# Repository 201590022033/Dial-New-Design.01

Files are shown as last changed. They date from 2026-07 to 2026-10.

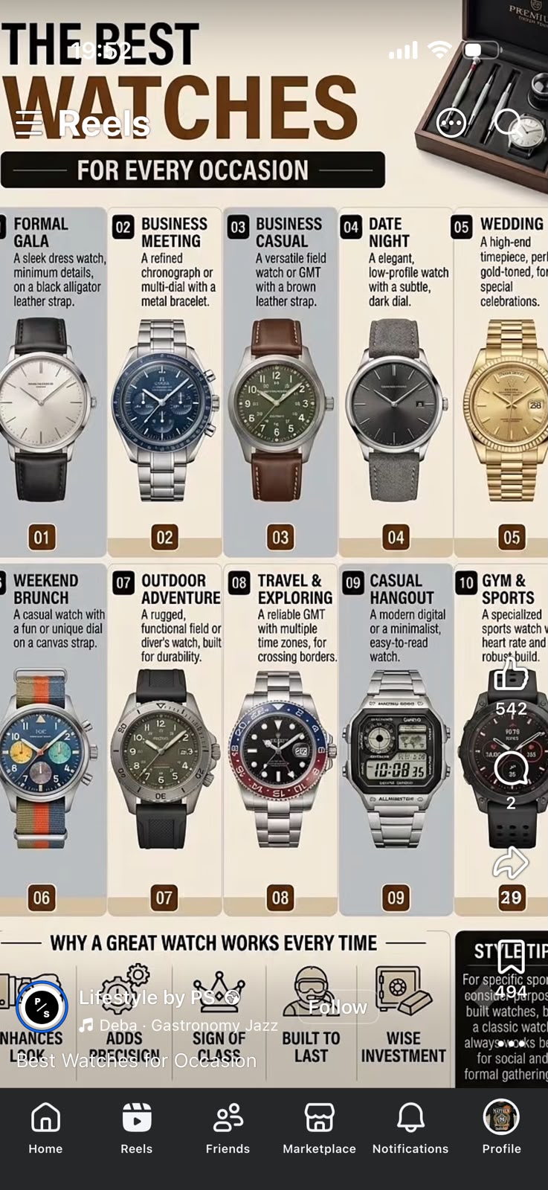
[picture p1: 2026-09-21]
docs/reference-components/2026-09-20-social-reference/WhatsApp Image 2026-09-20 at 14.32.59 (1).jpeg

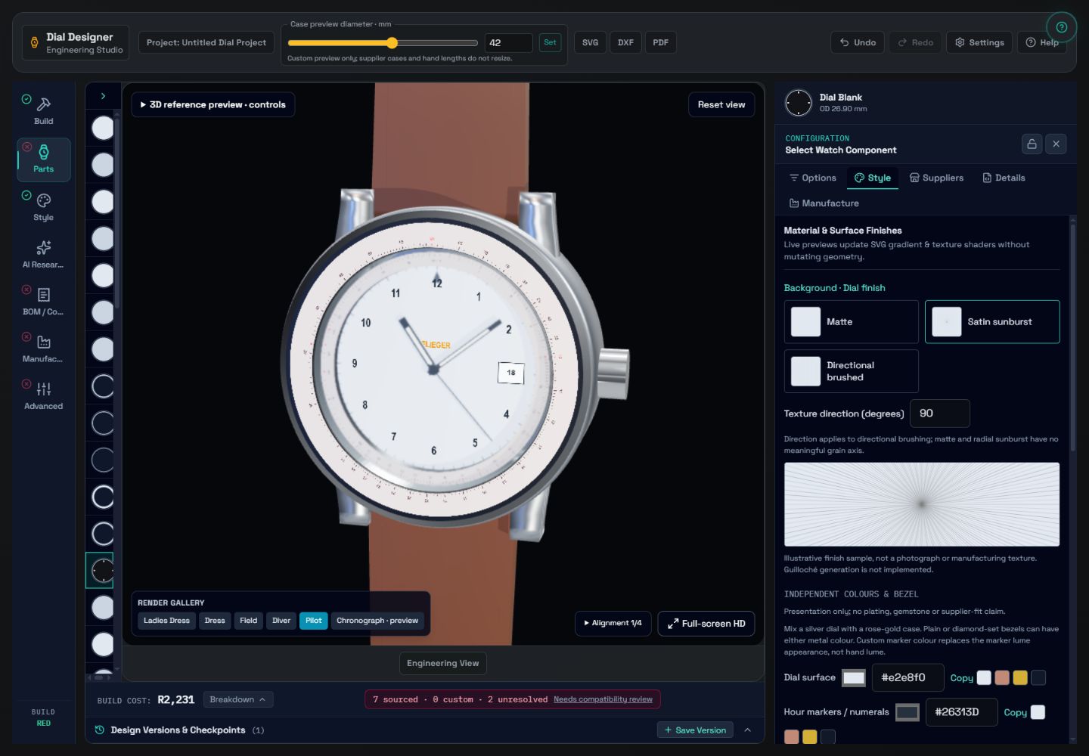
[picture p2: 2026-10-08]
docs/research/slide-rules/acceptance/m4-repair-hd-silver-2026-10-08.jpg

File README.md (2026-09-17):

# Dial Designer v0.3

## Version 3 – Professional Watch Engineering Studio

Production-ready engineering workspace for custom watch dial design with strict geometry, scale plugins, manufacturing validation, and export workflows.

## Stack

- React 19
- TypeScript (strict)
- Vite
- Tailwind CSS
- Zustand
- SVG.js
- React Hook Form + Zod
- Framer Motion
- React DnD
- Lucide React
- ESLint + Prettier

## Architecture Principles

1. Parametric geometry only.
2. Global case diameter is the master dimension.
3. Bands are concentric donuts.
4. Band Registry is the source of truth.
5. SVG is the authoritative renderer.
6. UI, rendering, and domain logic are separated.

## Production Features

- Watch Design Engine: dial face, texture, typography, marker, chapter ring, bezel, lume, template systems.
- Engineering Export Engine: SVG, DXF, PDF, PNG from engineering geometry.
- Export targets: entire project, dial face, chapter ring, inner bezel, outer bezel, selected band, manufacturing package.
- Export Preview: preview image, layers, dimensions, warnings, estimated process sizes, file size summary.
- Native project files: `.dial` (versioned, JSON-based) with autosave and recent project support.
- Manufacturing validation and collision detection integrated into inspector/status/export preview.
- Traceable manufacturing rules classify guidance as verified manufacturer capability, industry best practice, or engineering assumption.
- Supplier profile library provides data-driven manufacturing capability presets for print-, applied-, and instrument-oriented dial programs.
- Design Advisor highlights authenticity, geometry, beauty, and manufacturability recommendations from the current dial state.
- Movement recommendations for production-safe dial and bezel sizing guidance.

## Project Structure

- src/app: App composition and shell
- src/components/layout: Main layout regions
- src/features: Feature placeholders and extension surfaces
- src/stores: Zustand stores (global settings, selection, bands, history, viewport, export)
- src/renderer: SVG renderer abstraction + interaction services
- src/domain: Band registry, movement library, extension catalog
- src/services: Export and movement service layer
- src/hooks: Reusable hooks including resize observer and validation
- src/utils: Math and id utilities
- src/tests: Bootstrap tests

## Layout

- Top toolbar
- Left bands panel
- Center SVG canvas
- Right inspector and feature stack
- Bottom status bar

## Project Workflow

- New/Open/Save/Save As
- Import/Export project payloads
- Autosave snapshots
- Recent projects index
- Undo/Redo snapshot hooks
- Project information and settings dialog

## Run

```bash
npm install
npm run dev
```

## Quality Checks

```bash
npm run typecheck
npm run lint
npm run build
```

## Documentation

- [Architecture Guide](docs/ARCHITECTURE.md)
- [Developer Guide](docs/DEVELOPER_GUIDE.md)
- [Plugin Guide](docs/PLUGIN_GUIDE.md)
- [Manufacturing Guide](docs/MANUFACTURING_GUIDE.md)
- [Scale Guide](docs/SCALE_GUIDE.md)
- [Movement Guide](docs/MOVEMENT_GUIDE.md)
- [Project File Format](docs/PROJECT_FILE_FORMAT.md)
- [Watch Design Guidelines](WATCH_DESIGN_GUIDELINES.md)
- [Manufacturing Rules](MANUFACTURING_RULES.md)
- [Supplier Profile Library](SUPPLIER_PROFILE_LIBRARY.md)
- [Design Advisor](DESIGN_ADVISOR.md)
- [Asset Library Architecture](ASSET_LIBRARY_ARCHITECTURE.md)
- [Parametric 3D Roadmap](docs/ROADMAP.md)
- [ADR 0001: Parametric 3D Geometry](docs/adr/0001-parametric-3d-geometry.md)

## Current Status

- Core geometry, scale, design, export, and project persistence systems are operational.
- Strict TypeScript, linting, and tests are enforced.
- Manufacturing intelligence now includes traceable rules, supplier archetypes, and contextual design recommendations without redesigning the frozen architecture.
- Additional plugin surfaces are scaffolded for advanced watchmaking extensions.

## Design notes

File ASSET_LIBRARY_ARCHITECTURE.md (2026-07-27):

# Asset Library Architecture

## Version 3 Intent

Version 3 shifts differentiation from framework construction to professional watchmaking knowledge encoded as reusable assets.

The framework remains stable.

The asset libraries become the primary source of domain value.

## Frozen Systems

The following systems remain unchanged and are consumed as-is:

- Projection and profile infrastructure
- Mathematical engines
- Scale plugin framework
- Renderer and SVG pipeline
- Manufacturing validation framework
- Intelligent layout engine
- Export pipeline
- Watch component registry
- Object inspector architecture
- Zustand store architecture

## New Knowledge Layers

Data-driven libraries are stored in [src/domain/asset-library/data](src/domain/asset-library/data):

- scaleAssets.json
- chapterRingAssets.json
- markerAssets.json
- handAssets.json
- materialAssets.json
- typographyAssets.json
- manufacturingRules.json
- supplierProfiles.json

These datasets are loaded by typed adapters in [src/domain/asset-library/loaders.ts](src/domain/asset-library/loaders.ts).

## Integration Pattern

1. Asset data defines authentic watchmaking semantics.
2. Loaders expose typed objects to services.
3. Services map assets to existing framework contracts.
4. Existing stores and UI consume service outputs.
5. Export and validation report traceable manufacturing evidence.

No mathematical engine duplication is introduced.

## Manufacturing Intelligence Integration

Manufacturing rules and supplier profiles are separate from application logic.

Rules include:

- stable rule id
- source classification
- supplier category linkage
- confidence level
- configurable thresholds
- revision and version

Runtime validation attaches this metadata to warnings so exported diagnostics are explainable.

## Advisor Integration

The design advisor reads:

- current design-engine state
- manufacturing warnings
- typography presets
- supplier profiles

It emits actionable recommendations grouped across authenticity, geometry, manufacturability, and visual quality.

## Extensibility

Adding a new profile or asset should be data-first:

1. Add entry to the relevant JSON library.
2. Reuse existing loader and service interfaces.
3. Add tests for expected behavior.

Framework APIs should only change for verified defects.

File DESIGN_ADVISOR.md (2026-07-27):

# Design Advisor

## Mission

The Design Advisor acts as a professional engineering assistant built on top of the frozen framework.

It does not replace mathematical engines.

It interprets design state, asset metadata, and manufacturing warnings to provide contextual recommendations.

## Inputs

The advisor currently evaluates:

- selected scale characteristics,
- dial and chapter ring configuration,
- marker strategy,
- typography profile compatibility,
- manufacturing warning trace metadata,
- supplier profile capability data.

## Recommendation Classes

Recommendations are grouped by:

- authenticity,
- manufacturability,
- geometry,
- beauty.

Severity is communicated as info, opportunity, or warning.

## Example Behaviors

- Detects texture and dense-scale competition.
- Suggests chapter-ring width increases when typography is constrained.
- Flags typography below profile-specific printable minima.
- Advises when applied marker strategy mismatches supplier capability.
- Highlights multilayer risk for single-level supplier profiles.

## Why-first Output Style

Each recommendation should contain:

- what is wrong,
- why it matters,
- how to improve it.

The advisor should never degrade to unexplained pass/fail states.

## Data Coupling

Advisor quality depends on asset-library breadth:

- scale assets
- chapter ring assets
- marker assets
- hand assets
- material assets
- typography assets
- manufacturing rules
- supplier profiles

As those libraries grow, advisor recommendations become more specific without changing framework APIs.

## Future Growth

Next modules should add:

- hand-to-marker style compatibility scoring,
- logo complexity and process guidance,
- movement-aware complication placement,
- scale-family-specific authenticity scoring,
- supplier cost/volume trade-off suggestions.

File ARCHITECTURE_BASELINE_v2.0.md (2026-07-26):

# Architecture Baseline v2.0

## Status
Architecture Version: 2.0 Stable

Effective immediately, the platform architecture is frozen for feature development.

Changes to frozen systems are allowed only for verified defects.
No feature ECR may modify frozen internals.

## Frozen Systems
- Projection Engine
- Projection Registry
- Projection Profiles
- Formatter Engine
- General Mathematical Framework
- Slide Rule Engine
- Scale Plugin Framework
- Manufacturing Framework
- Collision Framework
- Intelligent Layout Framework
- Renderer
- SVG Pipeline
- Export Pipeline
- Watch Component Registry
- Object Inspector Framework
- Engineering Validation Engine
- Zustand Store Architecture

## Freeze Rules
- New functionality must be implemented by composition of Projection + Engineering Profile + Formatter.
- No feature work may add scale-specific mathematical engines inside plugins.
- Plugins are orchestration only.
- Renderer, export, manufacturing, and stores remain unchanged unless fixing a verified defect.

## Defect Exception Policy
A frozen subsystem may be changed only when all conditions are met:
1. A reproducible defect exists in current behavior.
2. The defect cannot be resolved in profile/formatter/preset composition.
3. The change is minimized and accompanied by targeted regression tests.

## Architectural Intent
This freeze formalizes the transition from platform construction to profile-library expansion.
New capabilities should be delivered by adding:
- Engineering profiles
- Optional icons/assets
- Documentation

Core engines remain stable.

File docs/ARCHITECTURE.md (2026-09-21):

# Architecture Guide

## Core Layers

1. Domain engines
- Geometry Engine: concentric constraints, dependency graph, validation categories.
- Scale Engine: plugin-driven tick/label generation and validation.
- Watch Design Engine: dial face, texture, typography, marker, chapter ring, bezel, lume, templates.

2. Stores (Zustand)
- Global settings, bands, scale, design engine, export, project, viewport, selection, history.

3. Renderer
- SVG renderer adapter with strict geometry-based rendering.
- Engineering overlays and scale overlays rendered from domain outputs.

4. Services
- Export service (engineering geometry to SVG/DXF/PDF/PNG).
- Project file service (.dial serialization/deserialization).
- Manufacturing and movement recommendation services.

## Extension Points

- Scale plugins through registry.
- Texture plugins through texture engine plugin list.
- Template presets via template library.
- Help documentation mappings via engineering help index.

## Parametric 3D boundary

`WatchAssembly` remains the application-level source of truth. The current
`src/visual3d` layer adapts that assembly to procedural or registry-backed GLB
visuals; it is not yet a production CAD generator. Future dimensional case and
hand variation belongs behind versioned parameter schemas and generator
contracts under `src/domain/geometry/parametric/`. Blender Python/bpy under
`tools/blender/` is the reference geometry environment. See [Roadmap](ROADMAP.md)
and [ADR 0001](adr/0001-parametric-3d-geometry.md).

### P4 componentized assembly

`WatchAssemblyPartInstance.visual` optionally binds a stable category, registry
asset ID and local transform. `parametricGeometry` optionally stores the versioned
case or crown parameter set. Both survive existing assembly serialization; old
documents remain readable. Catalogue kind identifies legacy parts independently
of editable names: broad `case` includes crystals, casebacks and lugs and must not
be used as a midcase selector. A draft midcase catalogue entry is appended without
reordering the existing 43 entries. It is excluded from engineering export.

The case owns `DD_CASE_CROWN_BOSS` and `DD_CASE_CROWN_TUBE`. The removable crown head
is a separate part using `parametric-crown/v1`, generated in `DD_PARAMETRIC_CROWN`.
Replacing/hiding it does not modify the case. Its local origin is the rear socket
entrance, with +X pointing outward. Parameters retain provisional provenance and
explicit unknown dimensions; a visual socket is not a certified threaded interface.

`VisualWatchModel` has case/dial/bezel/crystal/hands/crown descriptors, visibility,
local transforms and typed `watch-axis`, `dial-seat`, `hand-stack`, `crown-interface`
frames. Frames are absolute in engineering coordinates (mm, XY dial plane, +Z toward
crystal). Each carries provenance. `designConfig.assemblyAnchors` supplies explicit
frames. Otherwise the crown frame is derived from the supplied case tube endpoint:
`caseDiameter / 2 - crownTubeEmbed + crownTubeLength`; unresolved seats/stacks and
legacy crown placement remain labelled provisional. These preview values do not
write inferred manufacturing dimensions back to the assembly.

Transform order is anchor -> instance offset/XYZ Euler rotation -> descriptor
offset/XYZ Euler rotation/scale -> GLB axes and units. Crown `axialGapMm` adds along
the anchor's local +X before rotation; it is never baked into exported crown meshes.
Unknown gaps use zero only for a provisional schematic preview. The scene uses
0.1 scene units/mm once at the root, with no implicit scaling of GLBs by case size.
Blender glTF Y-up is converted back to engineering Z-up; descriptors may explicitly
declare Z-up or metre units.

Every supported category uses the same `VisualComponent` and `GlbAsset` loading
path. Missing, mismatched, malformed, loading, failed and meshless assets retain a
procedural component. Each failed boundary remounts when asset ID/path changes.
Loaded scenes are cloned per instance without disposing the shared loader cache.
Fallbacks receive assembly placement but not GLB-specific corrections. There is
one WebGL canvas with `frameloop="demand"`; 2D rendering/export stays independent.

P4 keeps one representative part per supported visual category; hands remain a
hand-set slot, not arbitrary per-hand animation or complication instances. Broad
catalogue support, parameter editors, verified movement clearances, collision/fit
checks, live Blender regeneration and the rest of the component library are later
milestones. Registry GLBs remain opt-in reviewed assets, not automatic generation.

### P7 surface finishes

`src/visual3d/finishProfiles.ts` registers independent procedural surface
profiles for case, bezel, crown, hands, dial, crystal, lume and metal variants.
The visual adapter resolves a category profile from authored asset metadata or
assembly material/texture hints, with a safe fallback. Procedural previews use
the same profile values; authored GLBs retain their own materials. P7 establishes
surface ownership and provisional provenance without inventing texture maps or
manufacturing surface specifications. Image textures, anisotropic brushing and
measured finish references remain later work.

### Fixed NMK901 reference selection

The opt-in 42 mm reference stores the case, crown and hand-set generator
parameters on independent assembly parts and binds three fixed GLBs by category.
It writes explicit frame provenance and survives serialization. A fixed asset
is used only while the complete fixture parameters and 42 mm diameter match;
changes fall back to procedural visuals. The 3D review panel surfaces the
specified NMK901 envelope, nominal movement/hand-fit evidence and unresolved
mechanical interfaces. The case boss/tube remain part of the case and the
removable crown remains a separate part. This visual selection does not certify
mechanical engagement or movement clearance; details are in [P7 NMK901 reference review](P7_NMK901_REFERENCE_REVIEW.md).

## Data Flow

1. Inspector/store update.
2. Domain engines regenerate outputs.
3. Geometry + manufacturing + collision validation update warnings.
4. Renderer updates SVG preview immediately.
5. Export consumes engineering geometry outputs (not preview snapshots).

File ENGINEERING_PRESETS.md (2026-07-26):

# Engineering Presets

This document defines the professional preset catalog built on the frozen v2.0 architecture.

Each preset is composition only:
Projection + Formatter + Engineering Profile.

## Classical Slide Rule

| Preset | Purpose | Projection | Formatter | Engineering Profile | Manufacturing Class | Compatible Rings | Typical Applications |
|---|---|---|---|---|---|---|---|
| C | Primary multiplication ring | logarithmic | slide-rule | C | precision | outer | multiplication, ratios |
| D | Companion multiplication ring | logarithmic | slide-rule | D | precision | inner, outer | division companion |
| CI | Reciprocal operations | reciprocal-logarithmic | slide-rule | CI | precision | inner, outer | reciprocal/division shortcuts |
| A | Square relationship support | logarithmic | slide-rule | A | scientific | outer | square roots, area |
| B | Companion to A | logarithmic | slide-rule | B | scientific | inner | multi-ring power operations |
| K | Cubic relationship support | logarithmic | slide-rule | K | scientific | outer | cube roots, volume |
| L | Linear-log display profile | natural-log | scientific | L | scientific | inner, outer | log reading |
| LL0 | Low-range log-log | log-log | scientific | LL0 | scientific | outer | small exponential growth |
| LL1 | Primary log-log | log-log | scientific | LL1 | scientific | inner, outer | compounding |
| LL2 | Mid-high log-log | log-log | scientific | LL2 | scientific | inner, outer | growth modeling |
| LL3 | High-range log-log | log-log | scientific | LL3 | scientific | outer | high exponent domains |

## Aviation (Navitimer)

| Preset | Purpose | Projection | Formatter | Engineering Profile | Manufacturing Class | Compatible Rings | Typical Applications |
|---|---|---|---|---|---|---|---|
| Fuel Consumption | Fuel planning | logarithmic | navitimer | fuel-consumption | aviation | inner, outer | endurance planning |
| Distance | Leg distance planning | logarithmic | navitimer | distance-planning | aviation | inner, outer | enroute distance/time |
| Ground Speed | Ground speed solving | logarithmic | slide-rule | ground-speed | aviation | inner, outer | GS, ETA |
| True Air Speed | TAS planning | logarithmic | slide-rule | true-air-speed | aviation | inner, outer | TAS corrections |
| Time | Time conversion | logarithmic | navitimer | time | aviation | inner, outer | elapsed time |
| Climb | Climb planning | logarithmic | scientific | climb | aviation | inner, outer | climb gradients |
| Descent | Descent planning | logarithmic | scientific | descent | aviation | inner, outer | descent profiles |
| Rate of Climb | RoC solving | logarithmic | scientific | rate-of-climb | aviation | outer | vertical speed checks |
| Wind Correction | Drift/wind solve | logarithmic | navitimer | wind-correction | aviation | inner, outer | wind triangle approximations |
| Conversion | Mixed aviation units | linear | decimal | conversion | industrial | outer | quick unit checks |
| Unit Conversion | Explicit unit conversion | linear | decimal | unit-conversion | industrial | outer | metric/imperial conversion |
| Fuel Burn | Burn-rate planning | logarithmic | navitimer | fuel-burn | aviation | inner, outer | reserves management |
| Holding Pattern | Hold timing | logarithmic | navitimer | holding-pattern | aviation | inner, outer | timed holds |
| Glide Ratio | Glide planning | logarithmic | scientific | glide-ratio | aviation | inner, outer | emergency glide |
| Cross-country Planning | Multi-leg planning | logarithmic | navitimer | cross-country-planning | aviation | inner, outer | route planning |

## General Engineering

| Preset | Purpose | Projection | Formatter | Engineering Profile | Manufacturing Class | Compatible Rings | Typical Applications |
|---|---|---|---|---|---|---|---|
| Metric Conversion | Metric conversion | linear | decimal | metric-conversion | industrial | outer | SI workflow |
| Imperial Conversion | Imperial conversion | linear | decimal | imperial-conversion | industrial | outer | legacy imperial workflow |
| Length | Length scaling | linear | decimal | length | general | outer | dimensional checks |
| Mass | Mass scaling | linear | decimal | mass | general | outer | payload/mass checks |
| Pressure | Pressure scaling | logarithmic | engineering | pressure | industrial | inner, outer | instrumentation |
| Temperature | Temperature conversion | linear | decimal | temperature | general | outer | process checks |
| Velocity | Velocity scaling | logarithmic | engineering | velocity | general | inner, outer | speed conversion |
| Power | Power scaling | logarithmic | engineering | power | industrial | inner, outer | efficiency analysis |
| Torque | Torque conversion | logarithmic | engineering | torque | industrial | inner, outer | mechanical setup |
| Mechanical Advantage | Leverage profile | logarithmic | engineering | mechanical-advantage | general | inner, outer | leverage estimation |
| Ratio | Ratio operations | logarithmic | slide-rule | ratio | general | inner, outer | comparative scaling |
| Proportion | Proportion solving | logarithmic | slide-rule | proportion | general | inner, outer | cross-multiplication |

## Scientific Families

| Preset | Purpose | Projection | Formatter | Engineering Profile | Manufacturing Class | Compatible Rings | Typical Applications |
|---|---|---|---|---|---|---|---|
| Scientific | Scientific readability | logarithmic | scientific | scientific | scientific | inner, outer | scientific instrumentation |
| Engineering | Engineering readability | logarithmic | engineering | engineering | general | inner, outer | field engineering |
| Navigation | Navigation readability | logarithmic | navitimer | navigation | aviation | inner, outer | heading/nav workflows |
| Physics | Physics domains | logarithmic | scientific | physics | scientific | inner, outer | constants and scaling |
| Chemistry | Chemistry domains | logarithmic | scientific | chemistry | scientific | inner, outer | concentration/ratio work |
| Mathematics | Math-focused profile | logarithmic | engineering | mathematics | scientific | inner, outer | analytic estimation |

## Architecture Guarantee
Adding a new engineering preset requires:
1. New profile entry
2. Optional UI icon
3. Documentation updates

It does not require changes to projection engine, renderer, plugin registry, formatter engine, or manufacturing engine.

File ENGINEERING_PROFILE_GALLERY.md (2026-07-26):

# Engineering Profile Gallery

Each row documents a profile-ready rendered example target in the studio.

Legend:
- Manufacturing Score: target quality class (`A` high precision, `B` production-ready, `C` general use)
- Validation Status: expected as `Pass` when generated with defaults

| Scale | Projection | Formatter | Profile | Purpose | Manufacturing Score | Validation Status |
|---|---|---|---|---|---|---|
| C | logarithmic | slide-rule | C | Primary multiplication ring | A | Pass |
| D | logarithmic | slide-rule | D | Companion multiplication ring | A | Pass |
| CI | reciprocal-logarithmic | slide-rule | CI | Reciprocal operations | A | Pass |
| A | logarithmic | slide-rule | A | Two-decade square support | A | Pass |
| B | logarithmic | slide-rule | B | Two-decade companion | A | Pass |
| K | logarithmic | slide-rule | K | Three-decade cubic support | A | Pass |
| L | natural-log | scientific | L | Linear-log profile | B | Pass |
| LL0 | log-log | scientific | LL0 | Low-range exponential | B | Pass |
| LL1 | log-log | scientific | LL1 | Primary log-log | B | Pass |
| LL2 | log-log | scientific | LL2 | Mid-high log-log | B | Pass |
| LL3 | log-log | scientific | LL3 | High-range log-log | B | Pass |
| Fuel Consumption | logarithmic | navitimer | fuel-consumption | Fuel planning | A | Pass |
| Distance | logarithmic | navitimer | distance-planning | Leg planning | A | Pass |
| Ground Speed | logarithmic | slide-rule | ground-speed | Ground speed solving | A | Pass |
| True Air Speed | logarithmic | slide-rule | true-air-speed | TAS solving | A | Pass |
| Time | logarithmic | navitimer | time | Time conversion | A | Pass |
| Climb | logarithmic | scientific | climb | Climb planning | A | Pass |
| Descent | logarithmic | scientific | descent | Descent planning | A | Pass |
| Rate of Climb | logarithmic | scientific | rate-of-climb | Vertical speed planning | A | Pass |
| Wind Correction | logarithmic | navitimer | wind-correction | Drift correction | A | Pass |
| Conversion | linear | decimal | conversion | Mixed unit conversion | B | Pass |
| Unit Conversion | linear | decimal | unit-conversion | Explicit unit conversion | B | Pass |
| Fuel Burn | logarithmic | navitimer | fuel-burn | Burn-rate planning | A | Pass |
| Holding Pattern | logarithmic | navitimer | holding-pattern | Holding workflows | A | Pass |
| Glide Ratio | logarithmic | scientific | glide-ratio | Glide planning | A | Pass |
| Cross-country Planning | logarithmic | navitimer | cross-country-planning | Multi-leg planning | A | Pass |
| Metric Conversion | linear | decimal | metric-conversion | SI conversion | B | Pass |
| Imperial Conversion | linear | decimal | imperial-conversion | Imperial conversion | B | Pass |
| Length | linear | decimal | length | Length scaling | B | Pass |
| Mass | linear | decimal | mass | Mass scaling | B | Pass |
| Pressure | logarithmic | engineering | pressure | Pressure scaling | B | Pass |
| Temperature | linear | decimal | temperature | Temperature conversion | B | Pass |
| Velocity | logarithmic | engineering | velocity | Velocity scaling | B | Pass |
| Power | logarithmic | engineering | power | Power scaling | B | Pass |
| Torque | logarithmic | engineering | torque | Torque scaling | B | Pass |
| Mechanical Advantage | logarithmic | engineering | mechanical-advantage | Leverage solving | B | Pass |
| Ratio | logarithmic | slide-rule | ratio | Ratio workflows | B | Pass |
| Proportion | logarithmic | slide-rule | proportion | Proportion solving | B | Pass |
| Scientific | logarithmic | scientific | scientific | Scientific readability | A | Pass |
| Engineering | logarithmic | engineering | engineering | Engineering readability | A | Pass |
| Navigation | logarithmic | navitimer | navigation | Navigation readability | A | Pass |
| Physics | logarithmic | scientific | physics | Physics domains | A | Pass |
| Chemistry | logarithmic | scientific | chemistry | Chemistry domains | A | Pass |
| Mathematics | logarithmic | engineering | mathematics | Mathematical estimation | A | Pass |
| Navitimer Baseline | logarithmic | navitimer | navitimer | Generic aviation baseline | A | Pass |
| Aviation Baseline | logarithmic | slide-rule | aviation | Generic aviation baseline | A | Pass |
| Custom | custom | custom | custom | User-defined profile | C | Pass |

## Verification Notes
- Gallery entries use existing projection, formatter, and profile composition.
- No renderer, export, registry, or core manufacturing engine changes are required.
- New profiles can be added by extending profile definitions and documentation only.

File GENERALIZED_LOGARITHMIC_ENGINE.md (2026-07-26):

# Generalized Logarithmic Engine

## Overview
This document describes the generalized logarithmic scale architecture introduced in ECR-012.

Goals:
- Keep logarithmic mathematics domain-driven.
- Support one or more decades without hardcoded single-decade loops.
- Separate placement math from display formatting.
- Reuse the same engine for scientific and aviation-oriented ring profiles.

## Architecture Layers

### 1. Domain Mathematics
Inputs:
- Domain Start (`startValue`)
- Domain End (`endValue`)
- Logarithmic Base (`logarithmicBase`)
- Direction (`direction`)
- Rotation (`rotationOffsetDeg`)
- Number of Decades (`logarithmicDecades`, optional clamp)

Responsibilities:
- Validate positive, increasing logarithmic domain.
- Compute base-aware normalized domain bounds.
- Resolve decade range for generation.

Reference:
- `src/domain/scales/framework/logarithmicDomainEngine.ts`
- `src/domain/scales/framework/circularLogarithmicMath.ts`

### 2. Tick Generation
Responsibilities:
- Generate primary/secondary/tertiary/micro ticks over intersecting decade intervals.
- Respect density profile and explicit density controls.
- Operate across arbitrary domain span (single decade, multi-decade, sub-decade).

Properties:
- `tickDensityProfile`
- `logMajorTickDensity`
- `logMinorTickDensity`
- `logMicroTickDensity`
- `tickDirection`
- `majorTickLengthMm`, `minorTickLengthMm`
- `majorTickWidthMm`, `minorTickWidthMm`

Reference:
- `src/domain/scales/framework/logarithmicTickEngine.ts`

### 3. Label Formatting
Responsibilities:
- Convert numeric tick values into display strings.
- Keep formatting independent from geometric placement.

Formats:
- Engineering
- Scientific
- Navitimer
- Slide Rule
- Custom

Styles:
- Value
- Mantissa
- Scientific

Properties:
- `logarithmicDisplayMultiplier`
- `logarithmicDisplayFormat`
- `logarithmicLabelStyle`
- `labelFrequency`
- `includeMinorLabels`

Reference:
- `src/domain/scales/framework/logarithmicDisplayFormatter.ts`
- `src/domain/scales/framework/logarithmicLabelEngine.ts`

### 4. Presentation Layer
Responsibilities:
- Use ticks + labels + metadata only.
- Perform no logarithmic math in renderer.

Reference:
- `src/services/scaleEngineService.ts`
- `src/components/layout/CentreCanvas.tsx`
- `src/renderer/svgRenderer.ts`

## Normalization
Given base `b`, start `s`, end `e`, value `v`:

- `normalized = (log_b(v) - log_b(s)) / (log_b(e) - log_b(s))`
- `angle = projection(normalized, direction, startAngleDeg, endAngleDeg, rotationOffsetDeg)`

This is invariant across display formatter choices.

## Decade Generation Strategy
- Resolve decade span intersecting domain.
- For each decade interval, generate primary and subdivision ticks.
- Filter by domain bounds and sort by angle.
- Deduplicate by value+tier key.

No hardcoded `for i = 1..9` domain assumption remains in control flow.

## Engineering Assumptions
- Domain values are strictly positive for logarithmic projection.
- `logarithmicBase > 1`.
- Presets tune density/readability but do not alter foundational normalization.

## Extension Strategy
Future ring profiles are configuration profiles over this engine:
- C, D, CI, DI
- A, B, K, L, LL
- Aviation slide-rule profiles
- Custom domain/formatter profiles

Ring profile intent is encoded via configuration (`logarithmicRingType`), not by duplicating math engines.

## Future Slide-Rule Compatibility
The generalized logarithmic domain/tick/label layers are reusable inputs for coupled-ring slide-rule plugins.
Renderer and export flows remain unchanged.

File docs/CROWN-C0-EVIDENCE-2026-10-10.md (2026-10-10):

# C0 evidence freeze and reproducible baselines

Reviewed 10 October 2026, Africa/Johannesburg. Production baseline: main `6931131420adb5606323f8c8db54dc4c76604f8d`, tracking origin/main. C0 and C1 are human-approved; C2 onward, publication and scheduler activation are not. Existing planning files remain untracked and preserved.

## Evidence records

The complete binary/node/hash inventory is in `CROWN-C0-ASSET-INVENTORY-2026-10-09.md`. Supplier records and additional movement evidence are in `CROWN-C0-SUPPLIER-EVIDENCE-2026-10-10.md`. Neither document certifies physical interchangeability.

### NH05B primary-source revision resolution

Downloaded the official [TMI NH05 specification pack](https://www.timemodule.com/upload/category/21/spec_sheet/NH05_SS.pdf) and [technical guide](https://www.timemodule.com/upload/category/21/technical_guide/NH05_TG.pdf) on 9 October 2026 at approximately 21:42-21:46 SAST, then inspected complete rendered pages. The PDF text is scanned; dimensions below were read visually. Original PDFs and selected page renders are retained in `docs/research/crown-c0-2026-10-10/`.

| Field | Evidence | Confidence / boundary |
| --- | --- | --- |
| Exact movement revision | Specification cover: NH05B, revised 27092024; TG cover NH05B/06B, 20122024 | Manufacturer drawing, revision-specific; does not resolve unspecified generic NH05 sellers |
| Stem reference | Spec PDF page 7, Hand Setting Stem v2: 0351 247; TG PDF page 7 / printed page 6, parts catalogue v2: 0351 247 | Confirmed in two primary-source pages |
| A | 571, units 1 = 1/100 mm; thus 5.71 mm | Drawing value, not final trimmed case length; drawing tolerance A +/-10 in source units |
| B | 1244.5, same units; thus 12.445 mm | Drawing reference extent, not final trimmed case length |
| Crown-side thread designation | Literal `S90P22.5` on stem drawing | Preserve literal designation and source units; no seller Tap-based equivalence or undocumented thread conversion |
| Other drawing features | 50 MAX; collar diameter 110 with +0/-0.6; neck diameter 58 with +0/-2; tip diameter 40 with +0/-1.2, in source units | Retain the complete page; these are distinct features, not a single universal socket diameter |
| Case tube, crown socket, gasket, final stem length | Unknown for aftermarket 34 mm case | Movement documentation cannot establish case-owned interfaces |

Spec PDF SHA256: `7ab2b1515745389682d09a9f9fbeccfc9f8a199b344e6231ec19f5ee7fea1716`.
TG PDF SHA256: `4abe35ec2bc40cf008793e16b0c40e09f0fda8a0682bff595a3e023e522482ab`.

The earlier generic supplier 351-420 claim is not adopted for NH05B. It remains an unresolved generic-NH05 seller/revision claim. No production movement or supplier record was changed.

## Baseline fixture procedure

Started a temporary Vite instance on `http://localhost:3017` from the actual repository. This unused origin showed zero checkpoints and disabled Undo before interaction. The pre-existing localhost:3000 and 127.0.0.1:3000 origins were observed only and were not edited. Main was the sole browser operator.

1. Load Diver starter through Build. Capture Engineering front.
2. Open Visual, expand controls, load 42 mm reference set, choose Face, collapse controls. Capture HD front.
3. Drag the watch by +300 horizontal pixels for the opposite side, then -600 for the operating-crown side. Capture both side views.
4. Switch to Engineering and capture the same 42 mm reference assembly.
5. Load Ladies Dress starter through Build (34 mm). In Visual choose Face and collapse controls, capture front. Drag -300 horizontal pixels, capture crown side. Switch to Engineering and capture front.

Screenshots are actual browser captures at 1280 x 720, retained under `docs/research/crown-c0-2026-10-10/`. They document existing behavior; no GLB regeneration or crown fix occurred in C0.

| File | SHA256 |
| --- | --- |
| diver-engineering-front.jpg | `f00ece44fbe4e868e0e6860f21ec4fa5c422d4530c11c6e9566167a2b96e07e5` |
| reference42-engineering-front.jpg | `9d0ecdff44819907298aab75a3055c578dcf444f0caf06c97ccab82bc5dd1eac` |
| reference42-hd-front.jpg | `4e28e87f81788b8ba8c59c24a0a222153860a06dbfe8343dddfa020c5306ba2f` |
| reference42-hd-side.jpg | `c23ab6499426aa0c7a76038d17f9b63e4d34ef8fffa39dfc4112d2e57fc1b1d4` |
| reference42-hd-crown-side.jpg | `61fa8e48790b32e048c08968f9d0e47e6331409e6b8d46cdfd16de74b22279a5` |
| ladies34-engineering-front.jpg | `1ab3dee75f4c4ca52190137da342aacf07954148c4d64fdb0cf25eecca3cb75e` |
| ladies34-hd-front.jpg | `0b11014dc7e69708d2ab32bf43c59de8745e0e141153d1f5030443dde1980bd5` |
| ladies34-hd-crown-side.jpg | `dbfd2c2890bfb5b4116ab1a07ce849ca933e64cdde303991c1db8887f6208fe5` |

Engineering currently displays a front dial/artwork canvas and does not expose a side/crown view. Therefore an Engineering side screenshot cannot be honestly captured at this baseline; HD side screenshots plus digital-mesh bounds cover that baseline observation. This is a named existing limitation, not a C0 implementation failure or new functionality claim. The full all-profile interaction/visual acceptance matrix remains C6 scope.

Reference HD front visibly shows the fluted head. Ladies HD shows compact crown presentation; screenshots alone cannot prove absence of overlapping duplicate geometry. The binary inventory establishes embedded ownership risk. Engineering and HD dial presentations are different existing adapters; C0 does not claim crown geometry agreement from the 2D canvas.

## Contract inputs and unresolved measurement gates

- Priority agreed: explicit saved choice, supplied case crown, evidence-backed platform recommendation, then provisional archetype styling. C1 represents choice/default separately; C2 implements resolution.
- Retain core OD separately from maximum grip envelope: reference 7 + 2 x 0.2 = 7.4 mm. Legacy geometry is preserved verbatim.
- Movement owns stem identity/revision; case owns tube/boss/guards; removable operating head has one owner per axis. Cap/holder requires explicit matched assembly ownership.
- Numeric clockwise angle from 3h must retain supplier wording and evidence independently. Supplier 3.8/4/4.1/4.2 are separate claims. Unknown exact NMK920 angle remains unknown.
- Unknown stem/socket/tube/closure/gasket/installation dimensions are legal contract states and never a fit pass. Case drawings limited to outer envelopes do not qualify hidden interfaces.
- Canonical axes must be explicitly authored and take precedence over competing legacy crown transforms. Documents without them retain their existing saved anchors and rendering behavior.

C0 automated baseline: `npm test -- src/tests/parametricContracts.test.ts src/tests/visualWatchAdapter.test.ts src/tests/watchAssemblyArchitecture.test.ts src/tests/visualAssetRegistry.test.ts` passed 4 files / 55 tests on 10 October 2026 at 01:32 SAST. These are pre-C1 checks of existing behavior, not verification of new implementation. `git diff --check` passed for tracked changes (new untracked documents require separate whitespace checks).

C0 gate COMPLETE on 10 October 2026 after reconciliation of the supplier lane, asset inventory, primary NH05B pages and actual isolated browser baselines. Proceed to approved C1 with explicit unknowns and the documented Engineering-view limitation; no procurement qualification depends on invented values. No C2/C3 work is authorized by this gate.

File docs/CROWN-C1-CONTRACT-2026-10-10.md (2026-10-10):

# C1 crown contract and migration handoff

Completed 10 October 2026 after the C0 evidence gate. This freezes additive contracts for subsequent C2/C3 work; it does not implement crown controls, defaults, procurement qualification or replacement GLBs.

## Public contract

The public entry point is `src/domain/crown/index.ts`. `types.ts` declares `crown-spec/v1`, `crown-axis/v1` and `crown-choice/v1`; `validation.ts`, `axis.ts` and `legacy.ts` provide assertions, conversions and explicit reversible migration.

- `CrownSpecificationV1` separates shape and grip, core diameter and maximum grip envelope, axial length, closure, protection and finish. Finish explicitly inherits the case or overrides material/color/texture.
- Physical interfaces are independent: movement stem identity/revision/thread, crown socket, case-tube engagement/gaskets and matched cap/holder mechanism. Installation retains movement rotation/stem height/spacer, dial feet/rotation, calendar aperture/date-wheel orientation and front/rear loading.
- Each evidential field is either unknown with a reason or known with a source and evidence kind. Supplier wording is preserved independently from measured numeric values. Schema validity is never a mechanical-fit or sealing certificate.
- The operating head belongs to the crown; tube, boss and fixed guards belong to the case. Caps, holders and extraction levers have explicit ownership and require matched assembly identity where applicable.
- `CrownChoiceV1` keeps selected instance/source separate from a catalogue recommendation. C1 never applies a recommendation automatically.

Optional metadata lives on assembly parts (`crownAxes`, `crownSpecification`), catalogue entries and `designConfig.crownChoice`. A visual binding can reference `crownAxisId`. No existing catalogue entry is silently upgraded.

## Placement source and coordinates

The case part owns the numeric axis. `axisId` references are unique across an assembly; every operating head on an authored axis is counted, including hidden and legacy heads. Serialization rejects duplicate owners, missing references and contradictory case/crown visual categories. Known catalogue kinds take priority over visual labels when validating ownership.

Clockwise angle is measured from front-view 3h, in degrees `[0,360)`. In the runtime Engineering/Blender frame, the face is XY, +Z points toward the crystal and +X is 3h. For angle theta, interface radius r and stem height h:

`position = [r*cos(theta), -r*sin(theta), h]`, `rotation = [0, 0, -theta]`.

`crownAxisToExportedAssetFrame` is explicitly for exported Y-up assets: position `[x,z,-y]`, rotation `[0,-theta,0]`. It is not a second runtime conversion; the existing GLB loader restores the Engineering frame.

An explicitly declared modern axis overrides saved legacy anchors, visual angles and tube endpoints. Legacy visual transforms remain in storage but are inactive for canonical placement. Unknown modern coordinates omit the operating crown instead of inventing placement. Without modern metadata, the original saved-anchor > tube endpoint > visual-angle precedence is unchanged.

The document can preserve multiple case axes and heads. The existing visual model has one crown slot, so multiple declared axes intentionally omit that slot until later renderer work supports them. C1 does not claim multiple-crown rendering or an Engineering side viewport.

## Migration matrix

| Input | C1 behavior | Preserved or unknown |
| --- | --- | --- |
| Old assembly or `.dial` document without crown contracts | Load/save remains opt-out; no automatic migration | IDs, explicit choices, supplier/source metadata, anchors, transforms and geometry retained |
| Explicit `migrateLegacyCrown` call | Returns new specification plus a deep original snapshot | `restoreLegacyCrown` restores the complete snapshot; no in-place mutation |
| Legacy parametric 7 mm core and 0.2 mm radial grip | Core 7 mm, maximum envelope 7.4 mm | Original dimensions remain verbatim |
| Legacy nominal dimensions without grip geometry | Nominal core/head length retained as presentation evidence | Maximum envelope unknown |
| Missing legacy closure | Known `unspecified`, with legacy provenance | No push-pull or screw-down inference |
| Legacy visual socket/thread fields | Original snapshot retained | Physical stem/socket/tube/thread and gasket fit remain unknown |
| Legacy appearance | Explicit material/color/texture override | Appearance retained; inheritance available for new authored data |
| Unknown physical evidence | Legal persisted contract state | Validation reports unknown, never fit verified |
| Invalid dimensions/IDs, conflicting ownership or references | Reject at assembly and embedded `.dial` boundaries | Runtime hydration rejects before store mutation |

## Verification and scope

Current full-suite result: 101 files / 826 tests passed, including 26 crown contract tests and 14 assembly integration tests. Coverage includes clockwise fixtures, exported coordinates, invalid dimensions, padded identity rejection, reversible migration, unknown evidence, ownership, modern precedence, legacy preservation, hidden duplicate heads, multiple-axis persistence and invalid hydration refusal.

Production build includes `tsc -b`; final lint/build/whitespace results are recorded in the live ledger. Existing Three.js CommonJS deprecation warnings are unrelated to this slice.

C0 sources and limitations remain in `CROWN-C0-EVIDENCE-2026-10-10.md`, the asset inventory, supplier evidence ledger and `docs/research/crown-c0-2026-10-10/`. Unknown exact case angles and mating interfaces remain unknown. No source GLB was rewritten. The missing reference asset path, embedded head suppression, appearance meshes, Apply/default rules, BOM and off-axis platform implementation remain subsequent milestones.

Next implementation gate: separately authorize C2 and/or C3 against these frozen contracts. Changes remain uncommitted; the continuation scheduler stays paused.

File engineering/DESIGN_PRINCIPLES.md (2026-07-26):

# Dial Designer Design Principles

## Principle 1

The watch is always the primary focus.

The interface exists to support the watch, never compete with it.

---

## Principle 2

Users edit physical watch components.

The software should think in terms of:

Bezel

Outer Slide Rule

Inner Slide Rule

Chapter Ring

Minute Track

Hour Markers

Dial Face

Logo

Hands

Complications

rather than software concepts such as:

Typography

Textures

Colours

Geometry

These are properties.

Not navigation categories.

---

## Principle 3

The interface follows the order a real watch is designed.

Template

↓

Watch Structure

↓

Select Component

↓

Modify Component

↓

Validate

↓

Export

---

## Principle 4

Object selection drives the interface.

Whenever a watch component is selected,

every editable property belonging to that component appears together.

Users should never search for controls elsewhere.

---

## Principle 5

Rendering

Geometry

Scale Mathematics

Plugin Architecture

Band Registry

remain independent from UI.

Never tightly couple UI to engineering engines.

---

## Principle 6

Dial Designer should feel closer to

Affinity Designer

Adobe Illustrator

Figma

than traditional mechanical CAD.

Professional.

Minimal.

Focused.

Calm.

---

## Principle 7

The watch occupies visual priority.

The eye should naturally focus on the watch before surrounding controls.

---

## Principle 8

Engineering complexity remains hidden until required.

Beginners should never feel overwhelmed.

Experts should always have access to advanced functionality.

---

## Principle 9

Engineering Change Requests extend architecture.

Avoid replacing working systems.

Prefer additive improvements.

---

## Principle 10

Every completed Engineering Change Request must successfully pass:

npm run typecheck

npm run lint

npm run test

npm run build

before completion.

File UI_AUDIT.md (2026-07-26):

# UI Audit

ECR: ECR-RECOVERY-002 — Finalize Workspace Architecture

## Audit Table

| Item | Present | Verified | File | Comments |
|---|---|---|---|---|
| Toolbar | Yes | Yes | src/components/layout/TopToolbar.tsx | Compact navigation-only header, fixed-height contract in app shell. |
| Workflow | Yes | Yes | src/components/layout/LeftBandsPanel.tsx | Guided workflow sections in required order. |
| Canvas | Yes | Yes | src/components/layout/CentreCanvas.tsx | Centre rendering surface mounted and occupying centre column. |
| Inspector | Yes | Yes | src/components/layout/RightInspector.tsx | Object-centric editor panel remains right column. |
| Status Bar | Yes | Yes | src/components/layout/BottomStatusBar.tsx | Persistent bottom engineering telemetry/status. |
| Zoom | Yes | Yes | src/components/layout/CentreCanvas.tsx | Wheel zoom and toolbar zoom readout are active. |
| Pan | Yes | Yes | src/components/layout/CentreCanvas.tsx | Shift/middle-drag panning behavior present. |
| Presentation Mode | Yes | Yes | src/components/layout/TopToolbar.tsx | Presentation toggle exposed and wired to app shell state. |
| Recommendations | Yes | Yes | src/components/layout/LeftBandsPanel.tsx | Workspace Recommendations section is present and actionable. |
| Watch Structure | Yes | Yes | src/components/layout/LeftBandsPanel.tsx | Watch Structure section is present and selectable. |
| Validation | Yes | Yes | src/components/layout/LeftBandsPanel.tsx | Validation section present with geometry/manufacturing/collision/scale status. |
| Export | Yes | Yes | src/components/layout/LeftBandsPanel.tsx | Export section with target and format actions present. |
| Engineering Help | Yes | Yes | src/components/layout/LeftBandsPanel.tsx | Engineering Help links present in final workflow section. |

## Geometry/Layout Contract Verification
- TopToolbar.bottom < Workspace.top: enforced by geometric runtime contract checks in app shell.
- Workspace.bottom > StatusBar.top: enforced by geometric runtime contract checks in app shell.
- Canvas.clientHeight > minimum: enforced by geometric runtime contract checks in app shell.
- Three columns exist simultaneously: enforced by geometric runtime contract checks in app shell.
- No vertical overlap: enforced by geometric runtime contract checks in app shell.
- No clipping: enforced by geometric runtime contract checks in app shell.

Reference: src/app/App.tsx

## Notes
- Audit scope is UI architecture and composition verification.
- No engineering subsystem rewrites were performed.

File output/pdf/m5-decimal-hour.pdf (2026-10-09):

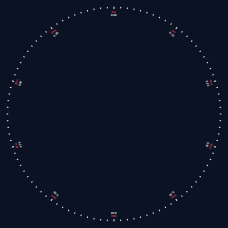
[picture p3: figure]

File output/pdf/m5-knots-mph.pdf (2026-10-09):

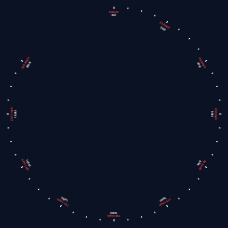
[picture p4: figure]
0.0mph; 20kt 23.0mph 40kt 46.0mph; 69.0mph; 80kt 92.1mph 100kt 115.1mph; 207.1mph; 230.2mph 200kt

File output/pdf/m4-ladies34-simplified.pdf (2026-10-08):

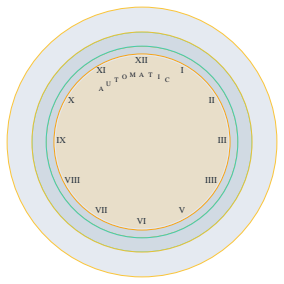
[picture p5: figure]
XII; III; IIII; VI VII; VIII

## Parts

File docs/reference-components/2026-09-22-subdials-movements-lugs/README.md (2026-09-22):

# Subdial, movement and lug visual references

These three user-supplied social-media captures are retained as visual taxonomy references only. They are useful for naming design families, but they are not dimensional drawings, supplier evidence or manufacturing approval.

| File | What it contributes | Engineering boundary |
|---|---|---|
| `watch-subdials.jpeg` | Ten complication-display families | A movement must explicitly support a role before the designer can render or order it. |
| `watch-movements.jpeg` | NH35, NH36, NH38, Miyota 8215 and Miyota 9015 comparison prompt | Manufacturer documentation remains authoritative. These pictured movements do not gain subdials. |
| `watch-lugs.jpeg` | Ten visual lug families | Lug style changes case geometry and needs a separate measured platform fixture. |

The first implemented movement-specific slice is TMI VK63: 9 h chronograph-minute counter, 6 h small seconds and 3 h 24-hour indicator. TMI's official drawing now supplies 7.50 mm register centres and post diameters. Register artwork radius and hand silhouettes remain `ESTIMATED_NOMINAL` until supplier drawings and physical samples are reviewed.

Primary technical sources:

- [TMI VK product family](https://www.timemodule.com/en/product_line_up/quartz/chronograph/premium_chronograph_VK/)
- [TMI VK63 technical guide](https://www.timemodule.com/uploads/attachments/download/Technical%20Guide/VK63_TG.pdf)
- [Miyota 8215](https://miyotamovement.com/product/8215/)
- [Miyota 9015](https://miyotamovement.com/product/9015/)

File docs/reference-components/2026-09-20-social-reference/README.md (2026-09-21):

# Watch reference component audit — 2026-09-20

This folder contains the 17 supplied WhatsApp screenshots as visual reference
material. They are inspiration and taxonomy evidence only; they are not
dimensional, supplier, manufacturing, or brand-authenticity evidence.

## Audit result

| Reference area | Current coverage | Audit result |
| --- | --- | --- |
| Hand styles | `src/domain/asset-library/data/handAssets.json` | Strong coverage: baton, dauphine, sword, Mercedes, snowflake, cathedral, broad arrow, leaf, alpha, pencil and syringe are represented. Add Breguet, obelisque, Louis XV, fleur-de-lys, teardrop, lollipop and skeleton as explicit styles. |
| Index / marker styles | `markerAssets.json` | Partial coverage: baton, Arabic, Roman/Breguet, applied, sword, syringe, cathedral, broad arrow, round, rectangle, triangle and maxi exist. Add stick, dot, square, baguette, painted, combination and a dedicated numeral family. |
| Dial finishes / textures | `materialAssets.json` | Good coverage: matte, sunburst, brushed, enamel, guilloche, meteorite, mother-of-pearl and fume exist. Add explicit field, minimalist, stone, skeleton/open-work, lacquered black, panda/sector and radial-grain presentation labels. |
| Chapter rings | `chapterRingAssets.json` | Broad structural coverage: printed, engraved, applied, recessed, sandwich, stepped, coin-edge, fluted, pilot, dive, dress and military exist. These should remain separate from bezel families. |
| Bezel families | No dedicated reference taxonomy | Add smooth, fluted, coin-edge, engine-turned, dive, GMT-24-hour, tachymeter and gem-set bezel references. Do not overload chapter-ring IDs. |
| Lume families | No first-class reference taxonomy | Add Super-LumiNova, Tritium H3, Chromalight, LumiBrite, electroluminescent/Indiglo, historic radium, zinc sulfide, C1, BGW9 and X1 as appearance/material references with provenance and safety notes. |
| Complications | Movement library covers selected movement behavior only | Add presentation archetypes for date, day-date, GMT, chronograph, moonphase, power reserve, annual calendar, perpetual calendar, world time, alarm, dual time and tourbillon. Keep mechanism/fit claims separate. |
| Watch archetypes | No dedicated archetype reference taxonomy | Add dress/formal, business, field, pilot, dive, GMT/travel, chronograph, digital, sports, wedding/evening and casual archetypes. Archetype should be a composition label, not a manufacturing constraint. |
| Exploded assemblies | Screenshot references only | Useful for naming case, crystal, bezel, dial, hands, movement, crown, gaskets, bracelet and spring-bar components. Do not infer hidden geometry or dimensions from the illustrations. |

## Accuracy notes

- The supplied graphics are social-media infographics and several are AI-like
  or brand-stylized. They are suitable for option discovery, not for declaring
  a style historically correct or a component dimensionally accurate.
- `Broad Arrow` is the existing project spelling; the supplied image labels the
  same family as `Arrow`.
- `Breguet` appears both as a hand family and as a numeral/index treatment;
  those should remain separate records.
- `Chronograph`, `GMT`, `date`, `day-date`, and similar labels describe visible
  complication layouts. Movement compatibility still comes from the movement
  library and evidence gate.
- Lume names such as Chromalight and LumiBrite are brand/proprietary labels;
  they should be stored with provenance rather than treated as interchangeable
  physical materials.

## Recommended implementation order

1. Add reference-only data for lume families, bezel families, complications and
   watch archetypes.
2. Extend marker and hand data with the missing styles above, preserving current
   IDs and adding aliases where names differ.
3. Add reference links to the relevant configurator options and render profiles.
4. Keep all records marked `reference` or `provisional` until a technical or
   supplier source supports a production claim.

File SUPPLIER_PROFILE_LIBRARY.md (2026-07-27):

# Supplier Profile Library

## Scope

Supplier capabilities are modeled as editable data assets, not hard-coded logic.

Profiles are stored in [src/domain/asset-library/data/supplierProfiles.json](src/domain/asset-library/data/supplierProfiles.json).

## Current Supplier Archetypes

- Balanced Prototyping Studio
- Precision Applied Index House
- Instrument Print Specialist
- Micro Batch Artisan Dial

These represent supplier categories and regional capability patterns rather than direct endorsements of a single vendor.

## Profile Fields

Each profile defines:

- region,
- supported manufacturing methods,
- supported materials,
- finishing capabilities,
- dimensional tolerances,
- minimum line widths,
- minimum font sizes,
- multilayer capability,
- applied-index capability,
- recommended production volume,
- notes,
- references,
- evidence classification,
- color limitations.

## Integration

Profiles are loaded through:

- [src/domain/manufacturing/supplierProfiles.ts](src/domain/manufacturing/supplierProfiles.ts)

And consumed by:

- [src/domain/manufacturing/validationEngine.ts](src/domain/manufacturing/validationEngine.ts)
- [src/services/designAdvisorService.ts](src/services/designAdvisorService.ts)
- [src/services/manufacturingSuiteService.ts](src/services/manufacturingSuiteService.ts)

## Selection Strategy

The advisor uses profile-aware heuristics:

- Dense professional scales prefer instrument-print capabilities.
- Applied furniture prefers applied-index specialist capabilities.
- Baseline work defaults to balanced prototyping profiles.

## Extension Workflow

To add a new supplier profile:

1. Add a profile entry to the JSON data file.
2. Provide source-category references and evidence classification.
3. Validate thresholds through existing tests.
4. Avoid changing frozen framework contracts.

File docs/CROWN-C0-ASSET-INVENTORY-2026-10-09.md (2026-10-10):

# C0 crown asset and axis inventory

Inspected 9 October 2026. Repository `C:/Users/Deon/Documents/GitHub/Dial-New-Design.01`, main HEAD `6931131420adb5606323f8c8db54dc4c76604f8d`. Read the four planning documents and live ledger; the ledger records C0 approval followed by C1. This bounded inventory changes documentation only. No applicable AGENTS.md was found in the repository or searched workspace parent trees. No browser, supplier research, production edits, generation, application tests, commits or pushes performed.

## Method and coordinates

Decoded actual GLB JSON and binary POSITION accessors, composed node TRS/matrices along active-scene hierarchy, and bounded every transformed vertex. Values below are millimetres in exported GLB Y-up coordinates, before application placement or scene scaling (MM_TO_SCENE = 0.1). Thus Blender (x,y,z) exports as (x,z,-y); the case face occupies XZ and thickness occupies Y. Values rounded to 0.001 mm below describe digital meshes, not measurement accuracy. Scratch inspection script is retained under the projectless workspace `work/c0-inventory/inspect.py` and uses only Python standard libraries.

## Eight removable embedded preview heads

All eight contain exactly one node named `DD_CASE_CROWN_PREVIEW`, index 0, with provisional-presentation extras. The generator creates this node as a separate cylinder (diameter 5.8 mm above 36 mm case OD, otherwise 4.2 mm; axial length 3.2 mm), rotates it onto +X and places its centre at caseDiameter/2 + 1.4. The actual binary bounds agree. These are removable presentation heads, not structural tubes/bosses/guards. Each asset ID below maps to catalogue ID `cat-` plus that asset ID, and path `public/assets/3d/variants/cases/<asset ID>.glb`.

| Exact asset ID | Transformed minimum XYZ | Transformed maximum XYZ | SHA256 |
| --- | --- | --- | --- |
| case-feiyashi-samurai-438 | (21.700,-2.900,-2.900) | (24.900,2.900,2.900) | `a3e7a65412d2905a690c85a496a804e632585ddb7c18e88600d19cbb6062185e` |
| case-namoki-nmk920-tuna-47 | (23.300,-2.900,-2.900) | (26.500,2.900,2.900) | `9c1953a15a347058de58fb44d6b66796417b884a415d864b592d09e5802a087b` |
| case-nh05-ladies-dress-34 | (16.800,-2.100,-2.100) | (20.000,2.100,2.100) | `0fdfd8fe2e4d550eae0b8a19e32fbbbe24cdafe556ede224890381a738c129cf` |
| case-tandorio-bronze-diver-44 | (21.800,-2.900,-2.900) | (25.000,2.900,2.900) | `e7cd4fdf50df3b26aa02b847878ce1e047eb00a9d1d9d2b703228a675beae4d5` |
| case-tandorio-nh05-research-34 | (16.800,-2.100,-2.100) | (20.000,2.100,2.100) | `de31d496ba6636d17719e9be802f5e8a8adbad20632edd186b9223478cc0d1c4` |
| case-tandorio-pilot-40 | (19.900,-2.900,-2.900) | (23.100,2.900,2.900) | `ce2cd4305dfdf6678983c12fe3efe1ab587ba764fb641efedf41d70880b682a7` |
| case-tandorio-willard-41 | (20.300,-2.900,-2.900) | (23.500,2.900,2.900) | `9c4e3b99b5698b8e2027a631498702412c2ea50474311ef0c4c752ee4275507b` |
| case-wr-skx-sandblasted-42 | (20.800,-2.900,-2.900) | (24.000,2.900,2.900) | `3d04571f9152933e0e93195954dc0388f30282da487411b0d5e73585656986d4` |

Preserve `DD_CASE_MIDCASE`, `DD_CASE_FLOOR`, and four lugs `DD_CASE_LUG_1_1`, `DD_CASE_LUG_1_-1`, `DD_CASE_LUG_-1_1`, `DD_CASE_LUG_-1_-1` in every listed asset. Also preserve `DD_CASE_FACETED_SHOULDER` in Samurai/Willard, `DD_CASE_TURTLE_SHOULDER` in bronze diver, and `DD_CASE_TUNA_SHROUD` in NMK920. These eight binaries contain no separately named crown tube/boss/guards; that absence does not certify the physical case interface. Future suppression must target the exact reviewed head only and use source hashes to detect asset changes.

The ninth variant `case-namoki-nmk903-black-38` has no preview head. SHA256 `21506d16844076426628988965c996391b9fdd6b3a1d0222f20fa8ad62e1ebe4`. Preserve structural nodes `DD_CASE_CROWN_GUARD` (index 0; min (12.408,-2.350,9.821), max (16.588,2.150,13.800)) and `DD_CASE_CROWN_GUARD.001` (index 1; min (15.404,-2.350,4.982), max (19.551,2.150,8.319)). The generator explicitly removes its generic preview head before adding these two guards. Broad CROWN-name deletion would remove legitimate structure.

## Reference assets and legacy core/envelope

`public/assets/3d/reference-42/crown.glb` exists, SHA256 `8a0717da056a9a747e130853160b6b91c29ce8fed35c29e66688b2a224e09207`. Single node `DD_CROWN_HEAD`, index 0; transformed min (0,-3.7,-3.7), max (4.9,3.7,3.7). Binary extras retain parametric-crown/v1: headDiameterMm 7, gripDepthMm 0.2, gripCount 32, headLengthMm 4.9, socketDiameterMm 3.2, socketDepthMm 1.8, attachment axialGapMm 0, and explicitly unknown stemThreadPitchMm. Provenance says visual review fixture only, not measured/manufacturing approved. The generator formula adds grip radially; 7 mm core means 7.4 mm maximum envelope. Preserve this meaning in migration.

`public/assets/3d/reference-42/case.glb` SHA256 `9c09e94c5370812ec380c5bfd267bae2ab58b08bcb82f022b839ff98f38f4feb`. Preserve `DD_CASE_CROWN_BOSS` index 0, bounds (18.8,-2.1,-2.1) to (20.3,2.1,2.1), and `DD_CASE_CROWN_TUBE` index 1, bounds (19.5,-1.75,-1.75) to (21.8,1.75,1.75). These belong to the case, while the reference crown is a separate removable asset. Preserve midcase and four named 6/12 o'clock lugs too.

`src/visual3d/visualAssetRegistry.ts` registers `reference-42-crown-preview` at the existing reference file. It also registers `crown-reference-v1` at `/assets/3d/generated/crowns/crown-v1.glb`; direct filesystem existence check returned false. Inventory does not fix or retire that missing entry.

## Current axis precedence and NMK920 discrepancy

`src/visual3d/assemblyAnchors.ts` currently resolves:

1. Default crown at (case radius,0,0), zero rotation, provisional schematic placement.
2. Case customProperties.visualCrownAngleDeg, only when no valid parametric tube endpoint exists. Position (r cos a,r sin a,0), rotation (0,0,a) in engineering/Blender convention; negative angles move clockwise from 3h toward 4h.
3. Valid parametric-case/v1 tube endpoint overrides the angle: (caseDiameter/2 - crownTubeEmbed + crownTubeLength,0,0), zero rotation.
4. Valid saved designConfig.assemblyAnchors override the preceding results last.

`applyCatalogueVisualSelection.ts` copies visual.crownAngleDeg to customProperties.visualCrownAngleDeg. `movementLibrary.ts` supports only coarse stemPosition '3h'/'4h'/'9h'. These are existing contracts, not an exact axis or installation certification.

`tools/blender/generate_component_variant_library.py` defines NMK920 as 47 mm OD, 11.3 mm thick, 22 mm lugs, 46.5 mm lug-to-lug, shape tuna; generic build_case places its head centre at (24.9,0,0), i.e. 3h. Actual binary confirms it. Shroud bounds are (-23.5,-2.862,-23.5) to (23.5,2.562,23.5); midcase bounds (-23.5,-3.503,-23.5) to (23.5,3.503,23.5). Neither binary nor catalogue establishes the actual supplier crown angle. Catalogue text/tags assert a dimension drawing, but this repository inventory does not recover or validate that source. Do not promote the generic 3h mesh to supplier evidence.

## Limits and handoff

This completes the bounded binary/node inventory. It does not complete the entire C0 gate: actual baseline front/side Engineering/HD screenshots, manufacturer drawing/revision checks, supplier package contents and physical interface evidence remain coordinator-owned. No physical stem/thread/closure/sealing values were inferred. C1 should freeze explicit axis precedence and core/envelope/ownership semantics while preserving saved anchors and legacy data; C3/C7 later own mesh changes under separate approval.

Changed repository file: this new inventory only. Verification: read-only GLB decoding and bounds inspection, source searches, HEAD/status and missing-path check. No application test claim is made.

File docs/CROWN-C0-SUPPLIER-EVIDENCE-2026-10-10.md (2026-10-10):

# C0 manufacturer and supplier evidence

Checked 10 October 2026, approximately 01:28-01:32 Africa/Johannesburg (23:28-23:32 UTC on 9 October). Bounded C0 research only; no production catalogue/supplier records, contacts, quotes, purchases or code changed. NH05B manufacturer inspection belongs to the coordinator and is not repeated here. PDF skill used: manufacturer covers, stem drawings and relevant parts-list pages rendered with Poppler and visually inspected. Sources and rendered pages retained durably in `docs/research/crown-c0-2026-10-10/supplier-sources/`; manifests retain exact UTC fetch timestamps, URLs and SHA256. These hashes pin retrieved bytes, not supplier promises about future deliveries.

## Movement-side stem evidence

| Exact manufacturer revision | Visually inspected pages (PDF, one-based) | Stem evidence |
| --- | --- | --- |
| [TMI NH35A specification](https://www.timemodule.com/upload/category/24/spec_sheet/NH35_SS.pdf), cover revised 16112022 | Cover 1; Hand Setting Stem 7, version 1 | Part 0351 200; A=1100, B=2148; drawing unit 1=1/100 mm, hence A=11.00 mm and B=21.48 mm. Original thread designation S90xP22.5 retained. |
| [TMI NH34A specification](https://www.timemodule.com/upload/category/23/spec_sheet/NH34_SS.pdf), cover revised 13062025 | Cover 1; Hand Setting Stem 7, version 1 | Part 0351 200; same A/B and thread designation as above. Shared manufacturer reference does not establish interchangeable finished case crowns or trimmed lengths. |
| [TMI VK63A specification](https://www.timemodule.com/upload/category/33/spec_sheet/VK63_SS.pdf), cover revised 14122021 | Cover 1; Hand Setting Stem 6, version 1 | Type A, Part 0351 177; A=1371, B=1969, C=40 MAX; unit 1=1/100 mm, hence 13.71 mm,19.69 mm,0.40 mm maximum. Original thread designation S90 P22.5 retained. |

The S90/P22.5 designations correspond to nominal 0.90 mm/0.225 mm in the drawing's stated units; retain the original S designation rather than rewriting it as an ISO metric thread or generic seller Tap number. Manufacturer stem dimensions do not specify the separate case tube thread or crown-to-tube engagement, gasket envelope or finished trimmed length.

Visual parts-list cross-checks: [NH35A](https://www.timemodule.com/upload/category/24/parts_list/NH35_PL.pdf) page 1, dated 29082024, lists 0351 200; [NH34A](https://www.timemodule.com/upload/category/23/parts_list/NH34_PL.pdf) page 2, dated 29082024, lists 0351 200; [VK63A](https://www.timemodule.com/upload/category/33/parts_list/VK63_PL.pdf) page 2, dated 29072022, lists 0351 177. Drawings are full untrimmed component datums; exact delivered stem revision/length still requires package confirmation or measurement.

| Retrieved PDF | SHA256 |
| --- | --- |
| NH35_SS.pdf | `ef1a20e566691b887d1de947de0fe3786bddba2e5084055f7632831a261a748d` |
| NH34_SS.pdf | `1f9917c2d3495896637354934efc657dd7c0da60eaf07054d49afee3a85b12df` |
| VK63_SS.pdf | `45ca75e4e674c445675665e7a7f2a84fb33a0e908f7afed4d12f2906887758df` |
| NH35_PL.pdf | `bb9629cc348b2a87c5b4760aab69f8f72affd052c03fcfdf729d6837e2697d55` |
| NH34_PL.pdf | `4f1adde999933be1f359102255dc87876a0f9063c2193e06bc404c3726448f3a` |
| VK63_PL.pdf | `a41a4a25c5abba774bad700d31674e884f6172c692aaa32ee449f0dfbf5e821e` |

## Package contents and default priority

I=included by supplier text; E=explicitly excluded; O=optional/variant-dependent; U=unknown/not explicitly established. Absence from a list is U, never E. A product photo does not establish a sealed final crown, tube, or stem length. No E entries were established in this bounded pass.

| Exact package and source | Usable stem | Temporary crown | Final crown | Tube | Gaskets | Cap/holder | Pushers |
| --- | --- | --- | --- | --- | --- | --- | --- |
| [NH35A movement](https://www.namokimods.com/products/seiko-sii-nh35a-automatic-movement), factory SKU50015 variant32919303127074; regulated SKU50043 variant32919303159842 | I; length/revision U | U | U | U | U | U | U |
| [NH34A GMT movement](https://www.namokimods.com/products/seiko-sii-nh34a-gmt-automatic-movement), SKU50132 variant42005654110383 | I; length/revision U | U | U | U | U | U | U |
| [VK63 black movement](https://www.namokimods.com/products/seiko-sii-vk63-mechaquartz-watch-movement-black), SKU50182 variant44818246009007 | I; length/revision U | U | U | U | U | U | U |
| [SKX knurled sandblasted crown](https://www.namokimods.com/products/skx-knurled-crown-sandblasted-finish), SKU60012 variant31951367634978 | I; requires trimming | U | I, screw-down | U | I, supplier says triple gasket | U | U |
| [NMK932 steel field bundle](https://www.namokimods.com/products/nmk932-field-watch-case-bundle-steel-finish), SKU NMK932-PL variant41538355298479 | U | U | I, SKX013 coin-edge; closure U in package text | U | I, crystal/caseback | U | U |
| [NMK950 steel W10 pilot](https://www.namokimods.com/products/nmk950-pilot-tonneau-case-steel-finish), SKU NMK950-PL variant43070053875887 | U | U | I, matching sterile; closure U in technical text | U | I, caseback | U | U |
| [NMK955 steel VK case](https://www.namokimods.com/products/nmk955-vk-chronograph-case-steel-finish), silver chapter SKU NMK955-SL variant44818242240687; brushed NMK955-BR variant44818242306223 | U | U | I, matching sterile screw-down | U | I, caseback | U | I, distinct chronograph pushers |
| [Tandorio34 NH05 case](https://tandoriowatch.com/products/34mm-nh05-watch-case-bezel-insert-ring-sapphire-glass), e.g. 5-Case Bezel SKU1005010408335296-5-Case Bezel variant50684933996829 | U | U | O, screw-in | U | U | U | U |
| NMK920 exact candidate below | U | U | I; closure U in listing technical text | U | I, crystal/caseback | U | U |
| Tandorio46.5 black exact candidate below | U | U | I by product feature claim, screw-down; no enumerated packing list | U | U | U | U |

Supplier text establishes a stem in all three movement packages; VK63 also supplies a battery. It does not establish a final wearable crown in those movement packages. The separately sold SKX crown is not automatically the crown supplied with every Namoki case. NMK932 includes a separate sapphire crystal, NMK950 a top-hat crystal and integrated rehaut, NMK955 a boxed crystal, caseback and VK spacer. NMK955's page conflicts on dial range (29.5-31.5 versus30.5-31.5 mm); preserve that uncertainty. Tandorio34 labels its package list optional, so do not silently assign its stated screw-in crown to every selectable variant.

Contract priority for C1/C2 remains explicit saved choice, selected exact case/bundle supplied crown, evidence-supported platform recommendation, then provisional archetype styling. The above case examples are source evidence, not automatic onboarding or proof they match existing starter geometry. Unknown contents stay unknown; included parts must later avoid duplicate BOM charges without subtracting the case bundle price.

## Two exact Tuna candidates

### Existing Namoki NMK920 brushed listing

[Product](https://www.namokimods.com/products/nmk920-tuna-skx007-srpd-watch-case-brushed-finish); [read-only product JSON](https://www.namokimods.com/products/nmk920-tuna-skx007-srpd-watch-case-brushed-finish.js). Variant40465538744495, live SKU NMK920-PL, SGD195.00, available=false and product says sold out. Repository SKU NMK920-BRUSHED differs; do not create a duplicate identity or silently equate the strings. Current source image filename says PolishedFinish despite brushed listing title, another identity ambiguity. Supplier states 47 mm including shroud,46.5 mm lug-to-lug,11.3 mm without caseback,22 mm lugs; includes bezel,crown,two22 mm springbars,bezel click spring,crystal and caseback gaskets. Exact crown angle, tube thread/stem height/trim/engagement remain U. Listing shipping promotion is free or discounted express determined at checkout; SA amount,taxes/import and delivery eligibility U. No ZAR conversion made.

Recovered and visually inspected the repository's [old dimension image](https://cdn.shopify.com/s/files/1/0139/0434/7193/files/image_393d712f-eeae-4b1e-8028-3f021f774d1b_600x600.png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), SHA256 `dbc2a56f11e4275362015611ca38fb1c547796426262b66efbc82ba68261a0fe`. It is an actual external-envelope sketch labelled47,22,46.5 with an off-axis crown, no revision/part identifier/angle/hidden interface dimensions. Current product JSON has one product photo and does not reference this older image. Confidence: supplier-hosted external-envelope drawing consistent with dimensions; exact current SKU linkage unresolved. Downgrade existing broad dimensioned-drawing claims accordingly. It cannot certify the baked generic3h crown, a precise4h angle, tube geometry or manufacturing fit.

### Tandorio46.5 black4h listing

[Product](https://tandoriowatch.com/products/tuna-can-watch-case-46-5mm); [read-only JSON](https://tandoriowatch.com/products/tuna-can-watch-case-46-5mm.js). Exact black variant50602694836509, SKU1005010072446013-black, USD60.90. JSON available=true; rendered page labels variant sold out. Preserve stock as conflicting/unconfirmed. Compare-at USD44.10 is below current price and page reverses regular/sale order; do not calculate a discount. Supplier states46.5 mm OD,15.4 mm thick,22 mm strap,27-29 mm dial,4 o'clock screw-down crown and sapphire. Compatibility/20ATM claims are supplier statements only. No genuine hidden-interface drawing recovered; numeric stem height,tube thread,gasket/cap geometry and calendar installation fit U. Do not relabel as46 mm or combine with NMK920 shroud dimensions. General free-shipping-over-USD50 wording does not establish SA shipping: destination eligibility,amount,taxes/import U. No ZAR conversion made.

## Supplier snapshot hashes

JSON snapshots retrieved via public read-only endpoints, same product path plus `.js`; exact URLs/times also in manifests. These support variant identity and contents, not physical certification.

| Snapshot | SHA256 |
| --- | --- |
| nmk920.json | `3082cb684ebd9a7d109c83a2e6bf4f79efdce8032ff64ca19c0753fe37b8a58b` |
| tandorio465.json | `81f4f61fe0ebd0926f240bb2defb6cc6dcdf265dead95c144331628b75317cbb` |
| nh35-package.json | `0a5ae49af9b061ef7259830c8dfce1257ff7db2f17d7d5bc0e9cf0fc47c2f22e` |
| nh34-package.json | `eff9c0d5d295357f6161c715f09d907da2bd68729a43161f5d97aea9a81e9285` |
| vk63-package.json | `c1017b06ab83db2ae84efe6b4eb490ce42e212ef396b02a3543f74d787f4580b` |
| skx-crown.json | `4082f538f7fbcc9b48466f36e72dd1b67d94231643331a13377072e57eb2e631` |
| nmk932.json | `f7344b68d2deec30c36882ed0738bd5b9807f0876c3c1a5cc143d1de921a4ffd` |
| nmk950.json | `b6f8d97f1ef8c877d71efad7b36fcf18578d588fb80516b8cd4c99cac8a90464` |
| nmk955.json | `71e68b38f3abe12547da360c33bcd2634c645c735bb466bf1a5387ab9e5cdb42` |
| nh05-case.json | `d12c50d20f768ad536cb3990798731656b814baf496f68956ec20af834fde573` |

## Gate and remaining unknowns

Manufacturer stem identities/drawing datums for NH35A,NH34A,VK63A are pinned. C1 may represent these as sourced movement-side data while keeping separate crown socket/tube/closure/installation evidence unknown. No universal compatibility follows from shared stem designation. C0 permits provisional styling with disclosed missing supplier interfaces; physical fit/orderability remains unqualified. Main owns NH05B reconciliation and actual browser baselines. No tests run because this lane changes documentation only; no prior test count is claimed as new verification.

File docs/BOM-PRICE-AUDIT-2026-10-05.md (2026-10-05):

# NH05 BOM audit — 5 October 2026

Inspected the local NH05 dress configuration through the browser. The default assembly contains multiple crystal and strap alternatives plus engineering placeholders. Their presence does not mean all should be purchased. Procurement choices now retain one item per slot, grey excluded alternatives and exclude their price/shipping from totals. They do not alter the rendered watch or certify fit. The separate engineering-details list is collapsed and explicitly is not another charge list.

## Source snapshots

| Component | Supplier option | Item price | Evidence / limit |
| --- | --- | --- | --- |
| NH05 movement | Sofly SEIKO / Date 3, quantity 1–2 | USD75 | Selected options and single-unit tier inspected. Stem advertised included. Delivered revision/authenticity/stock unverified. |
| Rose-coloured case candidate | Tandorio 16-case / 50684934586653 | USD75.52 | Earlier 5 October snapshot. 34mm / 12mm headline envelope differs from 10.5mm preview. Colour photo inference, not a plating specification. |
| White dial alternative | Tandorio NO.1 / 50672056467741 | USD13.28 | Selected option inspected. 24.5mm matte white; NOT a champagne, silver-sunburst or rose-coloured dial. Printing extra. |
| RoseGold main hand alternative | Tandorio 50004173685021 | USD9.08 per three-hand set | Selected option inspected. 5/8/8mm centre-to-tip lengths, not the longer preview hands. Bores, pipes and clearances unverified. |

New supplier checks recorded at 2026-10-05T10:09:16+02:00. Rand conversion retains the explicitly dated 27 September snapshot, USD/ZAR16.3007. South-African shipping remains unknown, never zero. No purchase or supplier contact occurred. Sofly and Tandorio directory entries are candidates, not approved vendors.

Sources:

- https://www.soflypart.com/product/seiko-nh05-mechanical-movement/
- https://tandoriowatch.com/products/34mm-nh05-watch-case-bezel-insert-ring-sapphire-glass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
- https://tandoriowatch.com/products/24-5mm-watch-dial-nh05-white-matte-dial?variant=50672056467741
- https://tandoriowatch.com/products/nh05-hands-silver-blue-black-gold-rosegold-watch-hands-green-luminous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

## Still unresolved

- Exact champagne/sunburst/rose dial, gem-set bezel, caseback, crown, chapter ring and strap SKUs for this particular case. Engineering or visual colour selections are not supplier products.
- Which crystal/caseback/crown is included in each case package. Confirm contents before pricing separate purchases; do not infer an included part is free or double-buy it.
- Crystal seat/gasket/axial clearance and delivered NH05 holder/stem geometry. The pre-existing SKX-size crystals, chapter ring and rotating bezel prices are not fit approval for a 34mm NH05 case.
- Typography, date apertures, marker layouts and complication placeholders are engineering entries, not necessarily separately purchasable items. No independent price is fabricated.

The white dial and shorter luminous hands are explicit, manual-only budget alternatives. Selecting prices alone does NOT switch the Engineering/HD assets. The new **Apply to watch** button in the small breakdown and BOM panel explicitly replaces the component, focuses its right-hand Options, updates both renderers and retains the selected quote. Mapped alternatives use their researched GLBs, not the unrelated original preview. The rose case applies the provisional 34/12mm envelope; rose hands apply all three 5/8/8mm central hands. Crystal alternatives replace the canonical crystal slot and hide competing crystal geometry. Physical locks, known mismatches and research-only records cannot be bypassed. Unknown fit is never promoted to verified. Engineering hand rendering now shares the HD model's selected lengths instead of fixed 10.2/13.6/14.2mm tips. Existing GLBs are reused; no new assets are generated.

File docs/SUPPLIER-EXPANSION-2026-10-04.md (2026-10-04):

# Supplier expansion - 4 October 2026

Five separate research candidates are registered in the catalogue and supplier store. No extra supplier account/onboarding is required. Search their product names in Parts; supplier records include direct URLs, item-price snapshots and missing evidence.

| Candidate | Item price (SGD) | Evidence / limitations |
| --- | ---: | --- |
| Namoki NMK903 PVD Black SKX013 | 88 | 38mm OD, 44.5mm lug-to-lug, 10mm thickness, 20mm lugs; internal interfaces unknown |
| Namoki SKX slim sapphire back | 48 | 1.2mm thickness, grey NH spacer variant; thread and OD unknown, research-only |
| Namoki SKX slim brushed solid back | 25 | 0.8mm thickness, grey NH spacer; thread and OD unknown, research-only |
| Namoki 108 Sector silver sunburst dial | 39 | 28.5mm OD, four removable feet; thickness/feet coordinates unknown |
| Namoki NH36A Arabic White Factory Standard 4H | 125 | TMI base drawing; seller-specific pinion type and delivered stock unchecked, research-only |

All offers are unverified. Shipping to South Africa remains NULL (unknown), never zero. No delivered-price or assembled-water-resistance claim is made. Native prices convert through the application's existing, separately dated FX snapshot; that conversion is indicative, not a newly verified exchange rate. Stock purchase controls and backorder text conflict, so stock is unknown pending exact checkout confirmation. No purchase or supplier contact was made.

## Sources

- https://www.namokimods.com/products/nmk903-skx013-watch-case-pvd-black-finish
- https://www.namokimods.com/products/skx-slim-sapphire-caseback?variant=40519290716335
- https://www.namokimods.com/products/skx-slim-caseback-brushed-finish
- https://www.namokimods.com/products/watch-dial-108-minimal-tool-dial-sunburst-silver
- https://www.namokimods.com/products/seiko-sii-nh36a-automatic-movement-arabic-white
- https://www.timemodule.com/upload/category/25/spec_sheet/NH36_SS.pdf

The manufacturer PDF was downloaded and visually inspected (cover, Casing, Hand Fitting). Cover gives NH36A body diameter 27.40mm, spacer diameter 29.36mm and movement height 5.32mm. Casing distinguishes Type M/L axial envelopes; do not equate movement body height with assembled hand clearance. Do not infer a seller's exact pinion type from a base-calibre PDF.

Case and dial use generic procedural previews, not supplier-exact GLBs or sector artwork. Casebacks and movement are discovery-only until dimensions and a supported assembly workflow are complete; preview/apply rejects them rather than applying unknown zero-diameter values or replacing a case with a movement. No Blender assets changed in this batch.

## Next evidence gates

1. Obtain caseback OD, thread diameter/pitch, gasket seat and rotor clearance for a matched case family.
2. Obtain dial thickness, foot coordinates and exact artwork/date aperture dimensions.
3. Confirm movement SKU, day-wheel orientation and pinion type against the TMI drawing, then wire a dedicated physical movement selector.

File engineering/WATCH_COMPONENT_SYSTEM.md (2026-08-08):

# Watch Component System

## Geometry Ownership

The physical assembly is the single authority for radial geometry. It is derived from visible structural bands by `src/domain/assembly/physicalAssembly.ts`.

Only these objects own radial regions:

- Dial face
- Chapter ring
- Inner bezel
- Outer bezel

Their order is physical and center-out. `zIndex` controls paint order only and must never determine geometry, validation neighbors, or component containment.

Generators own artwork and style, not boundaries. Chapter markings, scales, indices, typography, and textures receive their usable region from the physical assembly. Project files persist structural bands as the canonical geometry; runtime hydration derives generator radii from those bands.

## Placeholder Integration

A placeholder becomes functional by attaching to an existing physical region. It does not become another concentric band unless it introduces a real manufactured radial boundary.

1. Keep its definition in the watch component registry.
2. Resolve its `linkedBandKind` through `resolveAttachmentRegion`.
3. Store component-local dimensions such as angle, offset, thickness, aperture size, or hand length on the component.
4. Generate artwork or manufacturing geometry within the resolved region.
5. Validate containment against that region and collisions against sibling attachments.
6. Export the component with its attachment metadata.

Examples:

- Hands, indices, text, logos, and complications attach to the dial-face region.
- Scales attach to the chapter-ring region and fall back to the dial face when no chapter ring exists.
- Crowns, pushers, lugs, and caseback metadata attach to the outer-bezel/case region but do not consume radial dial space.
- Crystals attach to the dial opening and use axial profile dimensions rather than creating a radial layer.

## Architecture

The Professional Watch Component System is an additive registry/store layer whose geometry attachments resolve through the physical assembly.

Primary modules:

- src/domain/watch-components/types.ts
- src/domain/watch-components/registry.ts
- src/domain/watch-components/factory.ts
- src/stores/watchComponentStore.ts

This keeps geometry/rendering/validation/export engines aligned while introducing first-class component objects for hands, indices, text, apertures, rings, case, and external hardware.

## Extension Points

- Add new component kinds in the watch component registry.
- Add process defaults through manufacturing metadata in factory.
- Add inspector behavior via schema IDs prefixed as watch-*.

## Engineering Decisions

- Components are additive object entities, not independent radial bands.
- Inspector remains object-centric and routes watch-* schema IDs through a complete generic watch component schema.
- Selection/highlighting/visibility/locking/isolation are stateful in watchComponentStore.

## Assumptions

- Component geometry is represented at engineering-object level and may map to one or more physical layers/bands.
- Export remains deterministic; component metadata augments diagnostics and release readiness.

## Plugin Lifecycle

1. Register component definition.
2. Instantiate default entity.
3. Bind inspector schema.
4. Validate with manufacturing constraints.
5. Export with metadata and diagnostics.

## Future Integration

- Physical simulation constraints for hands/apertures.
- Component-to-movement clearance checks.
- Parametric hardware family packs.

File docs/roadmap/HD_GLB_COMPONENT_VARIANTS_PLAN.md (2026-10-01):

# HD GLB component-variant plan

Status: independent presentation library implemented 2026-09-28; supplier-exact interface validation remains ongoing.

## Goal

Make hands, bezels, and dials independently selectable HD components without baking an entire watch archetype into one inseparable GLB. Every authored asset must preserve engineering scale, anchors, materials, and procedural fallback behaviour.

## Phase 1 — contracts and review harness

- Freeze one component contract per category: units in millimetres, Z-up runtime orientation after import, origin/anchor, authored case diameter, bounding box, material slots, and naming rules.
- Extend the asset manifest with `variantFamily`, `styleId`, `referenceCaseDiameterMm`, compatible movement/hand-stack or case/bezel interfaces, source/evidence status, and review-render path.
- Add automated checks for finite transforms, expected bounds, missing materials, scale mismatch, anchor mismatch, and duplicate IDs.
- Produce the same front, three-quarter, side, and macro review renders for every GLB before registration.

## Phase 2 — hand families

Initial families: baton, Mercedes, sword, dauphine, syringe, cathedral, pencil, broad-arrow, and skeleton.

- Keep hour, minute, and seconds meshes separable, even when shipped in one GLB.
- Record hole diameters, visible length, total length, tube height, material, lume regions, and counterweight envelope.
- Bind hand selection to a new `handStyleId`; do not overload the archetype ID.
- Validate against movement post sizes and crystal/hand-stack clearance before showing green compatibility.

## Phase 3 — bezel families

Initial families: dive coin-edge, dive scalloped, pilot smooth, fluted dress, fixed tachymeter, GMT, and slide-rule.

- Separate bezel body and insert surface so insert artwork/material can change independently.
- Record case interface diameter, crystal clearance, insert OD/ID, insert profile, height, rotation capability, and click-system evidence.
- Clip live scale artwork to the physical insert annulus rather than a full-case square plane.

## Phase 4 — dial families

Initial families: sterile, diver, pilot A/B, field, dress sector, GMT, and chronograph.

- Separate substrate, applied indices, lume, printed artwork, date aperture, and feet/interface metadata.
- Prefer procedural indices/lettering for user overrides; authored dial GLBs must declare whether indices are baked in.
- Record diameter, thickness, centre hole, feet positions, date-window geometry, chapter-ring clearance, and movement compatibility.

## Phase 5 — configurator integration

- Add independent Hands, Bezel, Bezel Insert, and Dial selectors in Visual mode.
- Preview first; Apply only when compatibility is green or explicitly conditional. Red candidates remain preview-only and must explain the blocking interface.
- Show authored diameter beside every HD asset. If the case size changes away from that diameter, switch to the procedural representation and explain why.
- Persist component asset IDs in the project file and include them in render-package manifests.

## Acceptance gate per asset

An asset is registrable only when it passes: correct real-world bounds, correct anchor, no unexpected rotation/scale, named materials, clean normals, no duplicate geometry, render review, procedural fallback, compatibility metadata, and licence/source evidence.

## Recommended first delivery slice

1. Mercedes, baton, and dauphine hand sets.
2. Coin-edge dive and smooth fixed bezels, each with separate insert surface.
3. Sterile, diver, and dress-sector dials.
4. Independent selectors plus project persistence.
5. Nine-asset automated render/contact-sheet review and regression tests.

## Implemented library

- 36 independently selectable GLBs: nine 42 mm hand families, one compact NH05 hand set, seven 42 mm bezel families, eight 28.5 mm dial families, four 24.5 mm NH05 dress dials, and seven researched case envelopes.
- Every generated asset is recorded in `public/assets/3d/variants/manifest.json` and cross-checked against the runtime visual registry by automated tests.
- Generated meshes use millimetres, named component meshes, stable watch-axis placement, and provisional provenance metadata.
- Catalogue Preview and Apply now carry the selected GLB into Visual mode; applying a case also updates the master case diameter and thickness.

These assets complete the presentation workload. They do not turn incomplete supplier evidence into machining claims: hand bores, dial feet, bezel retention interfaces, gasket seats, stem height and internal case clearances remain gated until exact drawings or measured samples are available.

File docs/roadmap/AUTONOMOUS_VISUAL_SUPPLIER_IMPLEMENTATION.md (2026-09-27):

# Autonomous visual and supplier implementation

Started: 2026-09-26.

## Milestone 1 — selected parts visibly change Visual mode

- [x] Add catalogue-to-visual metadata.
- [x] Allow explicit component selections to override broad archetype assets.
- [x] Add a procedural radial sunburst material.
- [x] Generate and register a 42 mm knurled bezel GLB.
- [x] Generate and register a 42 mm Mercedes hand-set GLB.
- [x] Complete automated Preview/Apply mapping tests and deterministic Blender review renders.
- [ ] Repeat the click-through in a full-width WebGL browser before release; the narrow in-app browser clipped the engineering selection ring.

## Milestone 2 — compact supplier architecture

- [x] Add a small category-coverage supplier directory.
- [x] Keep commercial offers separate from engineering components.
- [x] Document affordability and onboarding rules.
- [x] Add stale-price indicators and landed-cost sorting.

## Milestone 3 — AliExpress capture

- [x] Define a validated, timestamped capture format.
- [x] Add an item-page capture helper.
- [x] Add component-scoped JSON import in the Suppliers tab.
- [ ] Browser-test against a current AliExpress item page and revise selectors as needed.

## Verification gate

No milestone is complete until unit tests, typecheck, lint, production build and `git diff --check` pass. GLBs must also pass the repository Blender validator. Marketplace captures remain unverified until checkout and dimensional review.

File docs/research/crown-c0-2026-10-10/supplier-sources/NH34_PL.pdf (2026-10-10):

29082024
Cal.NH34A　　Parts List | 维修零件清单

PARTS CODE　零件编号
PARTS NAME　　零件名称 | Type - M
Barrel and train wheel bridge with hole jewel frame 轮列夹板 | 0114 283
Lower plate for barrel and train wheel bridge 发条鼓下夹板 | 0436 166
Center wheel bridge 中心轮夹板 | 0122 302
Pallet bridge 擒緃叉(马仔)夹板 | 0161 300
Balance bridge 摆夹板组件(不带油丝) | 0173 353
Balance complete with stud 油丝含外桩 | 0310 183
Automatic train bridge 自动锤夹板 | 0191 183
Barrel complete with mainspring 条盒轮(发条鼓) | 0201 083
Center wheel and pinion 中心轮 | 0221 185
Cannon pinion 分轮 (十反) | 1225 333
Third wheel and pinion 3# 轮 | 0231 070
Fourth wheel and pinion 4# 轮(秒轮) | 0144 185
Escape wheel and pinion 摛纵轮 (莲花轮) | 0251 383
Minute wheel and pinion 度数轮 | 0261 190
Hour wheel 时轮 | 0273 333
24 hour wheel 24小时轮 | 0278 333
Clutch wheel 离合轮 | 0282 183
Winding pinion 企轮 | 0283 020
Ratchet sliding wheel spring 游动座弹弓 | 0363 184
Ratchet wheel 大钢轮 | 0285 051
Pallet fork 擒緃叉(马仔) | 0301 383
Click 止逆爪 (上錬弹弓) | 0381 004
Setting lever 设置杆 (押制) | 0383 185
Yoke 离合杆 (横担) | 0384 183
Yoke spring 离合杆簧(横担压片) | 0388 177
Balance stop lever 止秒杆 | 0601 183
First reduction wheel 自动轮 | 0511 010
Second reduction wheel and pinion 逆轮 | 0514 183
Pawl lever 自动叉 | 0831 183
Reduction wheel holder 自动轮固定片 | 0836 002
Intermediate date driving wheel and pinion 日送中间轮 | 0817 333
Date indicator driving wheel 日送轮 | 0802 333
Date indicator maintaining plate with time difference setting lever 日暦定位片(日历盘压片) | 0808 334
Date jumper 日历定位弹弓 | 0810 333
Date corrector wheel 日历修正轮 | 0737 333
Day-date corrector setting transmission wheel A 日暦星期修正传动轮 A | 0962 183
Guard for day-date corrector setting transmission wheel 日暦星期修正传动轮压片 | 0836 183
Day-date corrector setting transmission wheel B 日暦星期修正传动轮 B | 0962 023
Day-date corrector setting transmission wheel C 日暦星期修正传动轮 C | 0962 185
Day-date corrector setting transmission wheel E 日暦星期修正传动轮 E | 0962 025
Dial holding spacer 表盘垫圈 | 4408 172
Dial washer 表面垫圈 | 0491 333
Ratchet wheel screw 大钢轮螺丝 | 0012 919
Barrel and train wheel bridge screw 轮列夹板(大夹板)螺丝 | 0012 100
Balance bridge screw 油丝夹板螺丝 | 0012 100
Lower plate for barrel and train wheel bridge screw 发条鼓下夹板螺丝 | 0012 354
Center wheel bridge screw 中心轮夹板螺丝 | 0012 354
Pallet bridge screw 擒緃叉(马仔)夹板螺丝 | 0012 354
Automatic train bridge screw 自动锤夹板螺丝 | 0012 354
Date indicator maintaining plate screw 日暦定位片螺丝 | 0012 354
Yoke spring screw 横担压片螺丝 | 0012 168

29082024 Cal.NH34A　　Parts List | 维修零件清单

PARTS CODE　零件编号
PARTS NAME　　零件名称 | Type - M
Guard for day-date corrector setting transmission wheel screw 星期日历修正传动轮压片螺丝 | 0012 485
Winding Stem 巴芯 | 0351 200

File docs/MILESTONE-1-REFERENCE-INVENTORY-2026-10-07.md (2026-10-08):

# Milestone 1: original-reference research checkpoint

7 October 2026, updated8 October. **Both selected references are now verified for disclosed reconstruction; the runtime/factory-fidelity gate is NOT passed.** See [Citizen verification](CITIZEN-VERIFICATION-2026-10-07.md) (450 positions) and [Navitimer verification](NAVITIMER-VERIFICATION-2026-10-08.md) (420 positions) for authoritative reviews. Earlier research checkpoints below are retained as history and are superseded wherever they call either reference's counts, pointer identities or qualitative colours unresolved. Fonts/ink/mm/source geometry remain qualified, not factory-certified. Research only; no application renderer, supplier catalogue, GLB or runtime preset changes.

## Durable deliverables

- [Reference manifest](research/slide-rules/reference-manifest.json): selected identities, URLs, PDF fingerprints, page numbering, confirmed facts and unresolved details.
- [Machine-readable research inventory](research/slide-rules/graduation-inventory.json): 126 records (106 numerical labels, 13 reference identities, 7 excluded annotation identities), plus108 counted consecutive interval-review sectors covering all four main rings from10 to the single100/10 seam.
- [Citizen photographic verification packet](research/slide-rules/citizen-jy8078-verification.json): all 52 Citizen sectors counted, 450 graduation identities, value-specific photographic profiles, separate pointer/ink/box roles, glyph samples and reproducible ellipse/palette measurements.
- [Navitimer selected-disc verification packet](research/slide-rules/navitimer-training-disc-verification.json): all56 sectors counted, 420 graduation identities, corrected captionless fixed36 and separate rotating reference, coarse pixel profiles, independent source-model sensitivity and sampled palette roles.
- [Research validator](research/slide-rules/validate-inventory.mjs): identities, sources, sector coverage, counts, seams, exclusions and mathematical consistency. Passing it is not runtime photographic-fidelity certification.

Both source subdivision/layout inventories are closed for disclosed reconstruction. Factory physical typography specifications, exact fonts/inks and exact registration remain unresolved. Unknowns stay `null`; none may silently become generic subdivisions, zero dimensions or runtime defaults. The application does not import these files.
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

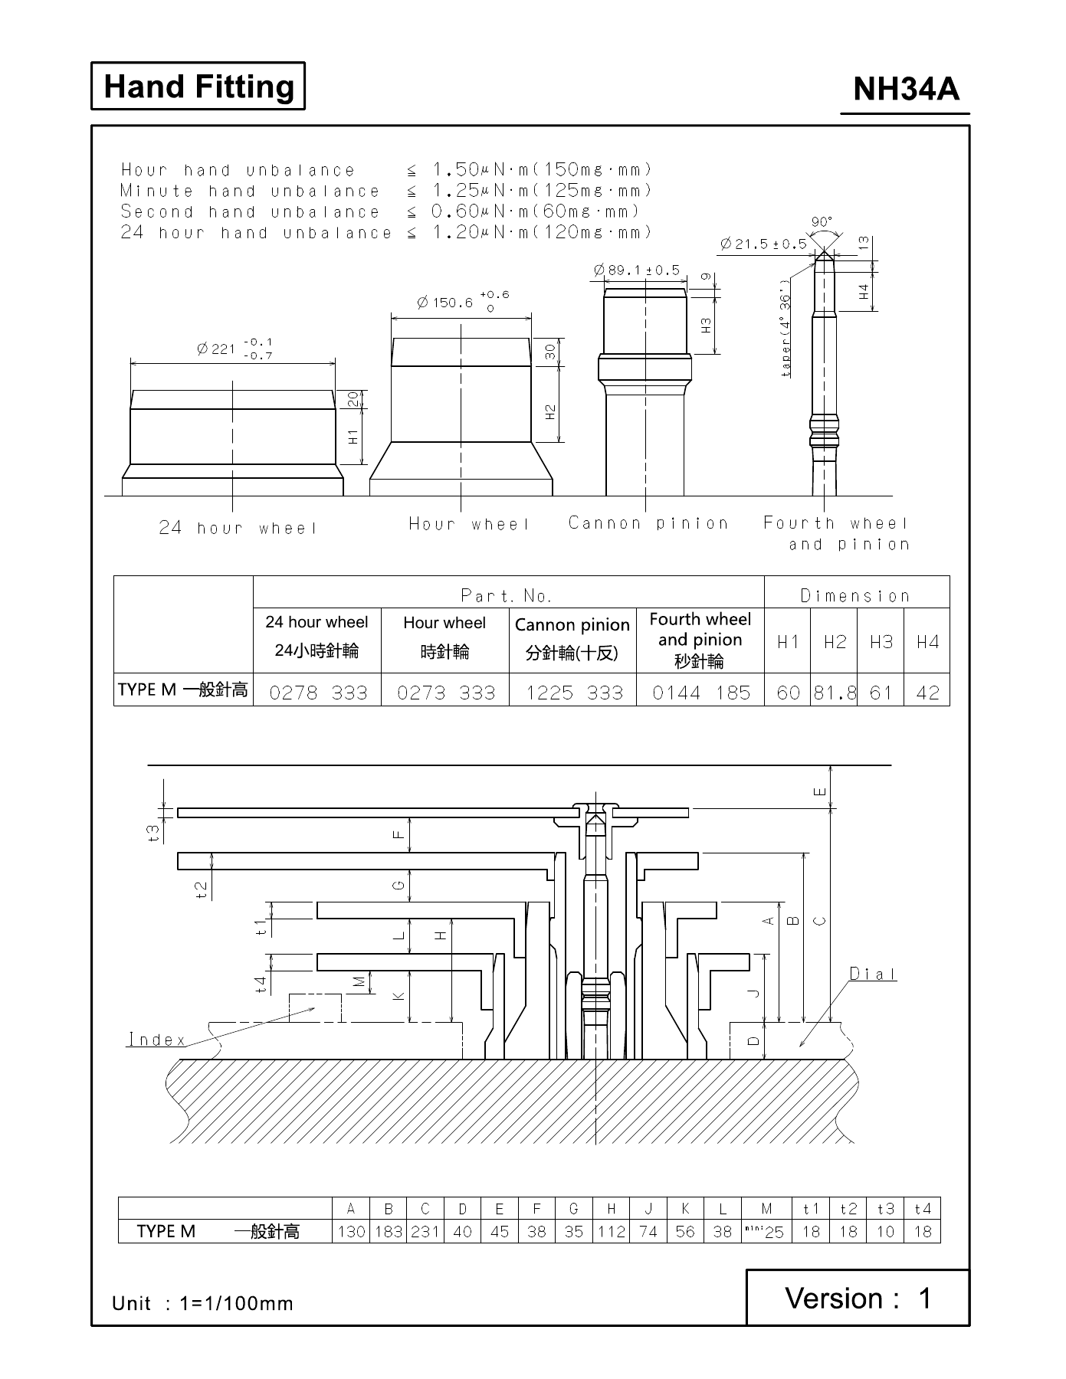
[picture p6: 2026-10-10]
docs/research/crown-c0-2026-10-10/supplier-sources/NH34-stem.png

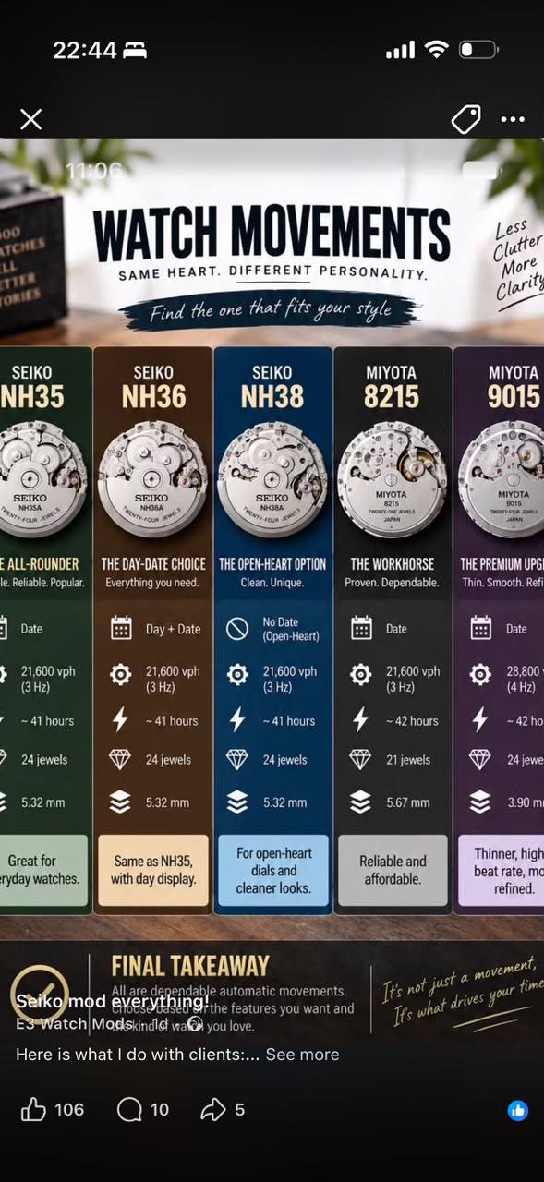
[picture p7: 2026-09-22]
docs/reference-components/2026-09-22-subdials-movements-lugs/watch-movements.jpeg

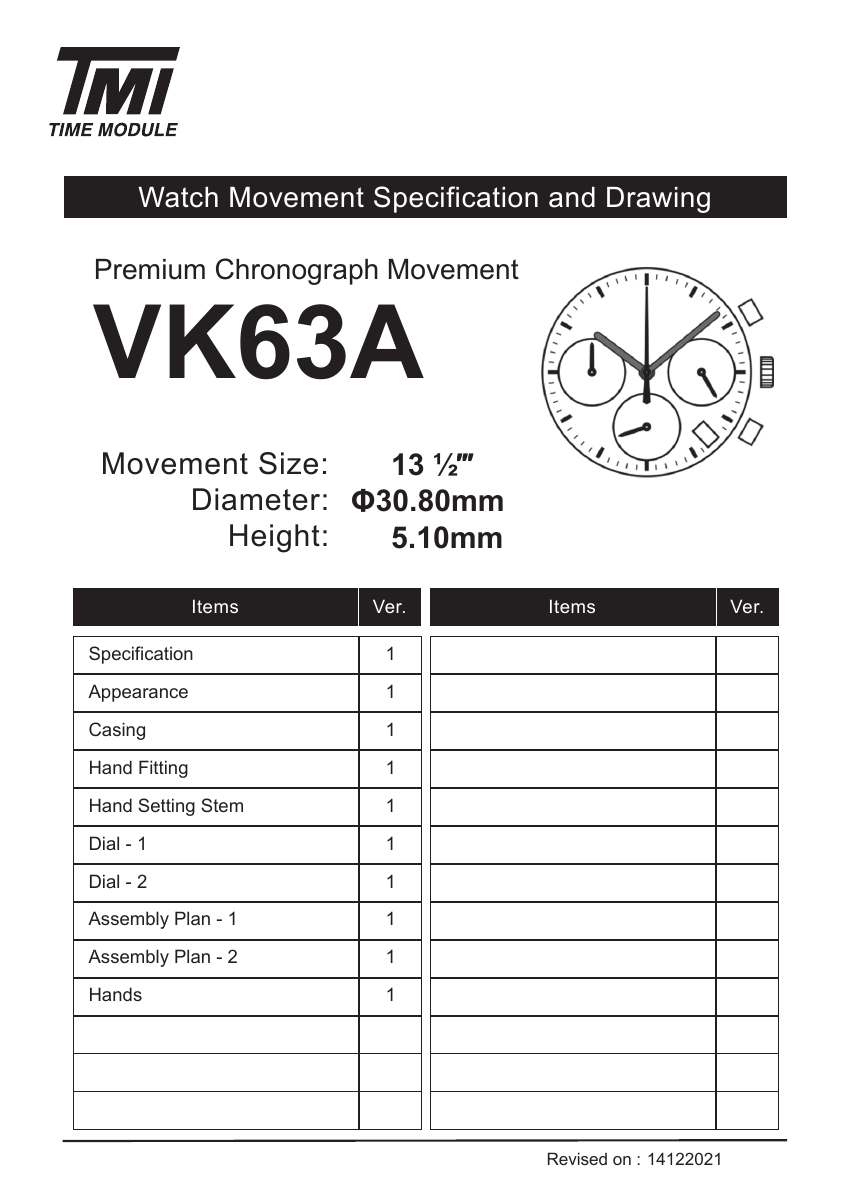
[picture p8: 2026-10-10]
docs/research/crown-c0-2026-10-10/supplier-sources/VK63-cover.png

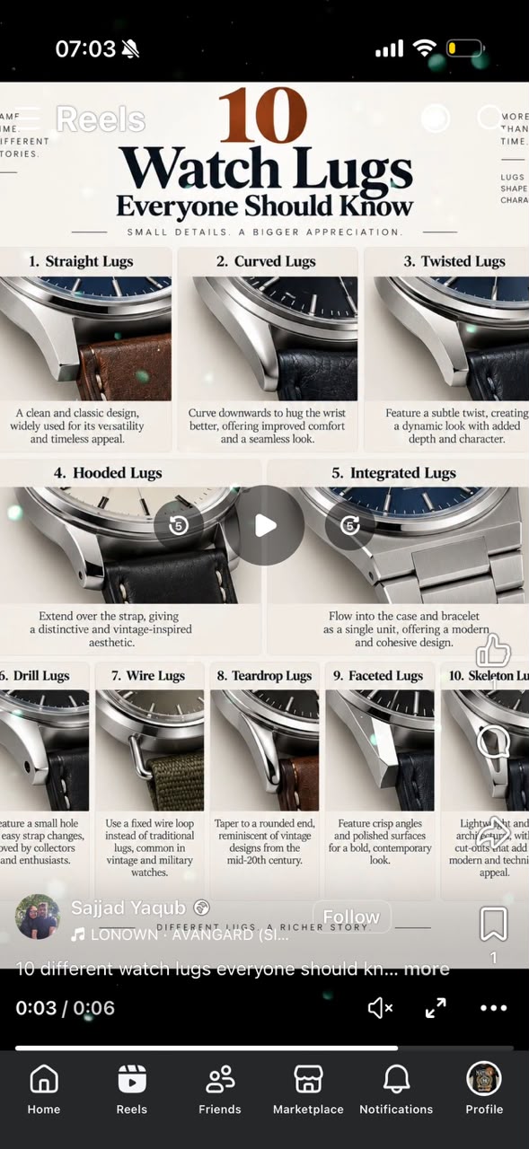
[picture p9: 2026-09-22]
docs/reference-components/2026-09-22-subdials-movements-lugs/watch-lugs.jpeg

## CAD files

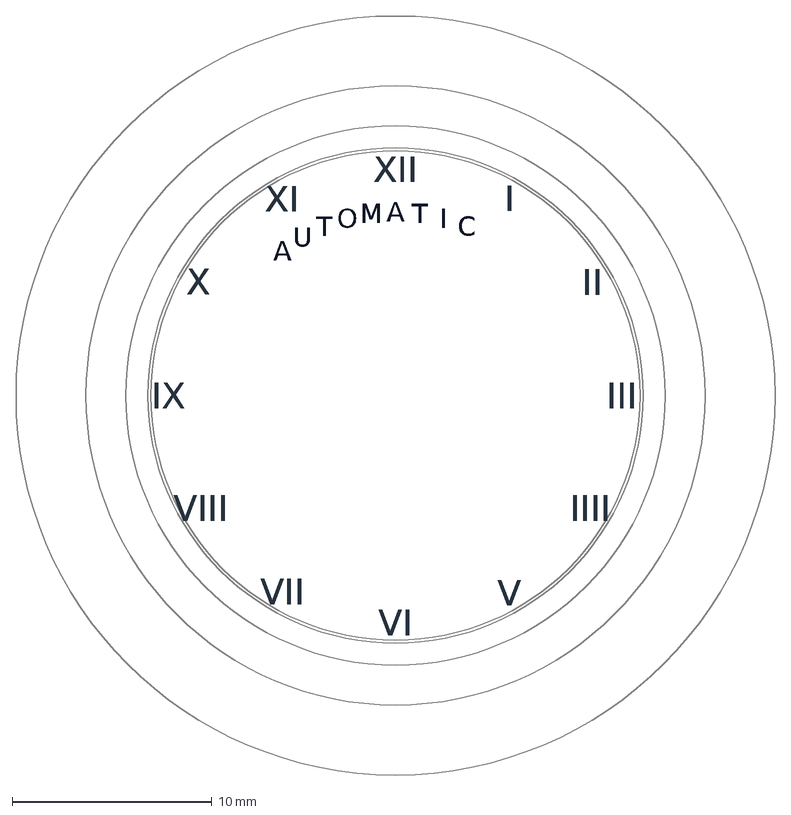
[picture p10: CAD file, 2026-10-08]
output/pdf/m4-ladies34-simplified.dxf
XII
I
II
III
IIII
V
VI
VII
VIII
IX
X
XI
A
U
T
O
M
C

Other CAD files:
output/pdf/m5-decimal-hour.dxf
output/pdf/m5-knots-mph.dxf
output/pdf/m4-pilot42-citizen.dxf
output/pdf/m4-pilot42-navitimer.dxf
output/pdf/m7-42-citizen.dxf
output/pdf/m7-46-navitimer.dxf
output/pdf/m7-46-citizen.dxf
output/pdf/m7-42-navitimer.dxf
public/assets/3d/face-review/assembly-animated.blend

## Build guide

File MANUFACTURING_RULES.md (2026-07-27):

# Manufacturing Rules

## Scope

This library defines manufacturing intelligence as structured data and keeps application behavior traceable.

Every rule is documented with:

- unique rule id,
- code,
- source classification,
- supporting supplier category,
- applicable processes,
- confidence level,
- configurable thresholds,
- revision and version.

## Classification Model

- Verified manufacturer capability: directly grounded in published capability ranges.
- Industry best practice: broad production guidance used across professional watchmaking workflows.
- Engineering assumption: configurable placeholder where published evidence is limited.

## Source Categories Incorporated

Current rule set includes supplier categories such as:

- Custom dial manufacturers
- Applied index manufacturers
- Pad-print specialists
- Laser engraving specialists
- UV printing specialists
- OEM watch manufacturers

These categories are stored in data and surfaced in UI diagnostics.

## Rule Coverage Areas

Current structured rules cover:

- minimum printable line width,
- minimum text height,
- marker spacing,
- chapter-ring clearance,
- applied-index clearance,
- lume application area assumptions,
- engraving depth assumptions,
- laser kerf constraints,
- UV print stroke limits,
- brass thickness guidance,
- multilayer dial compatibility.

## Runtime Integration

Rules are loaded from [src/domain/asset-library/data/manufacturingRules.json](src/domain/asset-library/data/manufacturingRules.json) and consumed by:

- [src/domain/manufacturing/ruleLibrary.ts](src/domain/manufacturing/ruleLibrary.ts)
- [src/domain/manufacturing/validationEngine.ts](src/domain/manufacturing/validationEngine.ts)
- [src/services/manufacturingSuiteService.ts](src/services/manufacturingSuiteService.ts)

Warnings generated at runtime include traceability metadata so export diagnostics are explainable.

## Change Policy

Manufacturing rule updates should be data-first:

1. Update structured data.
2. Keep framework APIs stable.
3. Add or update tests for rule behavior.
4. Bump revision/version fields.

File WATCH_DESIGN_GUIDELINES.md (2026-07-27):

# Watch Design Guidelines

## Version 3 Position

Version 3 treats watchmaking knowledge as a reusable library layered on top of the frozen engineering framework.

The application should guide users toward authentic, manufacturable watch design outcomes while preserving mathematical correctness.

## Non-Negotiable Principles

1. Authenticity first.
A dial should read like a professional watch product, not generic vector art.

2. Geometry through existing framework only.
Projection, profile, formatter, and rendering systems remain the source of mathematical truth.

3. Manufacturability is mandatory.
Design choices should be explainable against manufacturing capabilities with traceable confidence labels.

4. Professional restraint.
The system should encourage proven watch design patterns over arbitrary decoration.

## Family Guidance

### Pilot and Aviation

- Favor high-contrast typography and controlled surface noise.
- Prioritize railroad and instrument chapter ring compatibility.
- Preserve spacing for dense conversion and navigation scales.

### Chronograph

- Keep tachymeter/telemeter/pulsometer scales visually dominant when present.
- Avoid texture treatments that compete with dense timing numerals.
- Use chapter ring profiles with clear radial print margins.

### Dress

- Favor controlled negative space and premium marker furniture.
- Use applied assets only when supplier capabilities support assembly tolerances.
- Keep typography size above process minima for serif and ornate families.

### Dive and Military

- Prioritize lume area, marker separation, and minute readability.
- Use chapter rings and timers that maintain high legibility under low contrast.
- Prefer robust marker geometries that tolerate manufacturing variation.

## Component Library Intent

All user-facing design choices should map to reusable asset definitions:

- scale assets,
- chapter ring assets,
- marker assets,
- hand assets,
- material assets,
- typography assets.

Each asset should include compatibility metadata so recommendations are contextual instead of generic.

## Advisor Behavior

Recommendations should always answer:

1. Is this authentic for the selected watch family?
2. Is geometry still mathematically coherent?
3. Is the design likely manufacturable by selected supplier categories?
4. Does visual hierarchy remain professional?

Advisor responses should explain why and suggest concrete corrections.

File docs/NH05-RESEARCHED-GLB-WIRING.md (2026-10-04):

# NH05 researched preview assets

Implemented 4 October 2026. These are Blender-authored presentation assets, not supplier-exact manufacturing or fit models.

In an NH05 build, open **Parts** and use **Case options**, **Dial options** or **Main hand sets**. Select a Tandorio researched candidate, preview it and click Apply. The engineering selection and HD component overrides share the same assembly. Selecting the complete hand set updates all three central hands; subdial hands are unaffected. Switching back to the earlier hand set remains supported.

| Catalogue candidate | New asset | Basis and limitations |
| --- | --- | --- |
| Tandorio 34mm NH05 case | `case-tandorio-nh05-research-34.glb` | Published 34mm OD and nominal 12mm whole-case thickness. Body/face decomposition, lugs, shape, holder and hidden interfaces are provisional; the midcase mesh alone is not a 12mm-thick solid. Earlier case GLB is retained. |
| Tandorio 24.5mm white matte dial | `dial-nh05-white-matte-245.glb` | 24.5mm OD and matte white face. Centre opening, thickness, date aperture, date-card example 18 and baton markers are TMI-reference/presentation assumptions, not supplier measurements. |
| Tandorio NH05 luminous set | `hands-nh05-luminous-588.glb` | Centre-to-tip lengths 5/8/8mm recorded on Blender mesh extras. Baton outlines, widths, hub, lume relief and axial stack are provisional, not measured supplier profiles or tubes. |

Style colour controls recolour the existing meshes; finishes do not require duplicate GLBs. The new dial's metallic markers support custom colours. Matte face material and central-hand colour updates are live in HD. The date card is a static presentation example, not a running calendar simulation.

One purchased three-hand set is costed once despite the three engineering hand instances. Selecting the unknown-price RoseGold listing does not silently substitute the Black variant's checked price. Unknown shipping and fit status remain unknown.

Regenerate only these assets, without overwriting unrelated library work:

```text
blender --background --factory-startup --python tools/blender/generate_component_variant_library.py -- --output public/assets/3d/variants --nh05-research-only
```

The library manifest includes all three assets. The Blender validator checks mesh/material presence, bounded geometry and connected case lug roots. Regression tests cover selection, all three lengths, repeated switching, colour edits, real GLB metadata and hand-set pricing.

Fit verification remains governed by [the measurement checklist](NH05-FIT-VERIFICATION-CHECKLIST.md); adding a GLB does not promote these draft catalogue entries or unverified supplier listings.

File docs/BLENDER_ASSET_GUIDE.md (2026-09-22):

# Blender asset guide

Blender is also the canonical reference environment for future parameter-driven
case and hand generators. Scripts must derive meshes from versioned parameters,
keep units explicit, and emit validation metadata. A generated GLB is an output
artifact, not a replacement for the parameter set.

Browser visual assets are authored in Blender and exported as optimized `.glb` files. Blender is not a browser runtime dependency.

## Coordinate convention

- Use metric units with 1 Blender unit representing 1 millimetre at authoring scale.
- Centre the watch on the global Z axis; X/Y are the dial plane and positive Z points toward the crystal.
- Put the object origin on the watch radial centre and at its engineering seat height.
- Keep radial parts concentric with the watch axis and use the registry `anchor` to describe `watch-axis`, `dial-seat`, `hand-stack`, or `crown-interface` placement.
- The browser adapter owns any domain-millimetre to Three.js-unit conversion.

## Authoring and export

- Apply transforms, remove hidden geometry, recalculate outward normals, and triangulate only at export.
- Use stable names such as `case_round_40mm_v1`, `bezel_diver_40mm_v1`, and `hands_mercedes_v1`.
- Prefer bevels with 1–2 segments; avoid unapplied subdivision and dense booleans.
- Keep case assets below 50k triangles, bezels below 20k, crystals below 5k, and hand sets below 10k total.
- Use reusable materials where possible; do not bake every finish into a separate mesh.
- Keep textures at 1K by default and 2K only when visibly justified. Do not ship 4K/8K textures.
- Export GLB with selected objects, applied transforms, compressed geometry where available, and embedded or relative textures validated against the public asset path.

The visual registry is the integration point. A routine new part should add a catalogue reference, one registry descriptor, and one file under `public/assets/3d/` without a new React component.

P4 applies this path to case, dial, bezel, crystal, hands (one hand-set slot), and
crown. Descriptor `offset` is in engineering mm, `rotation` in XYZ radians and
`scale` is dimensionless. Defaults are numeric millimetre units and glTF Y-up;
`units: 'metres'` and `upAxis: 'Z'` are explicit alternatives. Blender's default
Y-up GLB export is rotated back by +pi/2 about X before assembly placement. The
scene converts mm to display units once; it does not resize authored GLBs when the
case diameter changes. Asset authors must use the matching anchor-local origin.
Procedural/loading/error fallbacks use the same assembly anchor and instance
transform but do not inherit GLB-specific offsets, rotation or scale.

### Parametric crown v1 and case-side interface

The existing case generator is unchanged: its boss and tube are mechanical
interface geometry and remain in `DD_PARAMETRIC_CASE`. They are **not** the
removable crown head. `parametric_crown_v1.py` consumes the canonical
`parametric-crown/v1` contract and creates only `DD_CROWN_HEAD` in
`DD_PARAMETRIC_CROWN`, with a rear blind socket and optional axial grip ribs.
`headDiameterMm` is the base diameter; the maximum grip diameter is
`headDiameterMm + 2 * gripDepthMm` when gripCount is nonzero.
Rebuilding the crown collection leaves the case untouched.

The crown's local rear face/socket entrance is X=0 and its head extends along +X.
Attach that origin to the `crown-interface` frame plus `attachment.axialGapMm`
along local +X. For the existing case generator the frame is at
`(caseDiameter / 2 - crownTubeEmbed + crownTubeLength, 0, 0)`; the 42 mm test case
therefore has X=21.8 mm. Explicit assembly frames support other positions/rotations.
The generator exports local geometry and never bakes this world placement into it.
The socket dimensions do not establish fit, stem compatibility, sealing or threads.

All values in `test_crown_v1.json` are an explicitly **provisional visual fixture**.
`stemThreadPitchMm` is unknown and deliberately unmodelled. Unknown geometry needed
to build the head/socket fails clearly; unknown attachment gaps can be stored but
must be resolved for engineering placement (the preview is marked provisional).
The TypeScript validator reports `valid`, `invalid` or `unknown` and retains paths
to unknown dimensions. None of these outcomes constitutes manufacturing approval.

```text
blender --background --factory-startup --python-exit-code 1 --python tools/blender/parametric_crown_v1.py -- --params tools/blender/test_crown_v1.json --quality normal --output .artifacts/blender-review/crown-v1/crown-v1.glb
```

After review, an intentionally published file can use the opt-in registry ID
`crown-reference-v1` at `/assets/3d/generated/crowns/crown-v1.glb`. This file is **not**
published automatically by the harness and is not selected by default. Bind the
crown instance with `visual: { category: 'crown', assetId: 'crown-reference-v1' }`
and retain its `parametricGeometry` and provenance. Missing assets render safely as
procedural previews. Legacy `customProperties.visualAssetId` remains supported.

## Parametric hand generator v1

[`tools/blender/parametric_hand_v1.py`](../tools/blender/parametric_hand_v1.py) consumes `parametric-hand/v1` or `parametric-hand-set/v1` JSON. It creates separate hub, body, tip, tail, and lume regions in `DD_PARAMETRIC_HANDS`, uses a real boolean pinion bore, and assigns reusable `HAND_METAL`/`HAND_LUME` materials. The demo fixture is `tools/blender/test_hand_set_v1.json`.

```text
blender --background --python tools/blender/parametric_hand_v1.py -- --params tools/blender/test_hand_set_v1.json --quality normal
blender --background --python tools/blender/parametric_hand_v1.py -- --params tools/blender/test_hand_set_v1.json --quality high --output public/assets/3d/generated/hands/hand-set.glb
```

Quality is a presentation setting (`preview`, `normal`, `high`), and Z positions in the hand-set demo are reference placement values rather than movement-specific stack dimensions. Unknown required dimensions fail clearly; no generic bore is substituted.

## Parametric case generator v1

The reference generator is [`tools/blender/parametric_case_v1.py`](../tools/blender/parametric_case_v1.py). It consumes the `parametric-case/v1` field names and treats Blender units as millimetres. The NMK901 fixture carries explicit `ESTIMATED_NOMINAL` spring-bar holes, seat steps, crown-tube bore/thread references, and axial clearance values for preview generation; these remain soft-warning engineering estimates, not manufacturing defaults.

Run in Blender's Scripting workspace, or headlessly:

```text
blender --background --python tools/blender/parametric_case_v1.py -- --quality normal
blender --background --python tools/blender/parametric_case_v1.py -- --params case.json --quality high --output public/assets/3d/generated/cases/case.glb
```

Quality controls radial sampling (`preview`, `normal`, `high`) and is not part of the physical case schema. The generator creates/rebuilds only `DD_PARAMETRIC_CASE`, including a smooth revolved mid-case, paired tapered lugs at the 12/6 strap ends, embedded crown boss/tube source objects, and optional chronograph pusher bosses/tubes at 2 h and 4 h. Re-running is idempotent. GLB export is optional and selection-scoped. `lugWidth` is the total pair envelope and `lugPairGap` is the clear strap/spring-bar gap; fixture values remain provisional.

### Lug attachment

The lug root follows the case shoulder at each root corner and is inset by `lugCaseOverlap`. This keeps paired tapered lugs visibly connected when the inside-lug width is widened; the 42 mm review fixture uses a provisional 2.2 mm overlap and must be regenerated if its parameters change.

### Chronograph pushers

When `pusherCount` is 1 or 2 and `pusherLayout` is `2h-4h`, the generator adds pusher tube and boss cylinders at +60° (2 h) and −60° (4 h) around the crown (+X) axis. Pusher dimensions are independent of the crown and follow the same embed/length convention. These are visual/mechanical interface geometry only; stem, return spring, gasket and sealing are not modelled.

### Presentation visual library

The NMK901 complete-reference generator
[`tools/blender/reference_42_supplemental.py`](../tools/blender/reference_42_supplemental.py)
uses `reference_42_supplemental.json` to emit independent dial, chapter-ring,
bezel, crystal, caseback and strap-preview GLBs. Use `--quality high` for the
published `public/assets/3d/reference-42/` assets. The caseback exterior, bezel
carrier envelope, crystal thickness and strap profile are presentation-only
estimated nominal values pending Golden Sample #1 validation.

The reference strap preview also includes presentation-only keeper loops and a
separate polished tang buckle. In the browser, the authored GLBs are combined
with the current typography configuration as a transparent dial-artwork layer;
the central-view export control renders the active camera to a 2048 x 2048 PNG.

The presentation-only library generator is [`tools/blender/generate_visual_library.py`](../tools/blender/generate_visual_library.py). It creates the registered 40 mm case, bezel, domed crystal and hand-set GLBs under `public/assets/3d/`; these assets are fixed-size visual aids and are not manufacturing evidence.

The 42 mm archetype component library is generated by
[`tools/blender/generate_archetype_library.py`](../tools/blender/generate_archetype_library.py).
It produces five dial, bezel and hand-set variants, four strap variants, one
chronograph pusher set and VK63 needle, baton and syringe register-hand variants
under `public/assets/3d/archetypes/`. Every object is
tagged `provisional-presentation`; these assets preserve the reviewed case
envelope but do not add interface or water-resistance evidence.

```powershell
blender --background --factory-startup --python-exit-code 1 --python tools/blender/generate_archetype_library.py -- --output public/assets/3d/archetypes
blender --background --factory-startup --python-exit-code 1 --python tools/blender/test_archetype_library_blender.py
```

```powershell
blender --background --factory-startup --python tools/blender/generate_visual_library.py -- --asset bezel --output public/assets/3d/bezels/bezel_diver_40mm_v1.glb
blender --background --factory-startup --python tools/blender/generate_visual_library.py -- --asset crystal --output public/assets/3d/crystals/crystal_domed_32mm_v1.glb
blender --background --factory-startup --python tools/blender/generate_visual_library.py -- --asset hands --output public/assets/3d/hands/hands_mercedes_v1.glb
blender --background --factory-startup --python tools/blender/parametric_dial_v1.py -- --params tools/blender/test_dial_face_40mm.json --output public/assets/3d/dials/dial_face_40mm_layout_v1.glb
```

The dial fixture is texture-ready for Blender rendering: its procedural surface shader is preserved in the GLB, and its marker geometry, three VK63-role chronograph registers, and date/day apertures are separate meshes. The VK63 layout semantics, 7.50 mm register centres and post diameters come from TMI's official drawing; register artwork diameter and hand silhouettes remain estimated until supplier evidence is complete.

## Lug-case option library

`generate_lug_case_library.py` consumes the controlled 42 mm case fixture and generates ten complete case GLBs under `public/assets/3d/lug-cases/`. The styles are straight, curved, twisted, hooded, integrated, drilled, wire, teardrop, faceted and skeleton. These are selectable central-view assets with `provisional-presentation` provenance. They are not interchangeable manufacturing platforms: wire and integrated styles change the strap interface, and every family still needs its own measured drawing and physical validation.

```powershell
blender --background --factory-startup --python-exit-code 1 --python tools/blender/generate_lug_case_library.py -- --params tools/blender/test_case_42.json --output public/assets/3d/lug-cases
blender --background --factory-startup --python-exit-code 1 --python tools/blender/test_lug_case_library_blender.py
```

## Shared local component render-and-review harness

Prerequisites: Windows PowerShell 5.1 or later, a local Blender installation with
Eevee rendering support and its bundled glTF importer/exporter, and this repository.
No Python packages, Blender MCP, API keys, or network services are required.
Blender **5.2.1 LTS** was verified locally with `blender.exe --version`, followed by
the full background generation, reimport, and four-view render workflow.

Run this single command from any current directory (adjust the repository path if
your checkout is elsewhere):

```powershell
powershell.exe -NoProfile -ExecutionPolicy Bypass -File "C:\Users\Deon\Documents\GitHub\Dial-New-Design.01\tools\blender\review_case_42.ps1"
```

To supply another executable, append `-BlenderExe`:

```powershell
powershell.exe -NoProfile -ExecutionPolicy Bypass -File "C:\Users\Deon\Documents\GitHub\Dial-New-Design.01\tools\blender\review_case_42.ps1" -BlenderExe "D:\Apps\Blender\blender.exe"
```

The wrapper derives the checkout root from its own location. Without an override,
it checks `C:\Program Files\Blender Foundation\Blender 5.2\blender.exe`, then
`blender.exe` on PATH, then immediate Blender installation directories under
`Blender Foundation` in Program Files, Program Files (x86), and LocalAppData.
It does not modify the registry. Other Blender versions are not verified; the
renderer explicitly requires the installed `BLENDER_EEVEE` engine identifier.

Outputs are overwritten on each run in `.artifacts/blender-review/case-42/`:

| File | Purpose |
| --- | --- |
| `case-42.glb` | Temporary export of unchanged `test_case_42.json`, normal quality |
| `top.png` | View from +Z, dial plane visible |
| `front.png` | View from -Y, +Z up |
| `side.png` | View from +X, +Z up |
| `three-quarter.png` | View from +X/-Y/+Z |
| `manifest.json` | Blender version, source, label, mesh names/count, vertex count, bounds, engine, resolution, cameras and image paths/sizes |
| `review.log` | Complete Blender stdout/stderr, commands/arguments, exit codes and final artifact paths |

P4 moves orchestration into `review_component.ps1`; `review_case_42.ps1` remains a
compatible thin wrapper, and `review_crown.ps1` uses the same pipeline. Run:

```powershell
powershell.exe -NoProfile -ExecutionPolicy Bypass -File tools/blender/review_crown.ps1
```

Crown output goes to `.artifacts/blender-review/crown-v1/` with `crown-v1.glb` and
the same four views, manifest and log. Later generators can call the generic
wrapper with `-Generator`, `-ParamsFile`, `-AssetName` and `-AssetLabel` (absolute
input paths recommended). Asset names permit only lowercase letters, digits and
hyphens, keeping output cleanup inside the review directory. One log writer stays
open for each run to avoid Windows file-open races. Do not run concurrent reviews
with the same asset name. The validator, cameras, lights and renderer are shared;
no category-specific render pipeline was added.

The reference review also provides `review_hand_set.ps1` and `review_reference_42.ps1`. The latter
uses `reference_42_assembly.json` to combine the case, separate crown head and
hand set at explicit provisional frames for a four-view interference review.
Its combined GLB is not registered in the application. Three individual GLBs
are selected as fixed 42 mm **visual previews** under
`public/assets/3d/reference-42/`; see [P7 NMK901 reference review](P7_NMK901_REFERENCE_REVIEW.md)
for controlled dimensions, nominal hand-fit evidence and provisional/estimated interfaces. Successful
structural validation and rendering do not approve mechanical fit.

Each stage runs in a fresh background Blender process with factory settings and
`--python-exit-code 1`. Generation uses the existing case generator without changing
its dimensions or algorithms. `validate_glb.py` rejects missing, blank, nonexistent,
empty, or unimportable GLBs and requires at least one mesh and a positive total
vertex count in the imported scene. Counts refer to imported mesh objects and their
vertices, including splits made by glTF export. This is a structural smoke check,
not a watertightness, normals, dimension-tolerance, or manufacturing certification.

`render_review.py` independently imports and validates the GLB, calculates combined
world-space bounds and translates scene roots to center the asset in memory. The
source GLB is never rewritten. Fixed area lights, neutral world, AgX color settings
and orthographic cameras produce 512 x 512 RGB PNGs. Each camera frames all bounding
box corners with a 15% margin and scale-relative clipping planes. Bounds are in
imported Blender units; for this fixture, one unit represents one millimetre.
Camera and lighting setup is repeatable; pixel-identical output across GPU drivers
or Blender versions is not guaranteed. A local repeat render produced identical
image data in all four views, but Blender embeds date/render-duration metadata in
PNGs, so whole-file hashes can differ even when pixels match.
The renderer uses Blender 5.2's default `World.node_tree` directly; it does not
assign the deprecated `World.use_nodes` property.

The wrapper stops on any failed subprocess and exits non-zero. It clears its known
previous outputs first; a success manifest is written only after all renders finish.
On failure, use `review.log` to identify the failing stage; partial images may remain.
Run only one instance per checkout at a time because the output directory is shared.
Inspect every view before accepting the asset: successful file generation alone does
not establish visual quality.

Generated review files are ignored only under `.artifacts/blender-review/` and must
not be treated as selected production assets. Production GLBs deliberately selected
for `public/assets/3d/` still require review and registry integration; this harness
does not create or register any production asset. GLB, PNG and Blender files elsewhere
remain eligible for version control.

### Troubleshooting and helper tests

- **Blender not found:** provide the full executable path with `-BlenderExe`.
- **Script policy prevents launch:** use the command above; its execution-policy
  override applies to that PowerShell process only.
- **Import or generation fails:** check the first failed stage in `review.log` and
  the versioned fixture. Do not replace missing dimensions with guessed values.
- **Eevee unavailable or GPU initialization fails:** verify Blender 5.2.1 and that
  Eevee works on the local graphics driver/session. Headless rendering still needs
  supported graphics hardware; the harness deliberately does not substitute Cycles.
- **Images look wrong:** inspect all four views for clipping, shading, overlaps and
  source geometry defects. Review scripts preserve the existing geometry/materials;
  fixing generator geometry is a separate task.

Pure framing/bounds tests use the Python standard library and do not import `bpy`:

```powershell
python -B -m unittest discover -s tools/blender -p test_review_helpers.py
python -B -m unittest discover -s tools/blender -p test_crown_helpers.py
blender --background --factory-startup --python-exit-code 1 --python tools/blender/test_component_assembly_blender.py
blender --background --factory-startup --python-exit-code 1 --python tools/blender/test_reference_42_assembly_blender.py
```

Run that test command from the repository root with a local Python 3 installation.
Ordinary `npm test` / Vitest runs do not launch or require Blender.

The Blender-only check verifies crown rebuild idempotence, retention of all seven
case objects, separate visibility and alignment against the actual tube bounds.
Pure crown helpers test contract failures, unknown dimensions, dimensions, socket
topology/orientation and local export coordinates. Review images check presentation;
the inherited case/lug model and the provisional crown still require engineering
fit and clearance review before production use.

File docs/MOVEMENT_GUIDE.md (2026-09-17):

# Movement Guide

## Movement Integration

Movement recommendations provide:
- recommended dial diameter
- chapter ring width
- bezel width
- center hole
- date position
- subdial layout
- safe clearances

For future parametric hands, movement templates are the only source for verified
hour, minute, and seconds pinion/arbor specifications. Missing or unverified
dimensions must remain `unknown`; neither the hand generator nor documentation
may infer a calibre measurement.

## Workflow

1. Select movement in inspector.
2. Engine applies recommended center-hole and ring sizing hints.
3. Validate with manufacturing and collision warnings.

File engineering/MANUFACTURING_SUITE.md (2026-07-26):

# Manufacturing Suite

## Architecture

Manufacturing suite capabilities are implemented as additive services around existing validation/export flows.

Primary modules:

- src/domain/manufacturing/validationEngine.ts
- src/services/manufacturingSuiteService.ts
- src/services/exportService.ts
- src/services/exportGeometryService.ts

## Manufacturing Pipeline

1. Run geometry/manufacturing validations.
2. Build engineering SVG payload.
3. Run native SVG verification.
4. Run manufacturing report synthesis.
5. Export to SVG/DXF/PDF/PNG with metadata.
6. Preserve geometry and emit diagnostics only.

## Supported Profiles

- Laser
- Pad Printing
- UV Printing
- CNC
- Engraving
- Etching
- Photo Chemical Machining

Vendor calibration profiles are modeled as additive process compensation metadata.

## Engineering Decisions

- No silent geometry modification during export.
- Native SVG validation is explicit and reportable.
- DXF/PDF/PNG exports are generated through service boundaries and keep metadata traceability.

## Assumptions

- Process minima are conservative defaults for cross-vendor compatibility.
- Vendor calibration profiles provide compensation hints rather than mutating source geometry.

## Future Integration

- Machine-specific profile packs.
- Full standards-backed DXF entity expansion.
- Signed export verification manifests.

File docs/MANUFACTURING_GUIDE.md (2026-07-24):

# Manufacturing Guide

## Validation Coverage

Current validation includes:
- minimum line width
- text legibility and text-too-small warnings
- laser kerf checks
- UV print minimum checks
- overlaps and invalid concentric geometry
- printable area overflows
- tolerance range validation
- collision-mapped warnings

## Material Considerations

Material library includes:
- thickness
- laser suitability
- UV suitability
- CNC suitability
- color options
- recommended tolerance
- process notes

## Export Readiness

Use Export Preview before final output:
- verify dimensions
- inspect layer list and materials
- inspect warnings
- review estimated print/engraving/laser sizes

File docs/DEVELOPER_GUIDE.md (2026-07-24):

# Developer Guide

## Setup

```bash
npm install
npm run dev
```

## Quality Gates

```bash
npm run typecheck
npm run lint
npm run test
npm run build
```

## Development Rules

- Extend existing services and stores.
- Keep domain logic in `src/domain` and service orchestration in `src/services`.
- Keep strict TypeScript and avoid duplicated validation logic.

## Adding New Engine Features

1. Add domain types and generator function.
2. Add state fields/actions in `designEngineStore`.
3. Expose controls in inspector.
4. Add export integration if geometry must be included in outputs.
5. Add tests.

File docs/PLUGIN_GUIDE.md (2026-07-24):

# Plugin Guide

## Scale Plugins

Scale plugins register through `scaleRegistry`.
A plugin provides:
- metadata
- inspector fields
- math mapping
- tick generation
- label generation
- geometry output
- validation
- SVG output

## Texture Plugins

Texture plugins register in `textureEngine` and provide:
- `kind`
- `displayName`
- `implemented` flag
- `apply(baseStyle, intensity)` function

## Future Plugin Surfaces

- Marker shapes
- Typography path text providers
- Export post-processors
- Manufacturing rulesets

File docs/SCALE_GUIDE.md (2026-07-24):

# Scale Guide

## Engine Model

Scale output is plugin-driven:
- values -> angle mapping
- tick generation
- labels generation
- geometry + preview
- validation

## Typical Config Tuning

- `majorStep` / `minorStep`: controls density.
- `radiusMm`: controls placement band.
- `tickDirection`: inside/outside/bidirectional.
- label orientation and placement settings.

## Validation Notes

Warnings report overlap, invalid domain ranges, and line-width violations.

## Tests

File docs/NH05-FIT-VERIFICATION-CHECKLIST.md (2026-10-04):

# NH05 ladies-watch fit verification checklist

Prepared 4 October 2026 from the TMI NH05B specification sheet and dated supplier research. All measurements are millimetres unless stated otherwise. This checklist does not certify fit by itself.

## Identify the exact parts first

- [ ] Record case supplier, URL, exact colour/bezel/bracelet variant, SKU, package contents and drawing revision.
- [ ] Record dial supplier, variant, date position and SKU.
- [ ] Record full three-hand set supplier, finish and SKU; charge its price once, not once per hand.
- [ ] Confirm the actual movement is NH05B, not NH35, and record the centre-post/hand-height type.
- [ ] Record source, check date, drawing page or photograph, instrument resolution, measurement uncertainty and reviewer for every value below.

Use a digital caliper for exterior dimensions, a depth gauge for shoulders and a microscope/pin gauges or a watchmaker for small bores. Calipers alone cannot reliably verify a 0.213mm seconds-hand fitting. Do not force hands onto posts or machine parts to make them fit.

For each measurement record: `actual value | tolerance/uncertainty | source + date | result (pass/fail/unknown)`. Blank values are unknown, not zero.

## Published reference - not supplier measurements

[TMI NH05B specification PDF](https://timemodule.com/upload/category/21/spec_sheet/NH05_SS.pdf), pages 5-10. Drawings use hundredths of a millimetre: divide their numeric dimensions by 100.

| Interface | TMI reference |
| --- | --- |
| Movement OD / casing OD | 17.50 / 17.20 nominal; use drawing tolerances |
| Dial support OD / height with support | 19.80 / 5.92 |
| Type M total maximum height including movement | 7.604 |
| Hour / minute / seconds post fitting | 1.100 (+0.006/-0) / 0.656 +/-0.005 / 0.213 +/-0.005 |
| Maximum hand tip radius | 9.50 |
| Type M hand levels A/B/C from dial | 0.62 / 1.01 / 1.37; review complete page-6 stack drawing |
| Reference dial thickness / centre opening | 0.40 / 1.65 +/-0.05 |
| 3 o'clock date aperture | 1.85 wide x 1.30 high; centre radius 6.825 |
| Dial feet F1 / F2 | (+7.4810, +3.4790) / (-8.0842, -1.6450), +y toward 12 o'clock |
| Dial feet diameter / length | 0.64 (+0.015/-0.010) / 2.00 (+0.05/-0.10) |
| Casing ring OD / movement seat | 19.80 (-0.02/-0.07) / 17.55 (+0.05/-0.01) |

The post fitting dimensions above are NOT measured hand-bore dimensions. Hand bores and their interference fits need the hand manufacturer's specification or a watchmaker's verification.

TMI's reference dial OD is 19mm. A supplier's 24.5mm aftermarket dial can overhang the support, but this does not prove its feet, thickness, date layout or case-seat fit.

## A. Case and movement holder

Supplier case candidate: [34mm Tandorio NH05 case](https://tandoriowatch.com/products/34mm-nh05-watch-case-bezel-insert-ring-sapphire-glass). Supplier says 34mm OD, 12mm thickness and 24.2-25mm dial range; photo labels 24.5mm. These are headline dimensions, not tolerance drawings. Do not copy the old provisional GLB's 10.5mm thickness or inferred internal interfaces into this product.

- [ ] Actual case OD and thickness, with supplier's inclusion/exclusion of back, crystal and protrusions recorded.
- [ ] Internal movement cavity diameter and usable depth, measured at every relevant shoulder.
- [ ] Actual movement-holder ID, OD, shoulder depth, retention method and stem cut-out.
- [ ] Dial-seat diameter, supporting shoulder width and axial depth.
- [ ] Rehaut opening diameter and overlap with the dial edge.
- [ ] Stem-axis height from the same dial-support datum and crown-tube orientation; check movement and case axes align without strain.
- [ ] Crystal underside height from that datum, across the full swept hand area; include gasket compression and any domed/magnifier low point.
- [ ] Caseback-to-rotor clearance with holder and back installed.
- [ ] Crown/stem engagement, winding and setting travel verified by a watchmaker; the drawing's reference stem length is not a pre-cut finished-case stem length.

Pass only with matching measured mating dimensions and tolerances, adequate running clearances and secure retention. Overall 12mm case thickness is not usable internal cavity depth. Diameter alone cannot confirm movement fit.

## B. Actual supplier dial

Candidate: [24.5mm white matte NH05 dial](https://tandoriowatch.com/products/24-5mm-watch-dial-nh05-white-matte-dial?variant=50672056467741). Supplier publishes OD and 3 o'clock date only; the app's nominal 0.4mm thickness is a clearly labelled presentation placeholder.

- [ ] OD, thickness and flatness measured, with tolerances.
- [ ] Centre opening size and alignment measured against the reference.
- [ ] Both feet positions (x/y), diameter, length and retention engagement match the actual NH05B movement.
- [ ] Date aperture centre, width, height and orientation match the movement; date remains readable through all dates, not just one.
- [ ] Dial sits flat on its intended support, is retained securely and clears the rehaut.
- [ ] Maximum applied-marker/lume height recorded in every swept-hand region.
- [ ] Rear dial features/feet do not interfere with movement parts.

Do not remove feet or approve adhesive mounting silently. Such changes require a separate modification plan and risk review.

## C. Actual hands

Candidate: [Tandorio NH05 luminous set](https://tandoriowatch.com/products/nh05-hands-silver-blue-black-gold-rosegold-watch-hands-green-luminous). Published centre-to-tip lengths are 5/8/8mm. Silver, gold, black, blue and rose-gold finishes are advertised, not guaranteed stock.

- [ ] Hour/minute/seconds centre-to-tip lengths measured separately; each <=9.50mm TMI maximum and inside the actual dial/rehaut envelope.
- [ ] Counterweight radius, width, thickness, tube height and underside offsets measured for each hand.
- [ ] Each bore fit verified against its correct post without forcing; NH35 hand sizes must not be substituted.
- [ ] Axial hand-stack levels measured from the same dial datum; verify dial/lume-to-hour, hour-to-minute and minute-to-seconds running gaps.
- [ ] Hand-to-crystal clearance checked across a complete sweep, including counterweights, crystal low points and tolerance stack-up.
- [ ] Full rotation has no collisions, rubbing, slip or distorted tubes; check setting and running operation.
- [ ] Unbalance meets TMI limits (hour 100, minute 75, seconds 11 mg.mm), or obtain manufacturer's evidence/watchmaker's professional assessment before certification.

A separate advertised 6.5/10/10mm set exceeds the published 9.5mm maximum tip radius. Do not approve it just because the seller calls it NH05-compatible.

## D. Approval and records

- [ ] Every critical value above has a source and uncertainty; no critical blank remains.
- [ ] Apply worst-case tolerances to each mating fit and clearance. Positive nominal clearance alone is not sufficient; use manufacturer's permitted fit/clearance or obtain professional assessment where limits are unspecified.
- [ ] Resolve any failed fit by choosing a measured compatible component, not by changing the recorded evidence.
- [ ] Record exact approved part IDs and verification date; only then promote the corresponding catalogue entry from draft/unverified.
- [ ] Keep commercial stock and delivered price checks separate: item + South African shipping + applicable taxes/duties, selected variant and timestamp.
- [ ] GLB presentation accuracy is separately assessed; photographs and visual matches do not certify hidden interfaces.
- [ ] Water resistance requires appropriate assembled-watch pressure testing, not supplier text or this dimensional checklist.

Current result: **UNVERIFIED - public supplier measurements are incomplete.**

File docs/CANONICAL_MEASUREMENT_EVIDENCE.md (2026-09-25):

# Canonical measurement evidence register

This register separates supplier claims from engineering evidence. A value is
eligible for canonical use only when three independent confirmations agree at the
declared precision. A manufacturer page and that manufacturer's drawing are
separate documents, but not independent manufacturers; the source count and
independence are recorded explicitly.

## Current decision

The application may continue using the existing rounded movement templates for
preview and compatibility demonstrations. The three-confirmation gate now
allows selected movement envelope values to be promoted to specified canonical
inputs; case, stem, crown, pusher, dial-seat, hand-stack, crystal-clearance,
and water-resistance values remain provisional or unknown.

The supplier records currently in `src/domain/catalogue/supplierListingRegistry.ts`
are marked `synthetic-demonstration-seed`. Their AliExpress URLs and SKUs are
placeholders, not live supplier evidence, and must not be counted.

## Movement confirmations

### NH35A / NH35

| Measurement | Canonical preview value | Confirmations | Status |
| --- | ---: | ---: | --- |
| Movement outside diameter | 27.40 mm | 3 direct/derived supplier or manufacturer records | specified |
| Dial-holding spacer diameter | 29.36 mm | 1 manufacturer drawing | unknown |
| Overall movement height | 5.32 mm | 4 records | specified |
| Hour/minute/seconds hand bores | 1.50 / 0.89 / 0.21 mm at 0.01 mm precision | 4 records; one technical source reports finer values | specified at rounded precision |
| Pusher count | 0 | manufacturer function/specification | specified |

Sources checked:

1. [TMI NH35 product line](https://www.timemodule.com/en/product_line_up/mechanical/mechanical/mechanical_NH0_NH3/)
2. [TMI NH35A specification and drawing](https://www.timemodule.com/upload/category/24/spec_sheet/NH35_SS.pdf)
3. [TMI NH3 technical guide](https://www.timemodule.com/upload/category/24/technical_guide/NH35_TG.pdf)
4. [Star Time Supply NH35 listing](https://www.startimesupply.com/merchant2/merchant.mvc?Product_code=NH35&Screen=PROD)
5. [Perrin Supply NH35 listing](https://perrinwatchparts.com/en-us/products/automatic_watch_movement_sii_nh35)
6. [Spring & Dial NH35/NH38 comparison](https://springanddial.com/calibers/nh38-vs-nh35)

The library's current `1.50 / 0.90 / 0.20` values remain intentionally rounded
preview values; the specified evidence is not a license to substitute finer
manufacturing tolerances.

### VK63A / VK63

| Measurement | Manufacturer value | Confirmations | Status |
| --- | ---: | ---: | --- |
| Outside diameter | 30.80 x 29.10 mm | 2 official documents | provisional |
| Casing diameter | 29.00 mm | 1 official technical guide | provisional |
| Overall movement height | 5.10 mm | 3 official documents/pages | specified |
| Pusher count | 2 | official chronograph function | specified |
| Pusher angular positions | not stated in the checked manufacturer documents | 0 | unknown |

Sources checked:

1. [TMI VK product line](https://www.timemodule.com/en/product_line_up/quartz/chronograph/premium_chronograph_VK/)
2. [TMI VK63 product-code page](https://www.timemodule.com/en/product_code_search/?code=VK63)
3. [TMI VK63A specification and drawing](https://www.timemodule.com/upload/category/33/spec_sheet/VK63_SS.pdf)
4. [TMI VK6 technical guide](https://www.timemodule.com/upload/category/33/technical_guide/VK63_TG.pdf)
5. [TMI VK63 operation manual](https://www.timemodule.com/upload/category/33/operation_manual/VK63_OM.pdf)
6. [TMI VK63 parts list](https://www.timemodule.com/upload/category/33/parts_list/VK63_PL.pdf)

## Controlled 42 mm case set: NMK901

The current fixture (`tools/blender/test_case_42.json`) is now aligned to the
single controlled case set selected in the supplied evidence package:
`SKX007_SRPD_42mm_Case_Set_Reference.pdf` and
`SKX007_SRPD_42mm_Expanded_Engineering_Reference (1).pdf`. The package identifies
namokiMODS NMK901 as a matched SKX007/SRPD case, bezel and crown bundle.

These values are promoted to specified preview inputs, not manufacturing
approval. The PDFs are retailer/manufacturer-reference compilations rather than
toleranced NMK901 CAD. Remaining interfaces now also carry temporary nominal
baselines for ordering and preview, explicitly tagged `ESTIMATED_NOMINAL`.

| Measurement | Controlled value | Evidence status |
| --- | ---: | --- |
| Case diameter | 42 mm | specified for preview |
| Lug-to-lug | 46 mm | specified for preview |
| Case-only thickness | 10.2 mm | specified for preview |
| Inside lug / strap width | 22 mm | specified for preview |
| Case material | 316L stainless steel | published |
| Crystal diameter | 31.5 mm | published, family match |
| Crystal middle thickness | 5.1 mm | published, family match |
| NH35 movement envelope | 27.40 mm diameter / 5.32 mm height | specified |
| Crown head | 7.0 mm diameter x 4.9 mm depth | specified, CT208 class |
| Pusher interfaces | none | specified for NMK901 |

The controlled configuration is NH35 + 28.5 mm dial + SKX007/SRPD chapter ring.
The expanded reference records CT252 chapter-ring geometry (30.5 mm OD, 27.5 mm
ID, 2.3 mm height, 1.5 mm radial body), a 28.5 mm dial, SKX hand lengths of
8.5 / 13 / 13 mm, and nominal NH35-compatible hand bores of 1.50 / 0.90 /
0.20 mm. These hand values are nominal family-fit evidence; broach tolerances
are not manufacturing dimensions.

### Estimated nominal interface baselines

These values use source `AI Nominal Baseline Estimation (SKX007/NH35 standard)`
and are temporary baselines awaiting physical micrometer validation on Golden
Sample #1. They produce engineering soft warnings, not hard manufacturing-fit
approval.

| Interface | Estimated nominal | Uncertainty | Status |
| --- | ---: | ---: | --- |
| Spring-bar hole diameter | 2.00 mm | ±0.10 mm | `ESTIMATED_NOMINAL` |
| Spring-bar hole center | 2.80 mm from lug tip / 1.20 mm from lower lug edge | ±0.10 mm | `ESTIMATED_NOMINAL` |
| Dial seat depth | 1.20 mm | ±0.08 mm | `ESTIMATED_NOMINAL` |
| Chapter-ring seat depth | 1.50 mm | ±0.08 mm | `ESTIMATED_NOMINAL` |
| Crown tube thread | M3.5 x 0.35 mm pitch | ±0.05 mm | `ESTIMATED_NOMINAL` |
| Crown tube bore | 2.10 mm | ±0.05 mm | `ESTIMATED_NOMINAL` |
| Stem engagement | 1.80 mm | ±0.05 mm | `ESTIMATED_NOMINAL` |
| Crystal axial gasket seat | 1.80 mm | ±0.10 mm | `ESTIMATED_NOMINAL` |
| Hand-to-crystal axial clearance | 0.65 mm | ±0.12 mm | `ESTIMATED_NOMINAL` |

Still unmeasured: crystal gasket groove, caseback thread/gasket groove, and the
physical confirmation of all estimated interfaces above. The case remains a
visual engineering reference; estimated nominal values are not toleranced CAD.

## Historical mixed-case research (not used by NMK901 fixture)

The second pass added useful wiring candidates without promoting a mixed case
set to canonical:

- The [official Miyota 8215 page](https://miyotamovement.com/product/8215/) confirms a 5.67 mm movement height and shows
  3H and 6H date-window variants. The existing `miyota-8215` movement entry
  can therefore continue driving date-window presentation, while its dial-seat
  and hand-stack values remain provisional.
- [Timebalife](https://www.timebalife.com/watch-tools-parts/seiko-nh35-36-4r36a-movement-case.html) reports a 42 mm NH35 case with a 28.5 mm fitting diameter, 22 mm
  lug width, and approximately 13.5 mm thickness.
- [Horology Beats](https://horologybeats.com/products/skx-case-brushed-gunmetal) reports a different 42.4 mm case with 45.6 mm lug-to-lug,
  22 mm lugs, and 9.1 mm thickness excluding the case back.
- [iBenifit](https://ibenifit.com/products/spb185-spb187-42mm-diver-watch-case-fits-nh35-nh36-aged-bronze) and [Made-in-China](https://www.made-in-china.com/showroom/739e69819358d61c/product-detailGfdRwYWCXmrN/China-316L-Stainless-Steel-Watch-Case-with-Sapphire-Crystal.html) report additional 42 mm NH35-compatible cases,
  but their lug and thickness claims do not identify the same SKU as the
  current fixture.

These sources are now recorded as sourcing leads only. The adapter can safely
wire movement-declared date positions, subdial positions, hand sizes and
chronograph pusher counts into the visual/debug model; it must not infer case
seat, stem, crown, crystal or pusher-engagement geometry from these mixed
listings.

## Prior exact-SKU resolution attempt (superseded by supplied NMK901 package)

Before the supplied NMK901 package was available, the strongest case candidate
was Tandorio `SMC39815-G01`. Its conflicting 42 mm / 49 mm / 20 mm / 14 mm
values are retained here as historical sourcing research only and are not used
by the current fixture.

The earlier search found no manufacturer drawing, second retailer record, or
independent measurement for that exact SKU. Similar NH35 cases report conflicting values:
22 mm rather than 20 mm lugs, 45.6 mm lug-to-lug, 13.5 mm thickness, or
15.5 mm thickness. Those conflicts establish that the values cannot be merged
into the selected SKU. The exact-SKU evidence count therefore remains 1, and
the case set stays provisional.

The Tandorio product page was also checked for linked PDFs or drawing references;
it exposes the SKU variants and descriptive dimensions but no engineering-drawing
download. This historical result no longer blocks the NMK901 controlled preview,
but it remains relevant to the distinction between published dimensions and
manufacturer CAD.

## Next evidence action

The next measurement pass is now limited to the remaining NMK901 interfaces:
spring-bar hole center and diameter, dial/chapter-ring seat depths, crystal
gasket groove and axial seat, caseback thread/gasket, crown tube thread/bore and
stem engagement, and the assembled top-hand-to-crystal clearance. Until those
values are measured or supplied from a toleranced drawing, the application must
keep the corresponding `ESTIMATED_NOMINAL` checks as soft warnings and must not
claim production fit.

The controlled ordering record is implemented in
`src/domain/ordering/controlledNmk901Order.ts`. It carries the temporary nominal
baselines with source, uncertainty, and warning status, and generates only the
one fixed NMK901 BOM. The physical measurement list is maintained in
[NMK901_GOLDEN_SAMPLE_BACKLOG.md](NMK901_GOLDEN_SAMPLE_BACKLOG.md).

## Attachment preview construction (September 24)

`ESTIMATED_NOMINAL` only: underside strap-clearance pockets and shared strap/spring-bar datums were added for visual assembly. The existing spring-bar hole coordinates remain unchanged (Y = ±20.20 mm, Z = −1.725 mm in the 42 mm watch frame). Pocket limits are |Y| ≥ 18.45 mm, Z ≤ 0.025 mm between the lugs. These are inferred presentation clearances, not supplier drawings or measurements.

The common strap eye uses 0.6 mm side allowance per side to clear all eight conventional preview lug styles; that makes a 20.8 mm presentation eye in the 22 mm gap, not a revised nominal lug width or qualified off-the-shelf strap. Radius values: eye 1.05 mm, bar body 0.95 mm, tips 0.85 mm; estimated tip engagement 0.9 mm. Reference strap thickness stays 3.2 mm, archetype straps 3.0 mm. See `tools/blender/attachment_preview.json` and the Golden Sample backlog. Geometric intersection checks are not evidence of machining fit, structural integrity, articulation or water resistance. Wire/integrated interfaces remain outside this check.

Chronograph-only pusher stems/collars overlap the existing buttons and midcase in the presentation asset; no pusher hardware was added to the NMK901 shared case or promoted to an orderable interface.

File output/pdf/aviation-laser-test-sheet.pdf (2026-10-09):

# AVIATION SCALE / LASER TEST SHEET

09 October 2026 | A4 | Print Actual Size / 100% - NEVER Fit to Page

Verify the 100mm bar before using any dimensional result. Reference artwork is not machine code.

A / Decimal hour | B / Knots / statute MPH
42 x 42mm artwork frame | 42 x 42mm artwork frame
100 ticks; 0.01h = 36s; one seam | 0-200kt / 300-degree linear sweep

Production vectors above retain white/red ink on a dark VIEWING background.
Use the separate monochrome SVGs for engraving preparation. Do not engrave these backgrounds.

DIMENSION CHECK / measure between the two end marks

100.00mm

20 x 20mm square

STROKE COUPONS (mm)

0.05 | 0.08 | 0.10 | 0.15 | 0.20 | 0.30

NOMINAL FONT-SIZE COUPONS (mm; not measured cap height)

0.25

0.50 115.1mph

0.30

0.50 115.1mph

0.40

0.50 115.1mph

0.50

0.50 115.1mph

0.60

0.50 115.1mph

0.80

0.50 115.1mph

TEST RECORD / no power, speed, passes or material compatibility are prescribed

Machine / lens: _____________ Material / finish / thickness: __________________

Sample ID: _____________ Operation / power / speed / passes: _________________

Measured bar: ______mm Smallest legible text: ______mm Stroke: ______mm

Contrast / coating / kerf / damage observations: _____________________________

Decision / operator / date: __________________________________________________

PREPARATION CHECKLIST

[ ] Outline SVG text in the manufacturing application; recheck dimensions and glyph spacing. [ ] Assign engraving vs cutting explicitly; suppress notes, coupons and frame/background fills. [ ] Use a scrap sample and the machine/material manufacturer's operating procedures.
[ ] Check actual annulus fit: this is a pilot chapter-ring specimen, not a supplier-fit certificate.
[ ] This is not an hour timer, automatic Hobbs record, or operational navigation approval.

Source: committed Milestone 5 production exports, 6c7204d. Font substitution disclosed. Page 1 / 1.

0.00

0m

0.10

6m

0.20

12m

0.30
18m

0.70
42m

0.80

48m

0.90

54m

0kt

0.0mph

20kt

23.0mph

40kt

46.0mph

60kt

69.0mph

80kt

92.1mph

160kt

184.1mph

180kt

207.1mph

230.2mph

200kt

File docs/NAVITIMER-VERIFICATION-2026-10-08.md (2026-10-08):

# Navitimer selected-disc verification and M3A handoff

8 October 2026. The selected Navitimer graduation/reference inventory is complete for a **disclosed reconstruction**, not a factory-exact reproduction. Citizen's already verified inventory is unchanged. M3A Citizen implementation is next; this separate Navitimer packet is prepared for M3B after the shared M3A workflow. No runtime artwork, supplier data, dashboard state or GLB was changed in this research pass. Neither branded runtime acceptance gate is enabled.

## Same verification recipe, three focused tasks

- Outer-ring agent: independently inspect/count every rotating sector, numeral and stroke class; reconcile dense 50–60 stubs.
- Inner-ring agent: independently inspect/count every fixed sector and pointer/caption identity, including omitted labels and seconds 36.
- Source/measurement agent: inspect the exact booklet, attempt same-artwork source recovery, reproduce native pixel/geometry measurements and independently review the reconciled packet.
- Root: inspect native/full-page/branch PDF evidence, reconcile disagreements, preserve the source bytes, update both inventories/plan and add deterministic regression checks.

The computer-use skill supported online source inspection, and the PDF skill supported page-aware visual inspection and native image extraction. Live browser PDF display was blank; the already saved booklet was inspected and its fingerprint verified. No fresh retrieval or higher-resolution recovery is claimed. Enlargements isolate branches but add no native information.

## Exact source, without model mixing

Reference identity remains `navitimer-booklet-training-disc-2026-10-07`: the coloured training disc on viewer page 2 of the [user-selected Breitling booklet](https://www.breitlingsource.com/images/manuals/slide-rule.pdf). It is an identified illustrated layout, **not a named production watch**. The separate 1967 AOPA cover/time-row layout and modern B01/Automatic/Navitimer World artwork were not substituted or merged.

| Evidence | Fingerprint / scope |
| --- | --- |
| Selected booklet | 17 pages; SHA256 `3DCF8EFF7382092F4A2883B9844D73EA70B89C27949A2C6F0FDF584063A014B0` |
| Viewer page 2 native photograph | 600×525 pixels; original xref 4 DCTDecode JPEG stream, 53, 146 bytes |
| Preserved JPEG | SHA256 `46A429FC5F62BC2F69BB101FC55F4D8F524938E9D5BAFB3F80751AEF9B951E4F`; [unmodified source](research/slide-rules/evidence/navitimer-training-disc-native.jpg) |
| Same-booklet operation | Viewer 7–17 / printed 6–26; viewer 12 / printed 16 defines fixed seconds 36; viewer 16–17 / printed 24–26 confirms red KM just right of MPH |

No sharper copy of this same artwork was recovered. The collector archive has the same scan; a previously referenced third-party training-image asset now displays a copyright-warning replacement and was rejected without bypassing it. Direct official PDF retrieval failed. Different watch/manual diagrams may corroborate operation, not supply the chosen disc's colours, graduations or font.

## Verified graduation schedule

Each ring has **210 unique positions**: 420 total. Outer review has 30 sectors; inner review has 26. All 56 counts are reconciled. Shared 100 is existing 10, never a second tick or numeral.

| Range, lower-inclusive / upper-exclusive | Increment | Intervals per ring |
| --- | --- | ---: |
| 10–15 | 0.1 | 50 |
| 15–25 | 0.2 | 50 |
| 25–60 | 0.5 | 70 |
| 60–100 | 1 | 40 |

The initial provisional outer 200 count was rejected after isolating tiny half-unit stubs: 50–55 and 55–60 each have 9 interior strokes/10 intervals, then 60–65 has 4 interior strokes/5 intervals. The inner agent independently reported the same transitions. This differs from Citizen's 225-per-ring table, particularly 25–30; do not reuse its schedule.

Numerical geometry uses `360*log10(value/10)`. Visual counts establish the schedule first; mathematical consistency alone cannot prove a source transcription.

## Numerals, stroke hierarchy and anchor placement

- Outer 30 printed numerals: integers 10–25, then fives 30–95.
- Inner 25 printed numerals: integers 10–25, then 30/35/40/45/50/55 and literal 7/8/9 for 70/80/90. MPH replaces an ordinary 60 caption. No inner 65/75/85/95 numeral, but those four strokes remain broad major ticks.
- Ordinary outer strokes extend outward from the common divider; inner strokes extend inward. Numeral runs are tangent-following, centred on their own graduation lanes; bottom numerals remain inverted rather than being automatically made upright.
- Integers 10–25 and fives 30–95 are broad majors. Between 25 and 60, unlabelled whole integers are thin intermediates and half-units are minors. Other noninteger subdivisions and units 60–100 except fives are minors.
- No reliably separate 10.5–14.5 half-unit length tier is established at this resolution. Minor classification is a source-compatible reconstruction with aliasing uncertainty, not borrowed Citizen hierarchy.

Coarse profiles in native photographic pixels, not physical manufacturing sizes:

| Ring / profile | Length range | Width range |
| --- | --- | --- |
| Outer major | 6–13 px | 3–4.5 px |
| Outer intermediate | 8–12 px | 1.8–2.7 px |
| Outer minor | 3–8 px | 1–2.7 px |
| Inner major | 15–18 px | 2–4 px |
| Inner intermediate | 13–17 px | 1–2.5 px |
| Inner minor | 11–13 px | 1–2 px |

Allow approximately ±2 px length /±1 px width, perspective and threshold dependence. The actual major 11 black stroke is approximately 18×3 px; the earlier rough polar sample at adjacent 11.1 is not used as a major 11 measurement. Connected inner/outer marks crossing the divider must not become a single outer length. Font files, true cap heights/baseline gaps, physical ring dimensions and factory ink specifications remain `null`. Later implementation must measure actual substitute glyph bounds, tick gaps and physical target envelopes.

## Nine distinct references, not nine extra numerical ticks

| Role | Ownership | Source identity and colour |
| --- | --- | --- |
| Unit 10 | Fixed | Solid red outward triangle and red 10; no box; numeral caption is owned by existing inner 10 |
| Hour-rate 60 | Fixed | Solid black outward triangle, black MPH; no ordinary 60 caption or duplicated black 60 stroke |
| Seconds 36 | Fixed | Unlabelled solid red outward triangle; **no printed 36 caption** |
| KM | Fixed | Solid red outward triangle, black KM |
| NAUT. | Fixed | Solid red outward triangle, black NAUT. |
| STAT. | Fixed | Solid red outward triangle, black STAT. |
| Unit 10 | Rotating | Solid red inward triangle and existing red outer 10 numeral |
| Rate 60 | Rotating | Solid red inward triangle and existing red outer 60 numeral |
| Unlabelled reference near 36 | Rotating | Small red inward triangle; compatible with 36 in both fits; operational purpose unconfirmed |

The old inventory's fixed printed 36 was incorrect: adjacent black 35 belongs to the ordinary numeral row. Both ordinary 35 and 36 remain. The extra outer pointer is independent from fixed seconds 36 and has no invented caption. Outer 10/60 hidden black-stroke underlays remain ambiguous, so the packet preserves **composite source footprints and one numerical station** rather than asserting factory omissions or adding duplicate ticks.

## Colour and registration limits

Fourteen separately sampled pointer/caption/ink/substrate roles are preserved; they are raw RGB scan approximations, not factory hex codes. The source PDF uses a historical display ICC colour space; the preserved original JPEG has no embedded ICC. These samples must not be promoted to calibrated original ink. The thin blue-grey common divider cannot yield a reliable isolated sample; its exact hex stays `null`.

The two apparent boundary ellipses have different centres, so a single ellipse is not a reliable angular registration. A disclosed concentric-circle projective model gives median 0.319 px / P90 0.715 px residual. It is an assumption about the photographed plane, not a measured factory camera. All number angles remain logarithmic; the image is not used to invent mathematical values.

Registering fixed MPH 60 at the top gives unit origin 79.86555°. Photographed outer phase 330.94515° (≈−29.05°, uncertainty ±3°) is recorded for evidence comparison, **not silently applied as a runtime default/zero**.

Exact conversion ratios remain 1.852 km per nautical mile and 1.609344 km per statute mile. The constrained source fit yields KM 61.20536, NAUT 33.04825 and STAT 38.03125, with angular residuals approximately −1.017°/+0.502°/+0.515°.

An independent fit using nine reviewed fixed major strokes gives KM 60.81762, differing by 0.38773. Its fitted anchors stay within 0.482°, but the **withheld 11 validation fails at −2.3524°**. This failure is stored, not omitted. Absolute registration is therefore approximate: recommended nominal reconstruction KM ≈61±1, with all three conversion pointers derived as one exact-ratio group. Packet decimals preserve the source calculation; they are not manufacturer-specified anchor values or a claim of factory-exact geometry.

No HH:MM row or dedicated weight/volume/fuel-oil captions appear on this selected disc. The global excluded-annotation policy remains enforced; coincident ordinary numerical marks and gaps are retained. The distinct 1967 AOPA variant still has no accepted complete graduation table and remains separate.

## Durable handoff

- [Verification packet](research/slide-rules/navitimer-training-disc-verification.json): 420 numerical positions, 56 reviewed sectors, 55 numeral runs, 9 pointer identities and disclosed measurements/limitations.
- [Read-only measurement helper](research/slide-rules/measure-navitimer-source.py): reproduces pixel masks, fitted models, sample palette and sensitivity from native evidence; optional original-PDF provenance checking. It outputs JSON and does not edit the source.
- [Combined inventory](research/slide-rules/graduation-inventory.json): 126 mark records, including 106 numerical labels, 13 reference identities and 7 excluded-annotation identities; all 108 Citizen/Navitimer sectors counted. These mark records are not the full graduation count; per-reference packets are authoritative.
- [Validators](research/slide-rules/validate-inventory.mjs) and [Navitimer regression tests](../src/tests/navitimerReferenceInventory.test.ts): distinguish recorded source facts from runtime/factory acceptance and prevent schedule, caption, pointer-colour, provenance or model-mixing regressions.
- [Updated milestone plan](MILESTONE-PROMPTS-HYBRID-SLIDE-RULES-2026-10-07.md): M2 complete; Citizen M3A next; Navitimer M3B afterwards; GLBs remain behind the artwork/appearance dependencies.

## Verification and repository state

- Full suite: **537 tests across 73 files pass**, including 18 new Navitimer tests and 11 Citizen tests.
- Typecheck, lint and production build: pass.
- Combined/Citizen/Navitimer research validators: pass; 108 counted sectors, no uncounted sectors.
- Native measurement output reproduces the packet exactly; source JPEG hash matches.
- Citizen inventory/manifest subsets are unchanged; Citizen packet and separate 1967 plan remain byte-identical to HEAD.
- `git diff --check`: pass; new text files are also checked for trailing whitespace.
- Existing non-blocking warnings remain: Three CJS deprecation, Zod comment annotations and large build chunks. Git also reports normal LF-to-CRLF conversion warnings.

Changes are uncommitted. No commit, push or new milestone implementation is part of this verification request.

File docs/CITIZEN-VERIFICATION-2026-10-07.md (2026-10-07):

# Citizen JY8078-01L verification

7 October 2026. Reference research only, using the computer-use and PDF skills and three focused review agents. **Citizen's photographic reference is ready for Milestone 3A implementation with the disclosed approximations below.** This is not a completed Citizen renderer, a factory-exact reproduction certificate, or acceptance of the still-incomplete Navitimer reference.

## Evidence recovered

The selected model has not changed. The [official Canada product page](https://www.citizenwatch.com/ca/en/product/JY8078-01L.html) publishes a **1600x2000** `data-zoom-image`/`data-extra-large-screen-image`, not only its 500x625 display image. The [official Germany exact-model page](https://de.citizenwatch.eu/de/p/jy8078-01l/) publishes a **2000x2000** front image in its actual responsive `srcset`. Native dimensions and all four quadrants were inspected in the browser. No URL-resolution guessing or screenshot upscaling was used to manufacture detail.

The two images appear to be transforms of the same base photograph, not independently photographed specimens. The Canada image has the larger usable watch circle. Their unmodified bytes and fingerprints are retained under `research/slide-rules/evidence`; they are research evidence, not application textures or GLBs. Exact-model Spain/Thailand pages remain identity/layout corroboration.

The U680 manual's eleven calculator pages, viewer 82-92 / printed 81-91, were visually re-inspected using the existing rendered contact sheets. These establish operation only. Its generic Model 2 HH:MM row must not be imported into JY8078-01L artwork.

The Europe winter 2022/23 catalogue's large macro photograph depicts the rejected bracelet variant with a dark fixed strip/yellow distance pointers. Its small leather-model product picture does not supersede the recovered native front image. No mixing of those layouts is allowed.

## Complete circumference

Separate agents counted the outer and inner rings independently; root reviewed the native manufacturer imagery, reconciled the schedules and source exceptions, and checked the mathematical materialisation. A third reviewer corroborated pointers, palette, high-value sectors and the absolute conversion-group fit. These are separate reviews, not claims of independent photographic captures.

| Values, upper bound excluded | Increment | Intervals per ring |
| --- | --- | ---: |
| 10-15 | 0.1 | 50 |
| 15-30 | 0.2 | 75 |
| 30-60 | 0.5 | 60 |
| 60-100 | 1 | 40 |
| Total | One 100/10 seam | **225** |

All **52 Citizen review sectors** are now counted. The packet records **450 stable graduation identities**, underlying values, printed text or its absence, classes, measured profiles, colour roles, directions and sector/source provenance. Values are enumerated from the visually counted schedule; angles are then computed logarithmically, never interpolated at equal angular spacing. A graduation position is not necessarily an ordinary line: outer 60 is a solid triangular reference.

Outer printed numbers: 10-25 by ones, then 30,35,40,45,50,55,60,70,80,90. Inner numbers are the same except no ordinary printed 60: the hollow hour-rate reference occupies that identity. Long unlabelled marks must not acquire invented numerals.

**Length hierarchy also changes at 25**, although the numerical increment remains 0.2. The detailed profiles in the packet supersede early coarse estimates. In particular, outer 32.5 is short, not a long midpoint; 31-34 are intermediate. The 10-15 half-unit strokes and 65/75/85/95 are long without extra numeral labels. Do not use one globally uniform minor-length/class table.

## Corrected identities and typography

- Inner 10 is dark lettering in a yellow rectangular box, not yellow lettering. Outer 10 is dark lettering in a light box. Their ordinary graduation colours remain independent.
- Fixed 60 uses a **hollow light inward-pointing triangle**. The separate tiny **filled yellow outward-pointing triangle** immediately right is KM; KM lettering is light. Earlier low-resolution notes conflated these pointers and are superseded.
- STAT and NAUT use **red outward-pointing pointers**, with separate light captions.
- RX/NO and H/M/L are watch-function graphics, not calculator captions. Inner50/60 strokes are shortened square/rectangle shapes above NO/RX; neighbouring49,49.5,59,59.5,61 also shorten to approximately7px. All seven exceptions are recorded. Excluding radio text must not silently invent ordinary long replacement strokes.
- Both number rows follow tangents. Bottom numbers remain inverted, not automatically flipped upright. Numeral-run centres align with their own graduations; do not align their left edges or shift mathematical ticks for kerning.
- No HH:MM row or dedicated seconds-36 index occurs on this selected photograph. Ordinary graduation 36 remains. Do not expose either absent feature as Original artwork.

Representative source-pixel glyph bounds, measured cap heights, tick widths/lengths and gaps are recorded in the packet. Outer 55 and 20 have approximately 28px ink cap height and a 3px nearest visible ink-to-tick gap in the native Canada image. Fixed numeral samples have approximately 15-22px cap height, varying with perspective/rotation. Manual fixed-row bounds carry +/-5px uncertainty; pixel-component measurements carry approximately +/-2px. They are reconstruction targets, not manufacturer millimetres, font baselines or certified kerning metrics. The renderer must resolve actual substitute glyph bounds and verify the resulting gaps during M3A.

The connected inner-10 stroke has an observed clipped lower bound around 22px. Its recorded 29px upper extent is a reconstruction estimate informed by adjacent major strokes, not a directly recovered endpoint.

## Absolute distance placement

The pointer group was fitted to the **graduation plane**, not guessed from clock positions or the raised hand hub. A robust white-strip inner-edge fit used 306 accepted samples: centre approximately (752.959,994.709), ellipse semiaxes 451.133/448.527 source pixels; median residual 0.272px, 90th percentile 0.626px.

Using the hollow 60 index as the registration datum, the ratio-constrained source fit is:

- KM: **61.055605**, photographic fit, not factory specification.
- NAUT: KM / 1.852, approximately **32.967389**.
- STAT: KM / 1.609344, approximately **37.938194**.

Observed pointer residuals are approximately +0.0550,-0.0312,-0.0238 degrees, below 0.1 degree. Nominal KM is approximately 61.0 with a conservative +/-0.5-value photographic uncertainty. Retain the fitted anchor and exact ratios together; do not round each pointer separately or adopt the previously suggested unsupported 61.5. Register fixed 60 at the top and derive the shared unit origin as `360 - 360*log10(6)`; outer relative rotation is independent.
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

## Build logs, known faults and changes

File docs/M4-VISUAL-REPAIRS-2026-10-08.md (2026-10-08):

# Milestone 4 visual exception reconciliation

8 October 2026. Milestone 4 checkpoint published as `531bf2f`; its continuation schedule was deleted at the user's request. This follow-up does not start Milestone 5.

## Repairs

- Engineering band validation now retains the canonical physical assembly projection rather than rechaining purchased parts from stale global width defaults. Dial printing is constrained by both the actual blank and chapter opening; visibility, colour and locks follow their components.
- Marker synchronization preserves authored inset and clamps inward only when necessary. Conservative numeral bounds stay inside the dial; date-overlapping hour glyphs are omitted without moving angular stations.
- Shared automatic dark/light marker contrast preserves explicit user colours and reference scale inks. The inspector displays the resolved automatic colour and explains how a custom override is created.
- HD replaces baked hour markings with current canonical hour artwork below the crystal, avoiding duplicates and allowing live shape/colour updates. Non-glyph indices remain physical meshes; date artwork is shared. Painted minute markings are no longer reflective silver metal that washes out a dark tint.
- HD date apertures use in-plane dimensions, not axial part thickness; clock positions use north=0 degrees. Unsupported day-window placeholders are excluded on date-only movements, while explicit part visibility is retained.
- Shared Engineering/HD grain uses bounded illustrative roughness/micro-bump. It is not a measured factory surface or a new GLB.
- Versions now persist validated design/sourcing snapshots in browser storage, with bounds, safe failure warnings and newest-eight automatic retention. Live Save/reload confirmed the record remains present. Project export remains the portable backup.
- Export SVG rings now have true transparent annular holes instead of repainting the dial with a dark background. Actual dial fill, hour glyph geometry/contrast and typography are shared by SVG/PDF/DXF. DXF contains physical-mm text/entities, not automatically outlined fonts.
- Microscopically adapted reference text below 0.10 mm is refused; practical selected line-profile readability warnings remain visible. Colliding unit captions search for a safe radial position within the physical annulus, preserving calibrated angles and ticks; impossible caption fit refuses export.

## Actual-file verification

`export-qa.html` is a developer-only page using production SVG, DXF and PDF functions, without mutating the active project. `scripts/export-qa-collector.mjs` temporarily accepts bounded, fixed-name blobs on loopback only. Retained QA fixtures are under `output/pdf/`: 42 mm pilot Navitimer, 42 mm pilot Citizen, and 34 mm ladies Simplified dress artwork. PDF pages are 60 x 60 mm; Poppler inspection checks the actual vector files, not screenshot exports. The inappropriate 34 mm Citizen fixture is retained only as ignored negative evidence in `tmp/pdfs/negative-fixtures/`.

Final integration verification: **683 tests across 89 files pass**; TypeScript checks, lint, production build and whitespace checks pass. Existing non-blocking dependency annotation/deprecation and bundle-size warnings remain. Poppler reports an unavailable standard Symbol display font, but the used glyphs render visibly in the inspected QA pages.

Live browser acceptance covered normal Engineering and Advanced geometry, pilot HD, silver-to-dark dial colour changes, explicit rose-gold numerals, restoration of automatic dark silver-dial numerals, brushed direction 0/90 and sunburst controls, and saved-version reload. The final HD screenshot shows both physical scale rows, dark canonical hour numerals and one readable date window rather than the thin aperture or duplicate boxes. Silver finish grain remains subtle through sapphire lighting; the inspector close-up is illustrative, not a promise of photographic factory surface fidelity. Cross-archetype geometry and date capabilities are covered by regression tests, not claimed as an exhaustive new live audit of every possible combination.

## Limits that are not software defects

Supplier fit, laser/material/kerf trials and 1:1 readability remain physical verification steps. Substitute fonts require outlining in the manufacturing application. Reference radial caption adaptation is disclosed, not factory reproduction. Illustrative HD finishes are not measured roughness. No supplier certification, new procurement research or Blender asset regeneration is claimed.

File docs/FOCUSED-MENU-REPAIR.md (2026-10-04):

# Focused right-side menu repair — 2026-10-03

## Audit extension

The browser audit exercised the remaining dial index choices, lettering select, Search all components and the modern/legacy inspector switch in addition to the earlier right-tray Options/Style/Suppliers/Details/Manufacture checks. Index choices selected correctly and all-component search expanded from 0 to 84 options when no physical context was selected. Legacy controls expose nominal/reference geometry; they are not a substitute for actual part interfaces.

This is not an exhaustive certification of every supplier, upload, GLB combination, legacy field or manufacturing output. No purchase, supplier contact, destructive action, commit or push was performed.

## Implemented

- `ControlledBomPanel.tsx`: replaced the misleading fixed NH35 kit approval with active assembly components, movement, actual case size, compatibility, readiness and planning total. Explicitly not order approval.
- `LeftNavRail.tsx`: BOM badge now reflects assembly compatibility instead of remaining green during red errors.
- `CostBomSummary.tsx`: removed “Verified Components” wording from estimated selected-component prices.
- `defaultBuilds.ts`, `StarterBuildPanel.tsx`: fresh platform prevents carrying ladies NH05 physical parts into larger NH35 starters. Preserves the reviewed reference-42 NH35 rendering fixture and authored NH35 case frame to avoid regressing existing HD placement. Clears supplier selections after saving the pre-starter backup. All starters are presentation-only; kit reasoning is clearly distinguished from the actual BOM.
- `AdvancedModePanel.tsx`: diameter editor writes canonical part dimensions, clears obsolete parametric geometry/provenance, reflects the current component and no longer applies a universal NH35 dial limit. The five unavailable CAD layers are disabled with an explicit explanation; datums/radii remain schematic guides.
- `storeSync.ts`: canonical global case dimensions take priority over stale legacy geometry parameters (ladies case now shows 34, not 42).
- `configuratorUIStore.ts`, `OptionsTab.tsx`: incompatible replacement previews expose their error before Apply, both buttons respect errors, texture-only Apply validates that it changes no geometry. Existing build errors remain visible; finish changes do not manufacture a green approval.
- `watchAssemblyStore.ts`, `TopToolbar.tsx`: bounded 50-entry canonical assembly history supports live Style/CAD Undo/Redo. It does not claim to undo supplier, scale-session or viewport changes.
- `menuRepairRegression.test.tsx`: six regressions covering platform reset, canonical dimension priority, history, actual BOM rendering, unfinished overlays and texture-only validation.

## Verified

- Browser: active BOM now reports NH05 / 34 mm / RED Needs compatibility review, matching the restored design rather than approving an NH35 kit.
- Browser: silver → navy → Undo silver → Redo navy.
- Browser: Minute Hand diameter 8.82 → 10 persisted into Details. The change was subsequently restored from the checkpoint.
- Browser: Matte texture preview Apply produced “Applied ✓” and Details showed matte, without suppressing the red physical errors.
- Original verification checkpoint restored afterwards; silver dial / rose-gold presentation / 8.82 mm minute hand retained. In-app checkpoint left intact.
- Full suite: 400 tests passed; typecheck, lint, production build and diff whitespace verification passed. Non-failing bundle-size / third-party annotation / Three.js deprecation warnings remain.

## Explicit remaining work

The pre-existing NH05 design remains incompatible: several engineering rules still fall back to catalogue/default NH35 bore, reach, cavity and rehaut values even when the visible dimensions/variant have changed. This pass deliberately does not invent supplier fit evidence or alter those engineering facts to turn the build green. Next repair should unify those rules with actual selected-component engineering properties and distinguish measured, provisional and overridden dimensions.

Legacy nominal band readouts, project movement-note synchronization, placeholder Help pages, full measured CAD overlays and actual fabrication exports are not completed in this pass. Import/export/download, all lug/subdial variants and live external search results need separate end-to-end coverage. The existing GLB/colour work was preserved; no new GLBs were generated here.

All repository changes remain uncommitted.

Follow-up: see `REMAINING-MENU-REPAIR.md` for the completed NH05 data-source, legacy readout and Help repairs. The earlier remaining-work list above records the state of the first pass, not the follow-up status.

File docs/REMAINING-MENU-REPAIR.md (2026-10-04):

# Remaining focused menu repairs — 3 October 2026

This follow-up completes the NH05 data-source correction, legacy dimension/movement readouts, and Help documentation from the focused menu audit. Existing uncommitted colour, GLB, sourcing and menu repairs were preserved. No commit or push was made.

## Completed

- `compatibilityHelpers.ts`: prefer the visible midcase over lugs; resolve selected-part engineering properties and catalogue interfaces.
- `movementCaseRule.ts`, `caseDialRule.ts`, `chapterRingCaseRule.ts`, `crystalCaseRule.ts`, `bezelCaseRule.ts`: use the selected case interfaces. NH05 no longer inherits NH35 cavity/rehaut defaults. Missing NH05 shoulder/rehaut data stays unknown.
- `boundaryResolver.ts`: NH05 movement envelope and centre opening use the existing TMI reference record rather than NH35 defaults.
- `movementHandsRule.ts`, `handsClearanceRule.ts`: inspect visible hands, selected bore specifications and actual central-hand reach. Unknown central hand fittings are reported rather than skipped. NH05 axial stack requirement uses the published Type M reference.
- `defaultBuilds.ts`: fresh ladies starters no longer retain NH35 catalogue IDs for minute/seconds hands. Supplier fitting measurements remain unverified.
- `compatibilityEngine.ts`: draft/AI-extracted selections remain unknown after Apply, rather than losing their evidence warning.
- `applyCatalogueVisualSelection.ts`: replacements clear inherited engineering metadata and stale parametric geometry/provenance.
- `DetailsTab.tsx`: evaluate the live assembly rather than substituting a nominal catalogue candidate; clearly distinguish design dimensions from supplier measurements.
- `dateWindowMovementRule.ts`: unrelated candidate notes such as a 0.656 mm hand fitting no longer imply a six-o’clock date window.
- `RightInspector.tsx`, `storeSync.ts`, `projectStore.ts`, `ProjectWorkflowDialog.tsx`: geometry-derived band diameters and movement recommendations follow the active assembly. Project movement is an explicit read-only calibre readout, not an ineffective second movement selector. User-authored notes are preserved.
- `helpDocs.ts`, `HelpCenter.tsx`: all 29 topics contain practical instructions and explicit limitations, with scrollable navigation and labelled Close buttons.
- `remainingMenuRepair.test.tsx`: five regressions for NH05 interfaces, edited dimensions, movement switching, Help coverage/link integrity and false date-position parsing.
- `physicalCompatibilityPhase5.test.ts`: corrected the legacy false-green expectation. Default presentation assembly has an overlong central hand for the usable aperture and draft case data; it must not be certified green.

## Verification

- Full automated suite: **405 tests passed in 61 files**.
- Typecheck, ESLint, production build and `git diff --check` passed.
- Existing non-failing bundle-size, third-party annotation and Three.js deprecation warnings remain.
- Computer-use browser verification: Help opens and shows the new Movement Integration instructions; Project Information shows NH05; Advanced shows the current 34 mm case and 8.82 mm minute hand.
- Browser: changing minute-hand reach to 15 mm produces a live 15.0 mm clearance failure in Details rather than checking its nominal 13.5 mm catalogue version. The original 8.82 mm design was restored before further source updates.
- Browser Visual smoke check: the preserved silver dial, rose-gold case/hands/markers and diamond bezel load. No new GLBs were generated in this follow-up.

## Remaining limitations — not concealed as completed features

- The user's preserved older ladies design still contains a selected NH35 minute-hand catalogue reference. Its NH05 bore mismatch is real relative to that catalogue ID; changing displayed length or colour does not verify a new fitting. Fresh ladies starters now use unverified NH05 hand-set references instead. Supplier bore, tube-height and seating evidence is still needed.
- Case/rehaut/shoulder and supplier-exact compatibility are not certified by the visual GLB or matching nominal diameters. Draft parts and missing interfaces remain unknown.
- The disabled full measured CAD inspection overlays and a released fabrication-export workflow are separate feature work, not completed by this focused data/UI repair.
- Import/export downloads, supplier checkout prices/shipping, every asset variant and full hand/subdial visual permutations were not re-audited end to end in this pass.

All repository changes remain local and uncommitted. The development dashboard is available at http://127.0.0.1:3000/.

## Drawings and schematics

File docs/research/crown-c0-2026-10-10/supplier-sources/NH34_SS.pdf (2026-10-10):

## Watch Movement Specification and Drawing

# NH34A

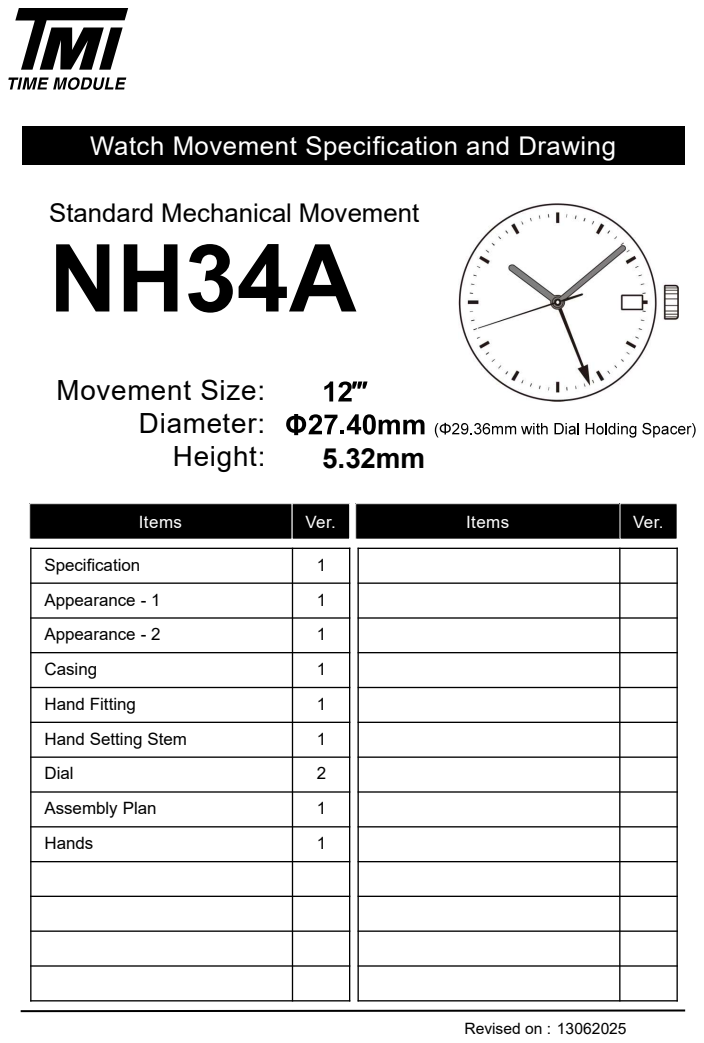
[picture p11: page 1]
Movement Size: Diameter: Height:; Items; Ver.; Revised on :

Standard Mechanical Movement

Specification | 1
Appearance - 1 | 1
Appearance - 2 | 1
Casing | 1
Hand Fitting | 1
Hand Setting Stem | 1
Dial | 2
Assembly Plan | 1
Hands | 1

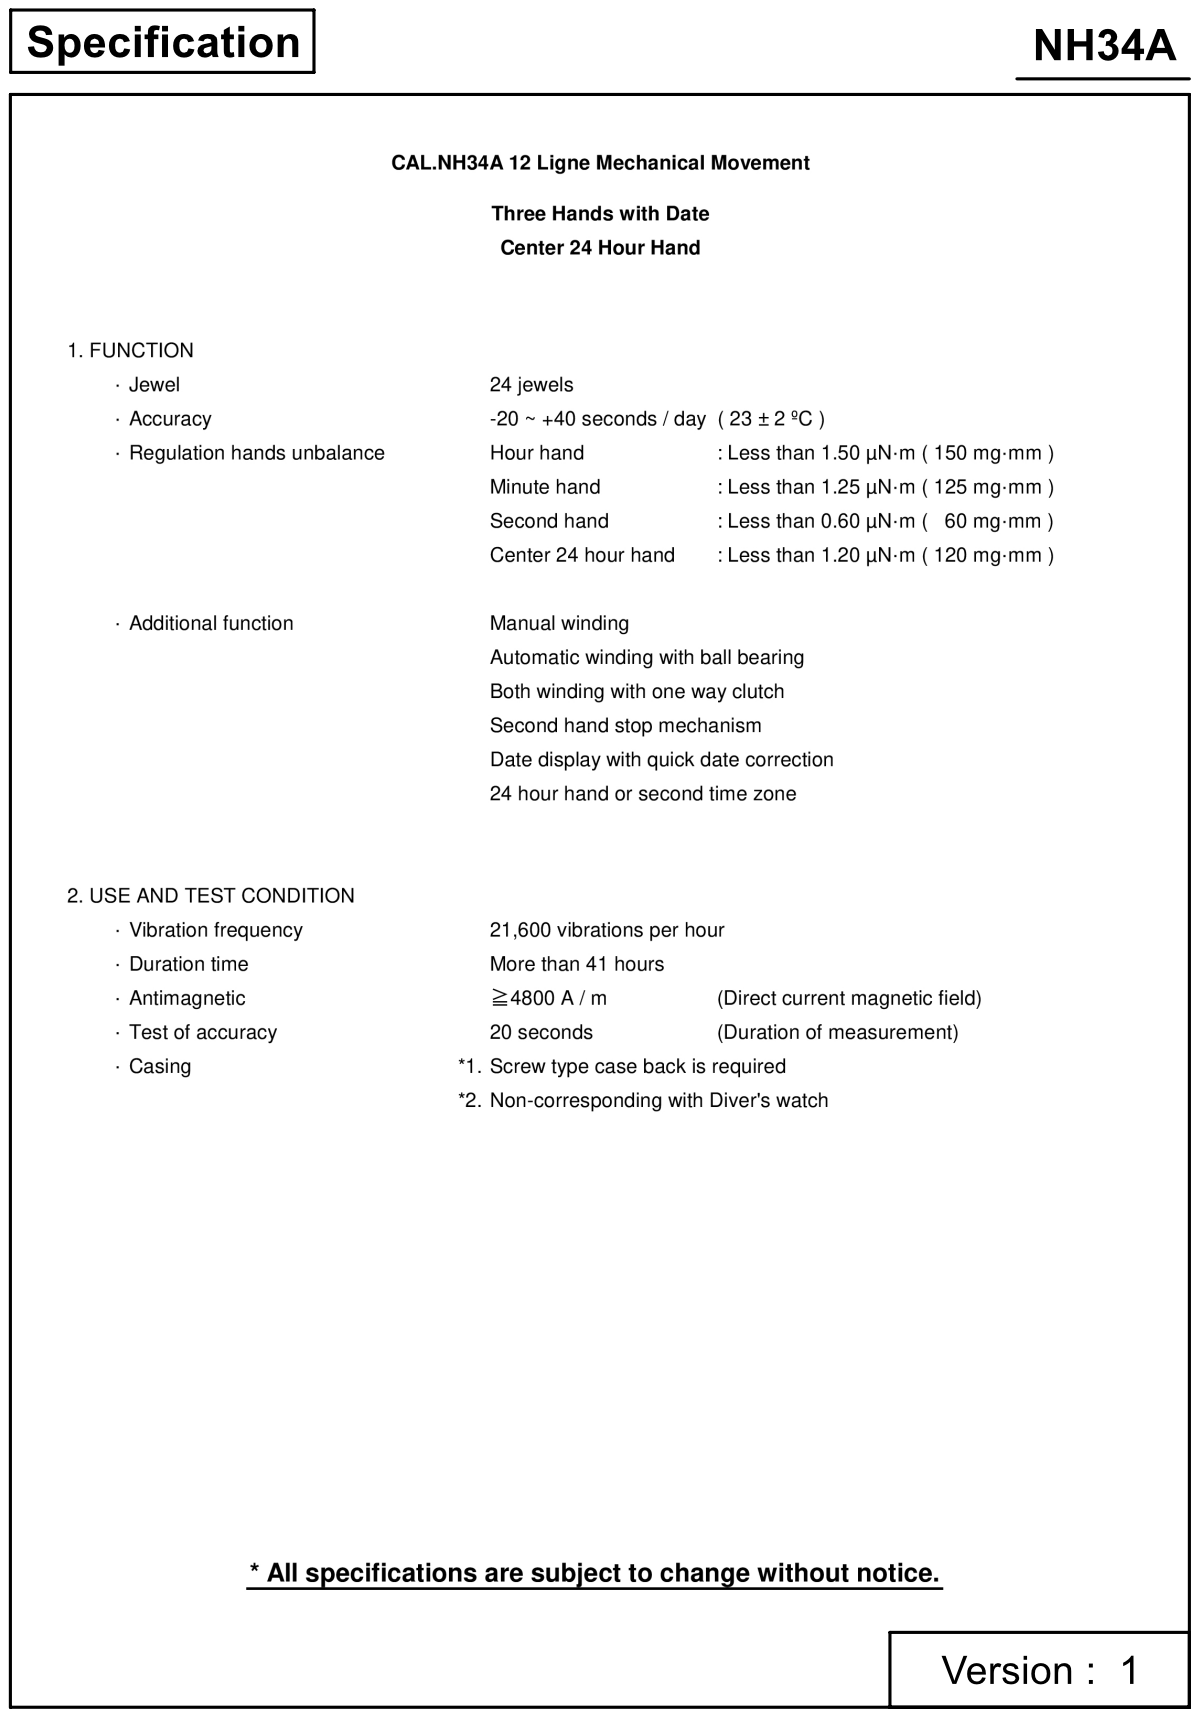
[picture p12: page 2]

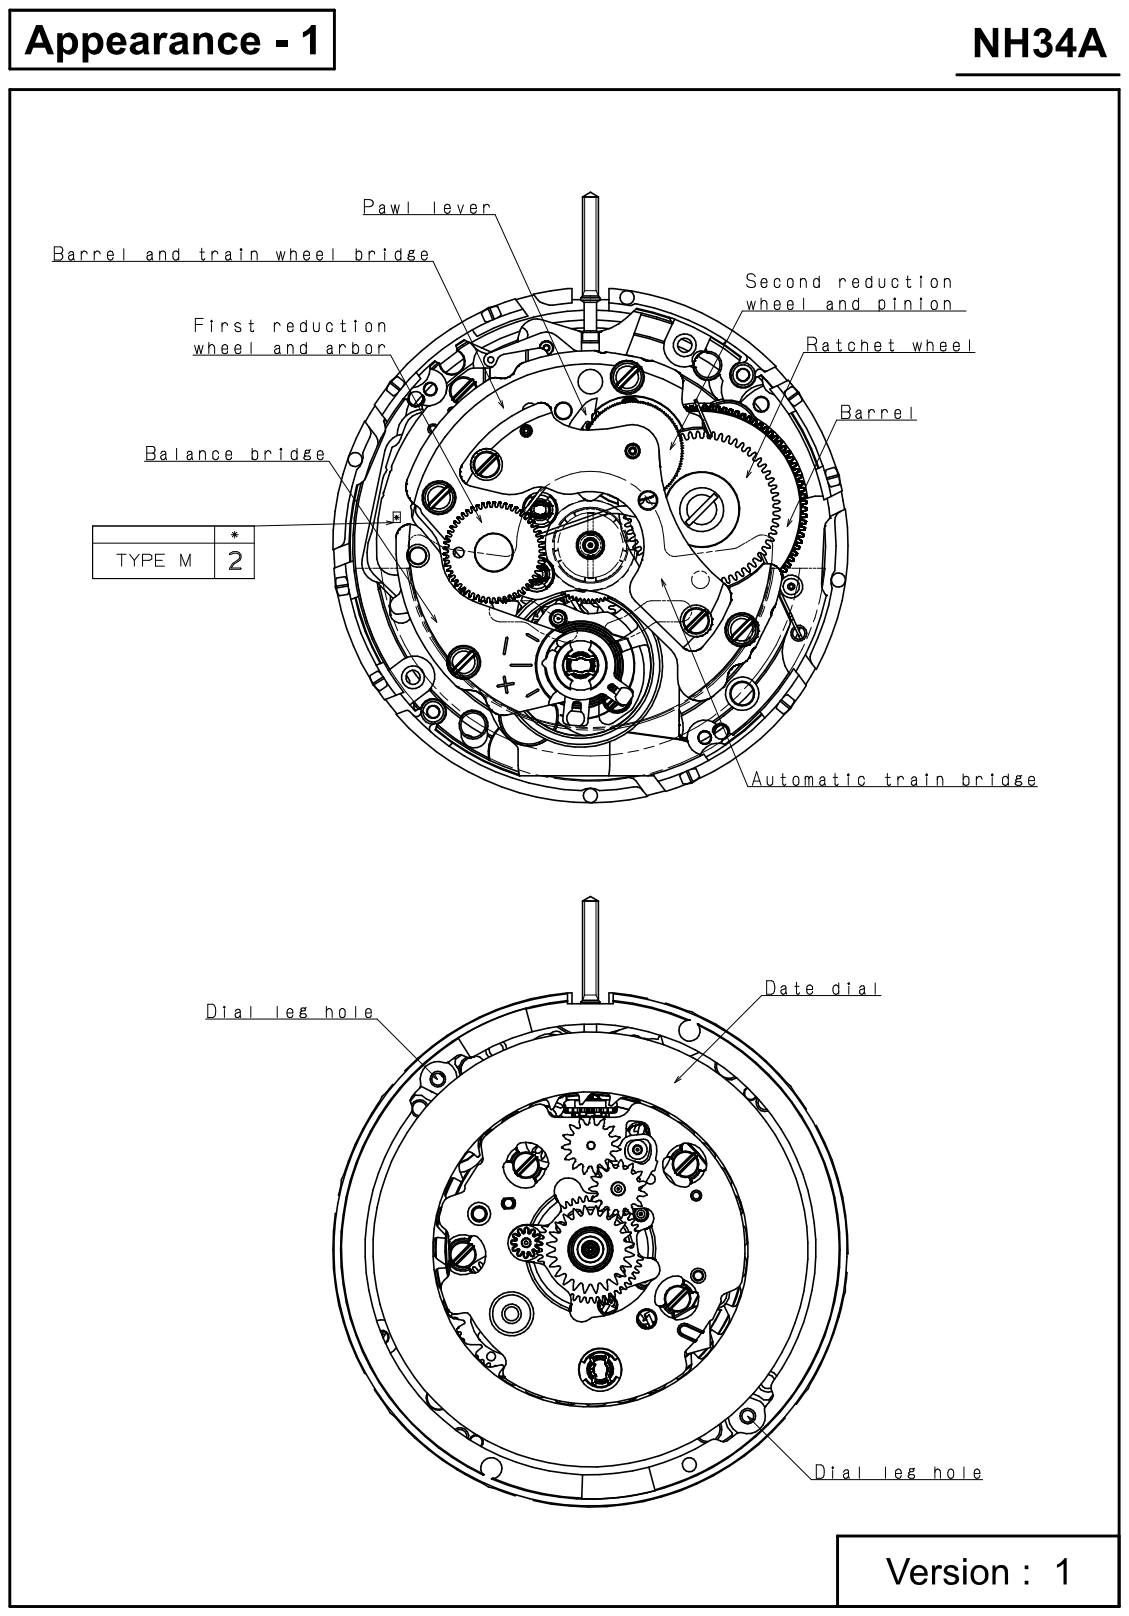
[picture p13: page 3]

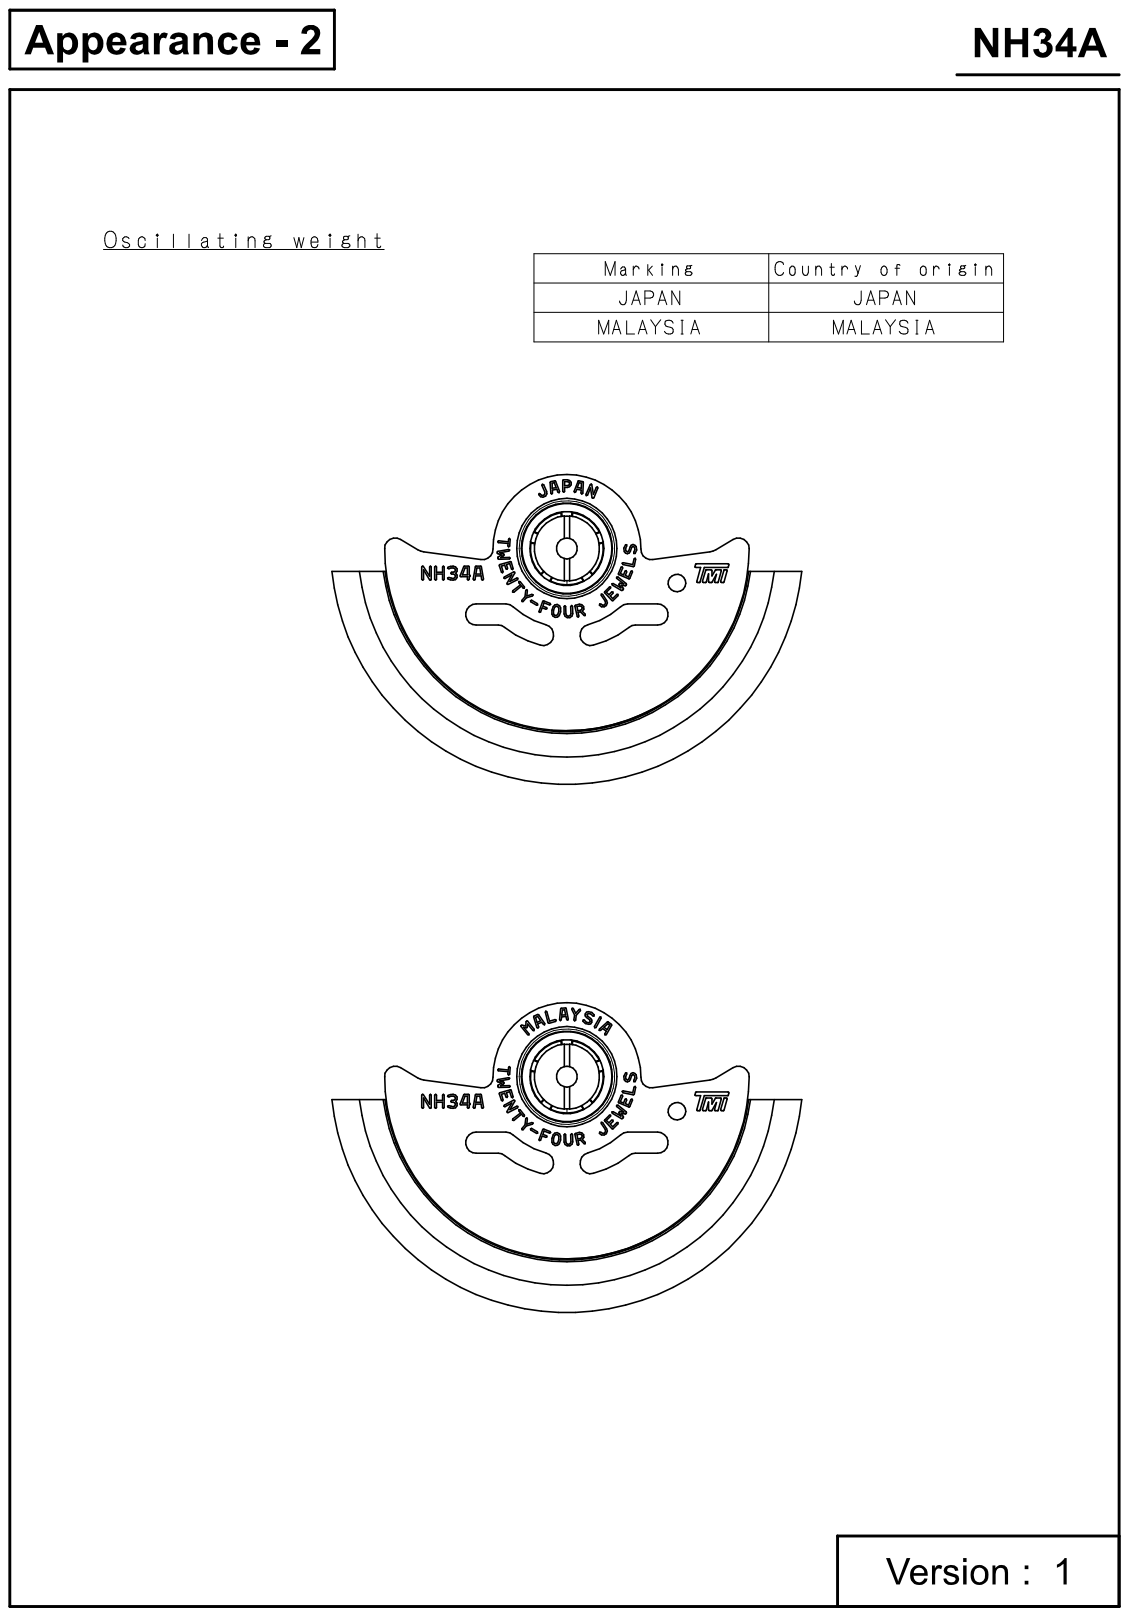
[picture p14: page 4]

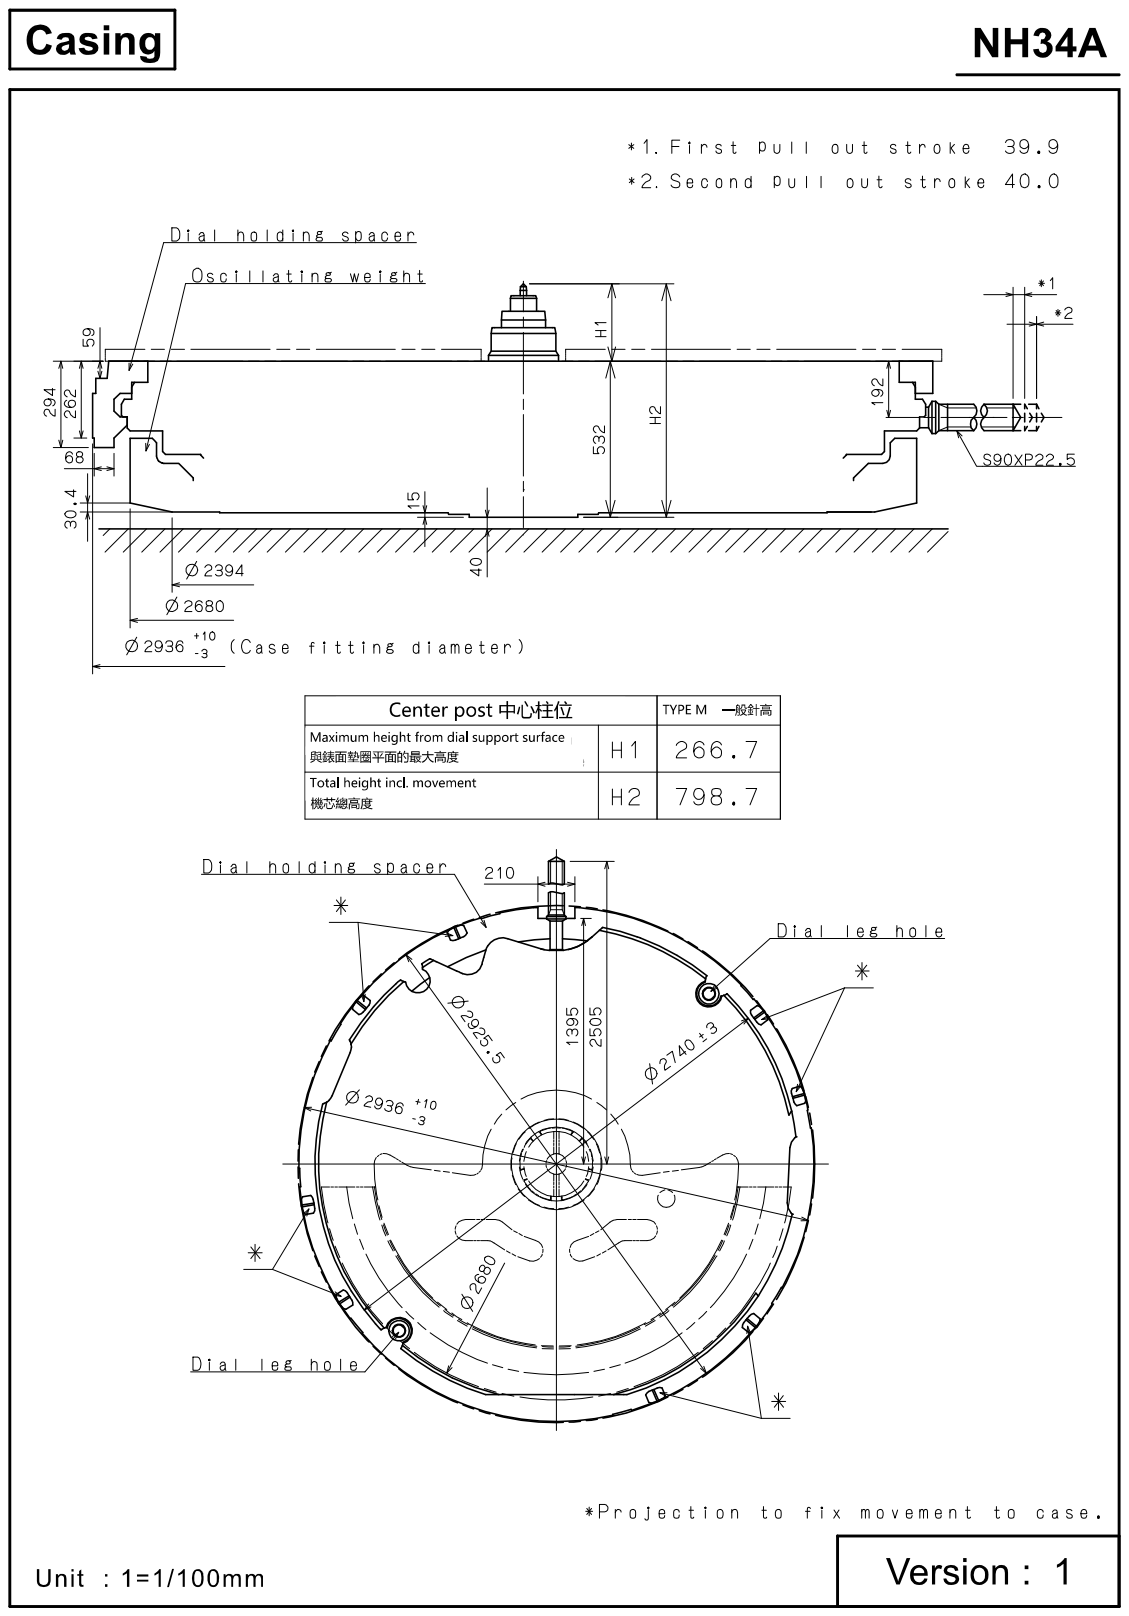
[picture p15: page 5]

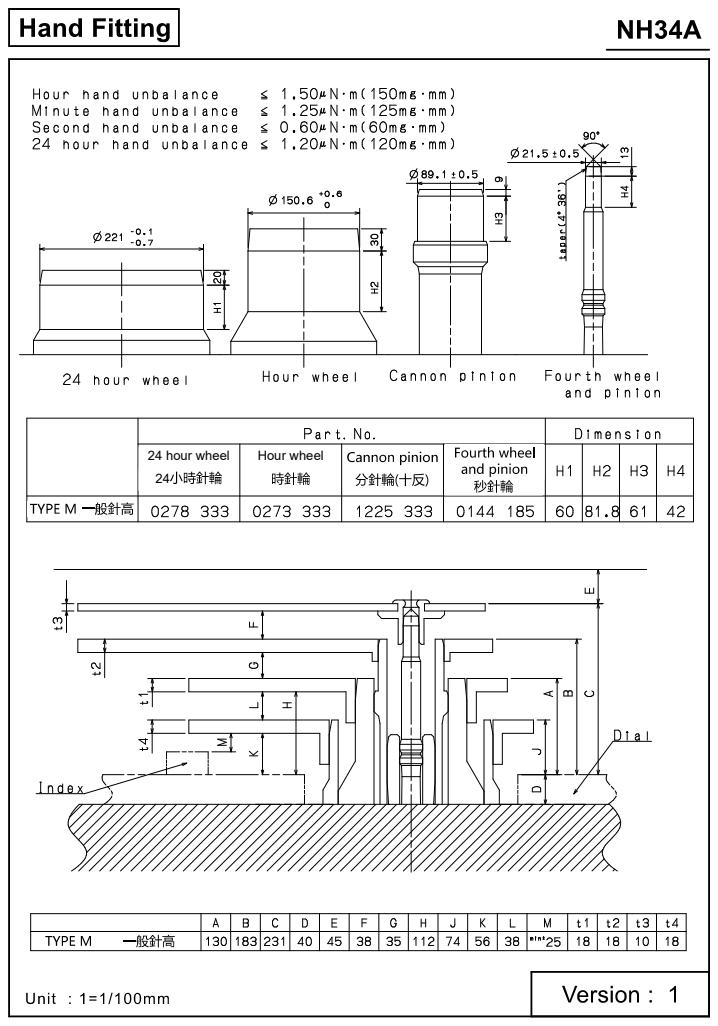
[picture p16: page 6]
24 hour wheel; Hour wheel

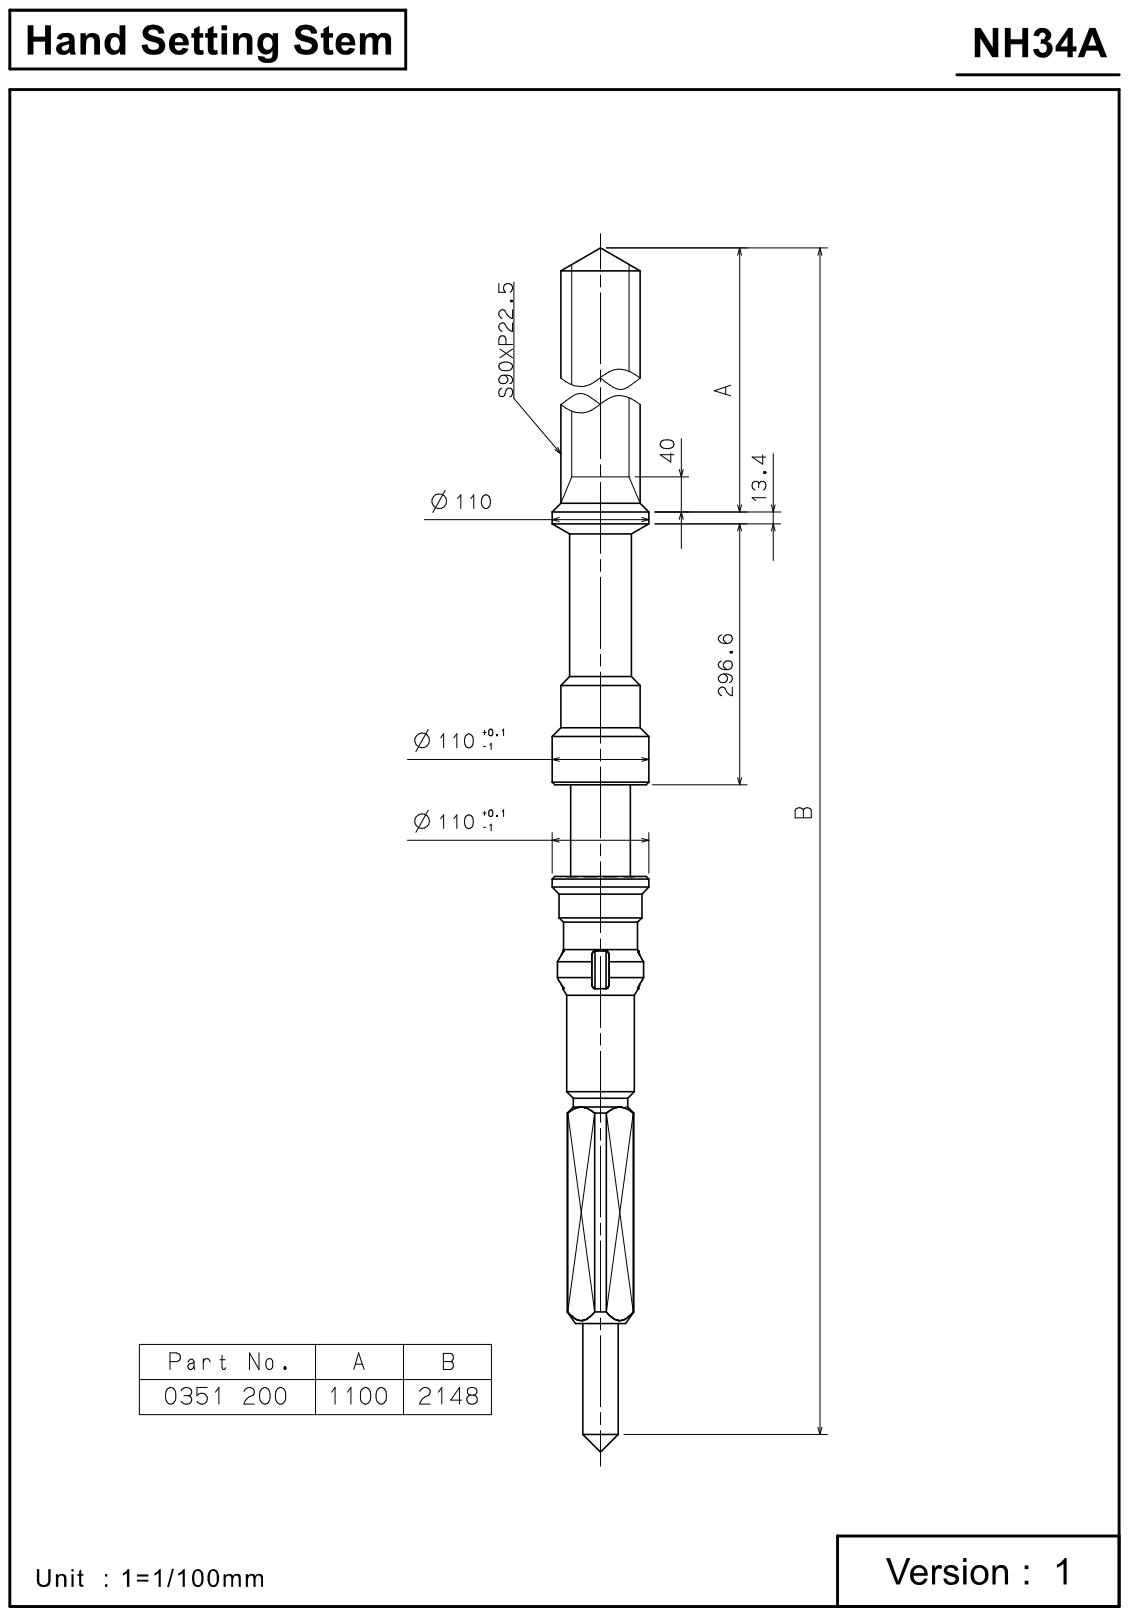
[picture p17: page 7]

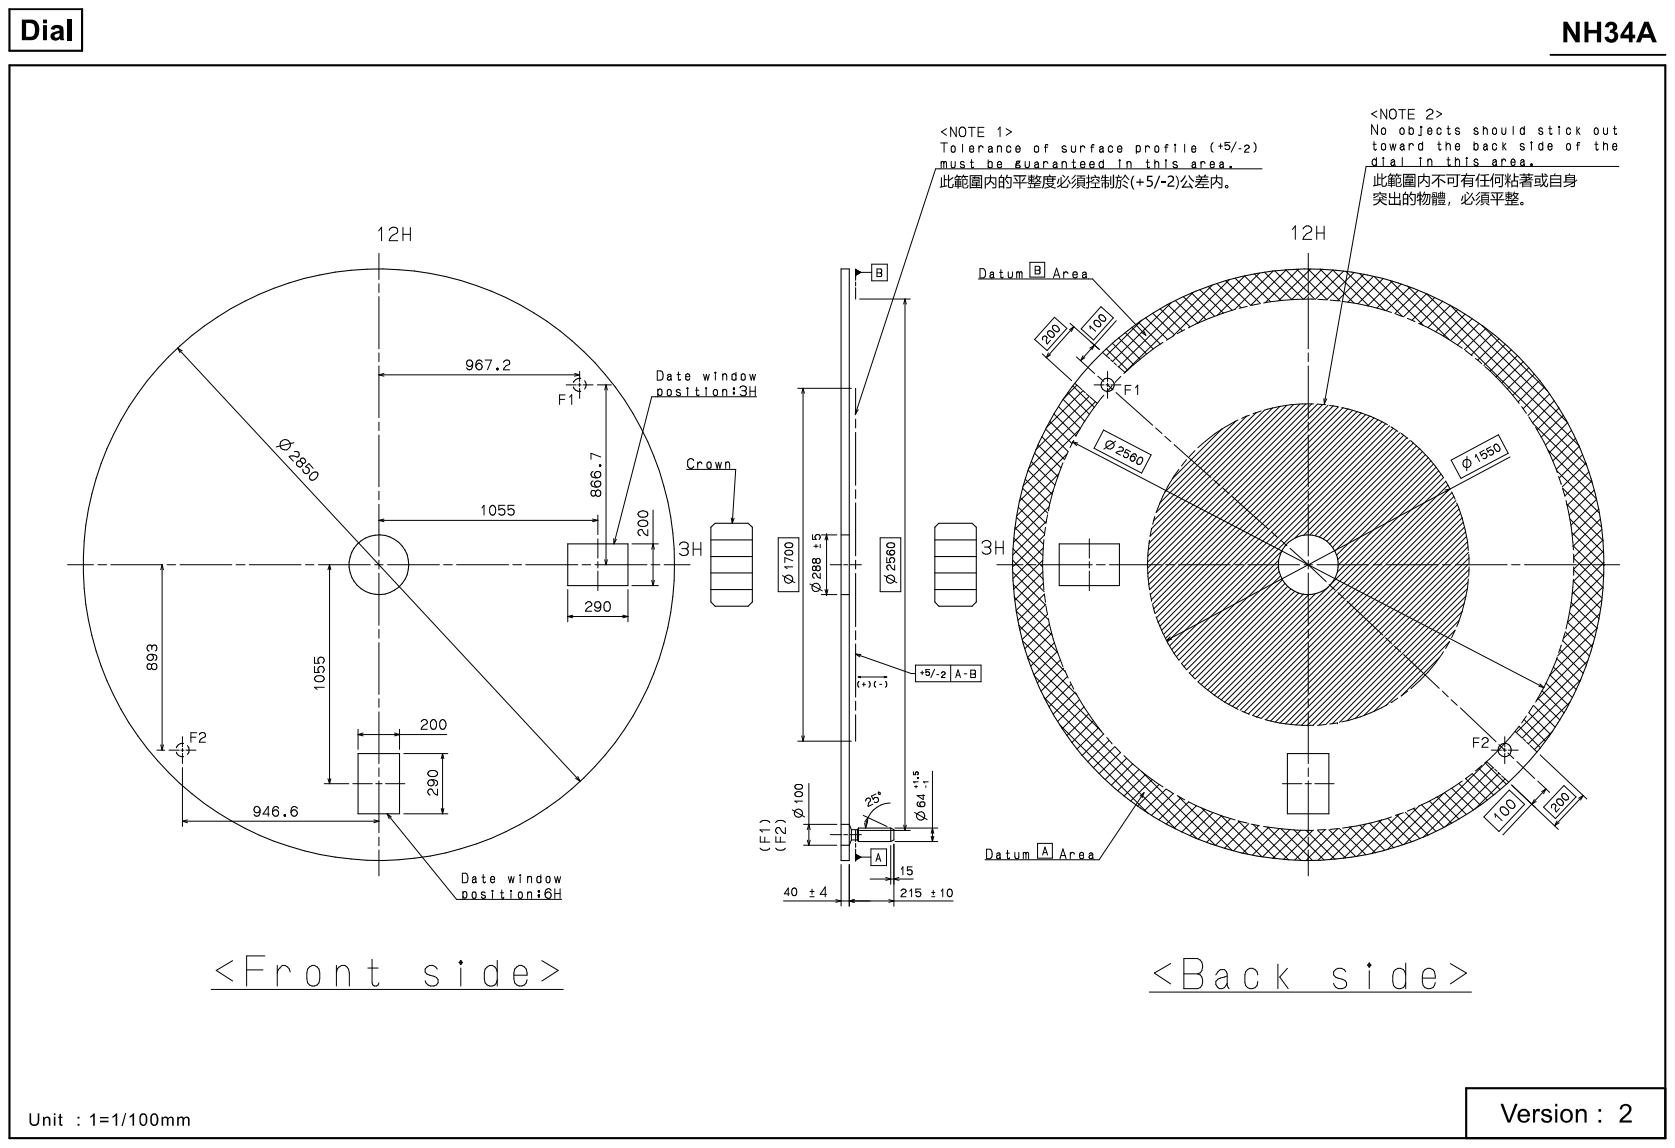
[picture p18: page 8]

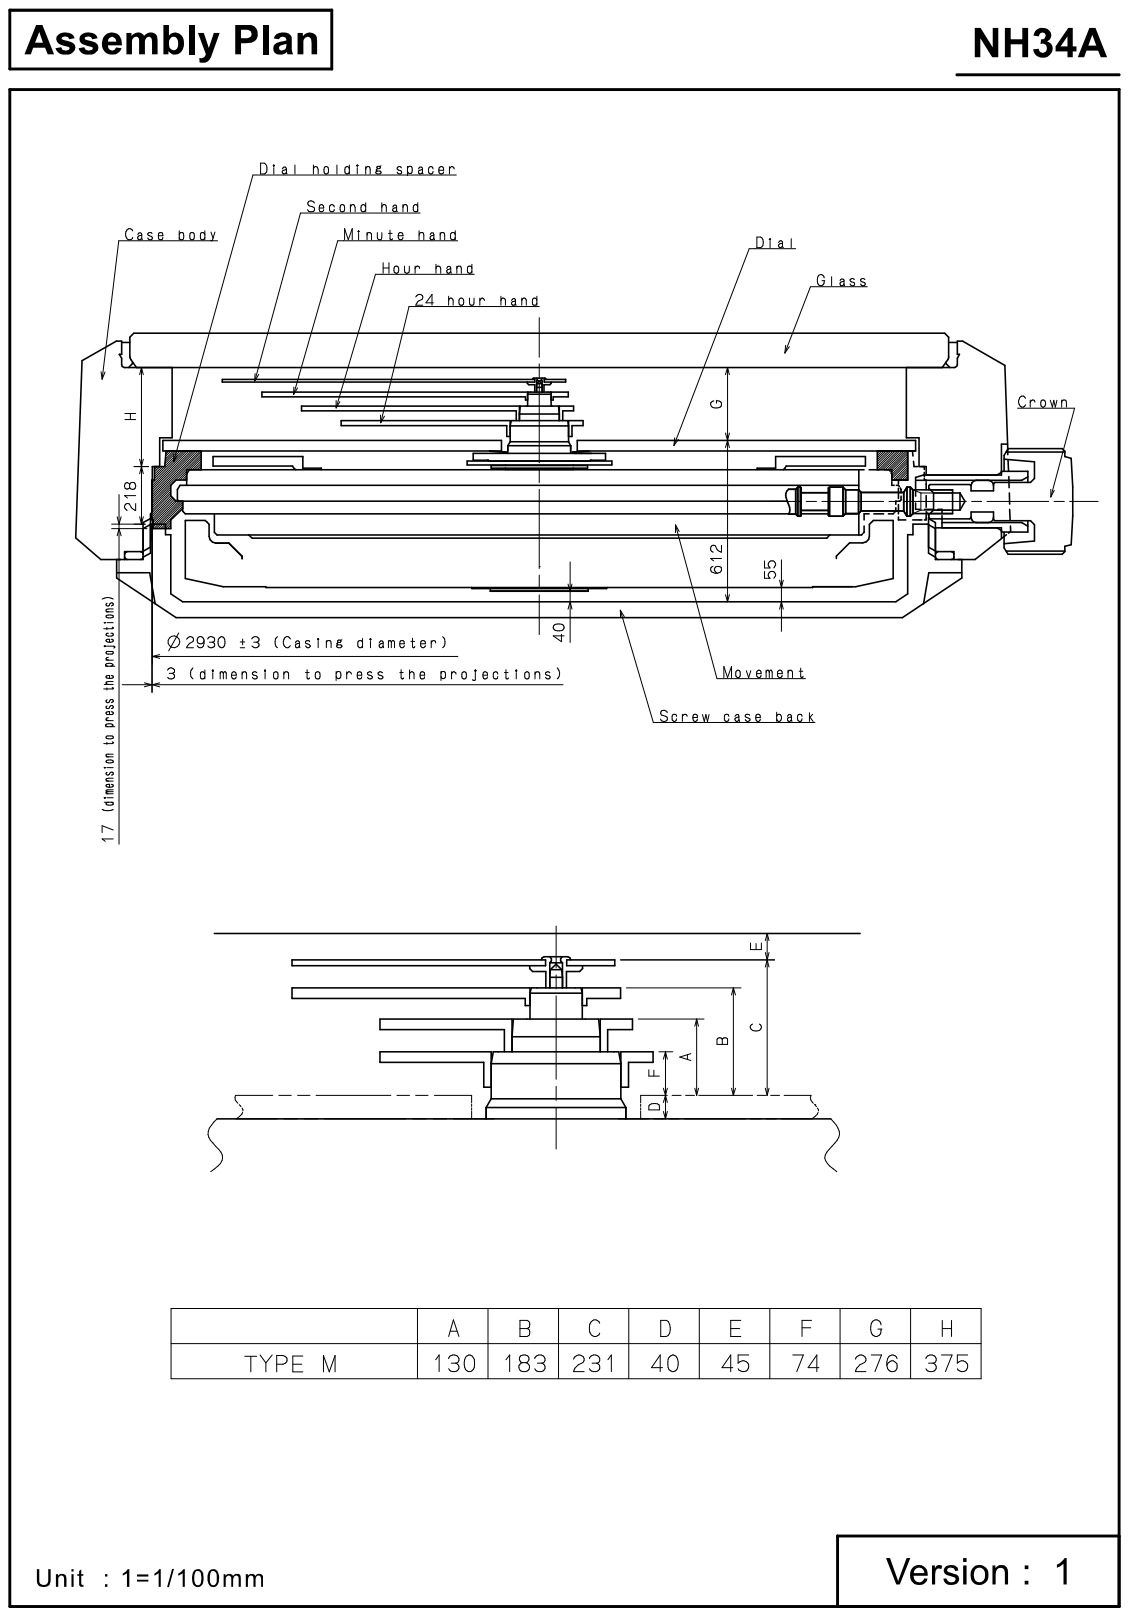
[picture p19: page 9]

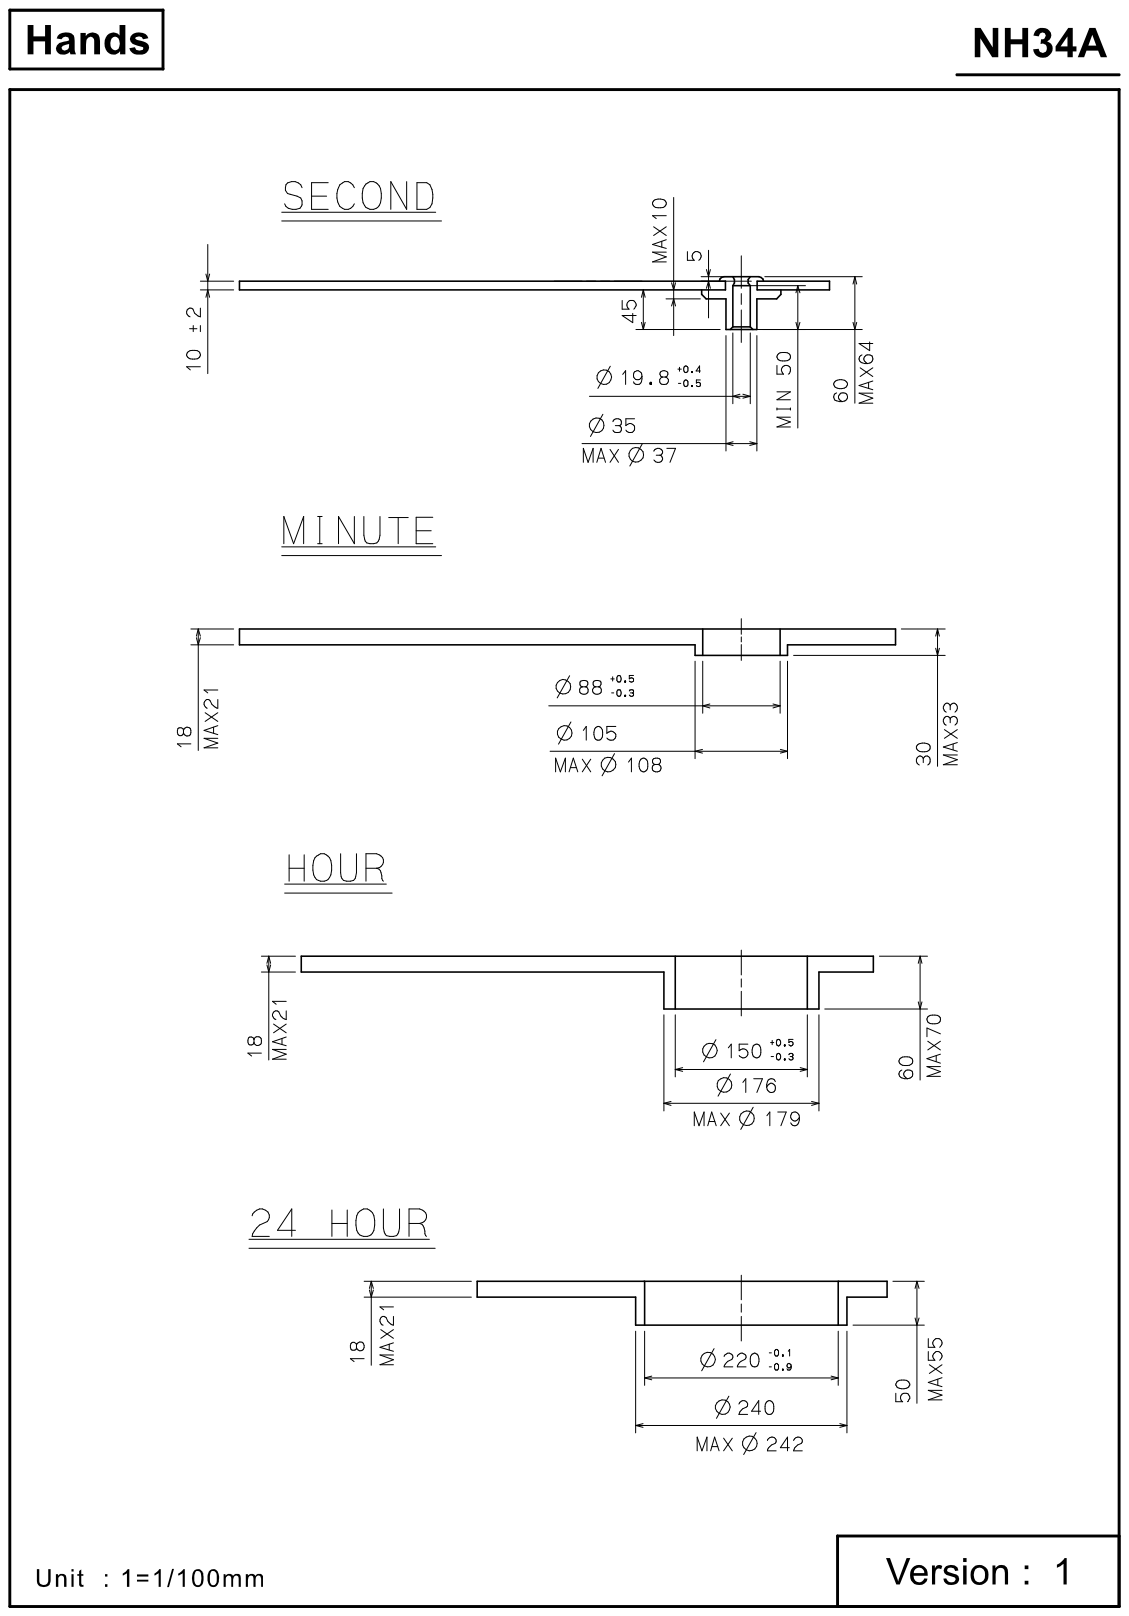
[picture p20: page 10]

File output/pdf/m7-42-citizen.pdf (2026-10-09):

60

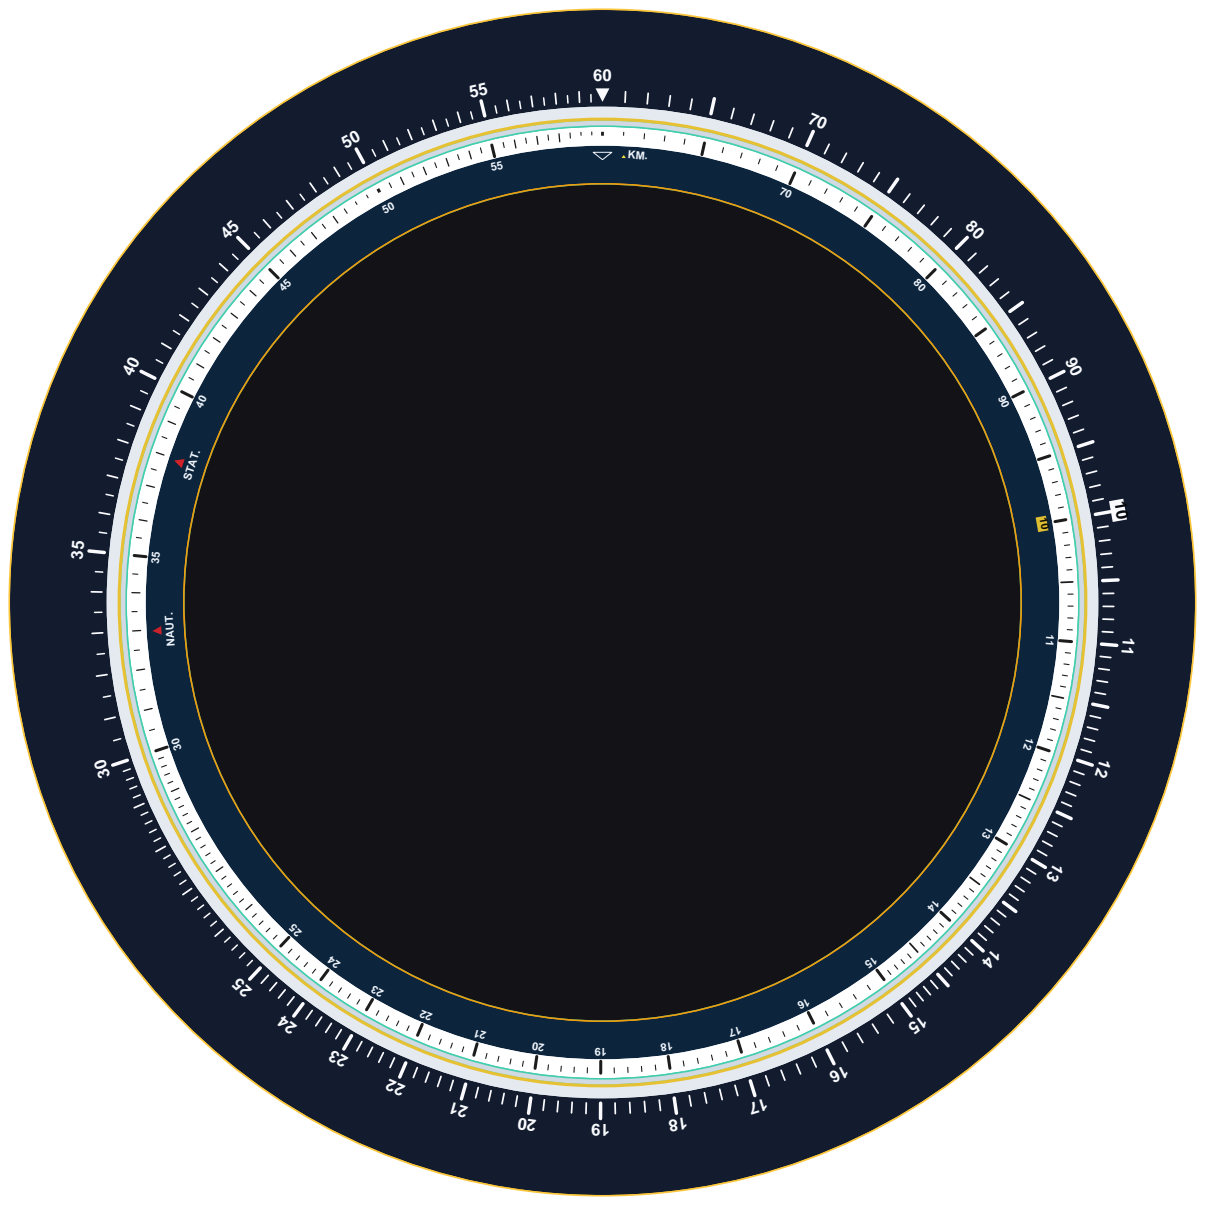
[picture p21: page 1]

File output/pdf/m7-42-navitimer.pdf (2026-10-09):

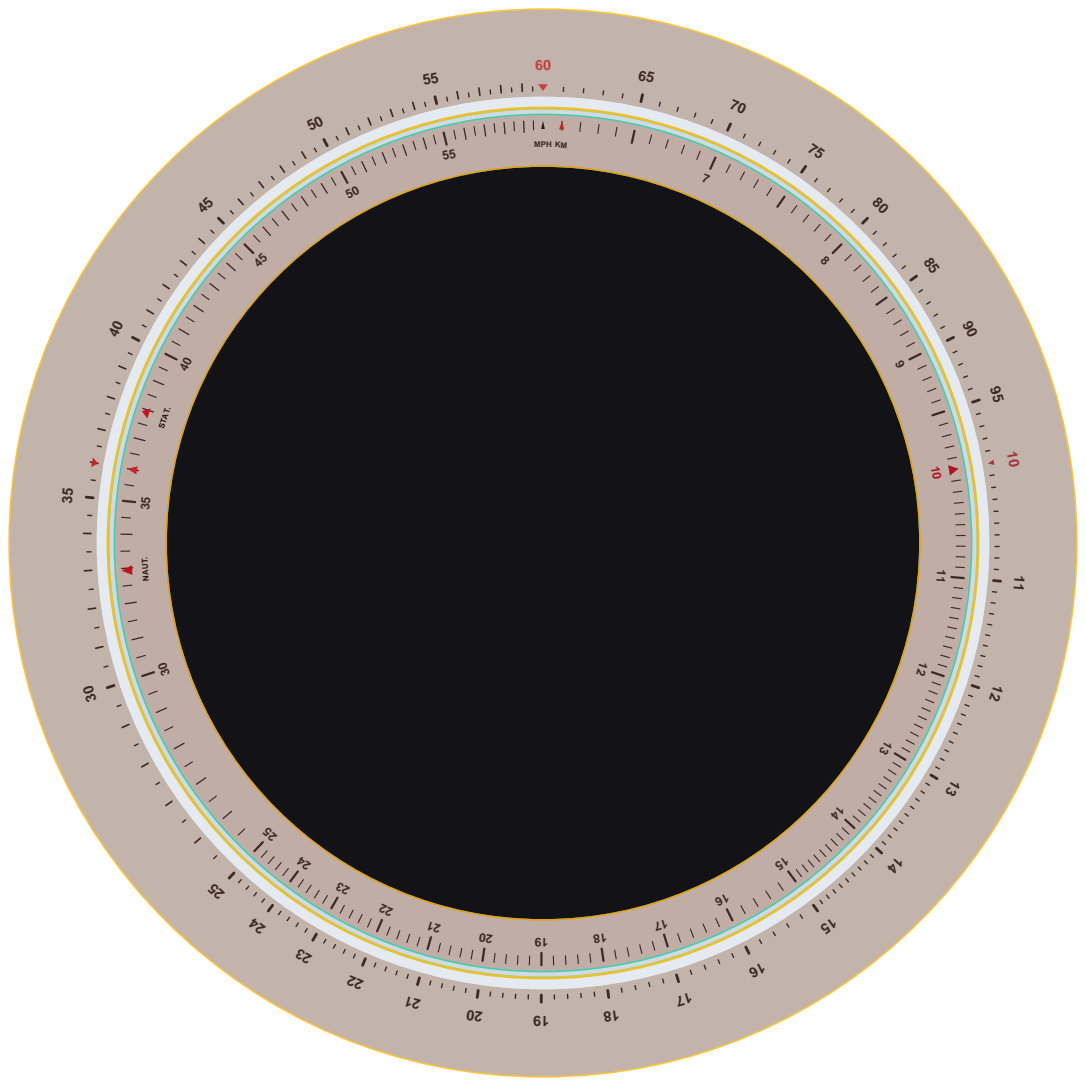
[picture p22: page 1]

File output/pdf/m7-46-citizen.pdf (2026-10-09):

60



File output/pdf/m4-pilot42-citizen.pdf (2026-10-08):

60



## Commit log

2026-08-08 Fix canonical watch assembly geometry
2026-09-10 feat: implement watch assembly management and catalogue
    - Add `WatchAssembly` store and serialization utilities
    - Introduce component catalogue types and registry
    - Update dev server configuration for network accessibility
    - Add component synchronization support to `WatchComponentStore`
2026-09-11 feat: implement semantic hit testing and assembly integration
    Introduced `CanvasHitResult` and `hitTestSemantic` for richer interaction support. Integrated `WatchAssembly` store into the renderer and hydration flow to enable assembly-aware rendering and hit det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
2026-09-11 feat(configurator): implement core configurator UI framework
    Introduce the `ConfiguratorUIStore` and domain types for managing
    design versions, cost calculations, build readiness, and practical
    sensitivities. Integrate new configurator components including the
    navigation rail, tray, and status modals into the main application view.
2026-09-17 feat: add versioned parametric case and hand contracts
2026-09-17 feat: add Blender parametric case generator v1
2026-09-18 feat: add automated Blender case review harness
2026-09-18 feat: componentize 3D assembly and separate parametric crown
2026-09-18 feat: add reviewed 42mm component reference preview
2026-09-18 fix: restore paired case lugs around crown
2026-09-18 feat: add P6 fit evidence gate and strap spacing
2026-09-21 post oost
    post
    [assembly-animated.blend]
2026-09-21 feat: complete NMK901 central-view assembly
2026-09-21 feat: refine production presentation materials
2026-09-22 feat: add parametric lug case library
2026-09-22 fix: integrate case shoulder surfaces
2026-09-22 fix: keep studio backdrop behind assembly
2026-09-23 fix: preserve watch assemblies and repair viewer lifecycle regressions
2026-09-25 feat: complete aviation scale programs and attachment previews
2026-10-04 Add provisional NMK903 case and silver sector dial GLBs
2026-10-05 Wire BOM component Apply to watch views and itemized supplier pricing
2026-10-06 Update small-case strap visuals and support double-click option Apply
2026-10-08 Reconcile Milestone 4 visual and export limitations
    [m4-ladies34-simplified.dxf, m4-pilot42-citizen.dxf, m4-pilot42-navitimer.dxf]
2026-10-09 Implement Milestone 5 custom aviation scales and calculators
    [m5-decimal-hour.dxf, m5-knots-mph.dxf]
2026-10-09 Complete M6 appearance and M7 acceptance repairs
    [m7-42-citizen.dxf, m7-42-navitimer.dxf, m7-46-citizen.dxf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]
2026-10-11 Consolidate case-size slider references and retire obsolete import path
2026-10-14 Refine watch GLB materials and complete six-style realism delivery
